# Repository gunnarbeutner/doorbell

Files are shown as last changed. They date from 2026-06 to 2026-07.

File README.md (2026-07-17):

# Doorbell controller (STR WF26-compatible)

A drop-in smart replacement for a **WF26 handset** on an **STR Elektronik TV20/S**
apartment-intercom bus, built on an ESP32-S3 running ESPHome. To the building it looks like the
handset it replaces; to Home Assistant it looks like a doorbell, an intercom and a door opener.

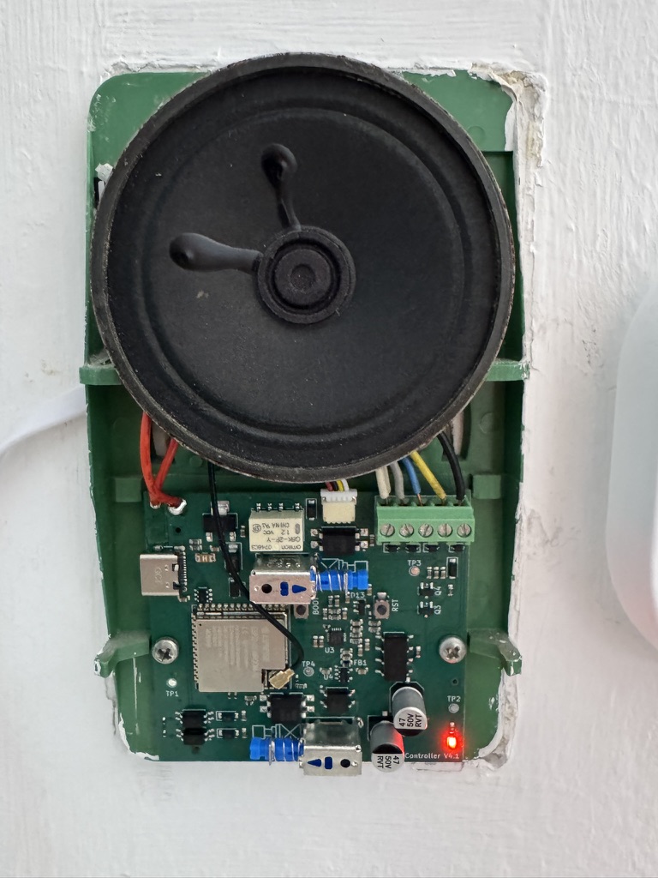
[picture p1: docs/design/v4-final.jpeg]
The doorbell controller installed in the wall


## What it does

- **Ring detection** — the front-door bell (Türruf) and the floor button (Etagenruf) are separate
  HA binary sensors and events: phone notifications, presence-aware automations, "someone rang
  while you were out" history.
- **Gong suppression** — a solid-state switch in the chime path mutes the mechanical gong under
  firmware policy (occupancy, quiet hours, do-not-disturb) without touching ring detection, the
  latch/session, codec audio or the door opener. The current interim policy holds that switch open
  for all of suppression mode so a later neighbour gong on shared line 2 cannot reach LS1; this also
  disables physical LS1 listen/talk until the PTT-capable V4.2 hardware and firmware policy are
  fabricated and validated. The switch is normally-closed: if the smart layer dies, the doorbell
  returns to the stock passive path.
- **Door opener from HA** — with the safety in hardware, not firmware: the door relay pair
  replicates the WF26's break-before-make sequence with an RC delay, and an independent hardware
  watchdog releases the door bridge after ~6.7 s no matter what the firmware does. A crashed ESP
  or a runaway automation cannot hold the door open.
- **Two-way audio** — an ES8311 codec taps the bus speech pair through a protected divider (RX)
  and drives the talk line through the same 2.2 kΩ handshake the central expects from a real
  handset (TX). Push-to-talk from HA; wired for HA's Assist voice pipeline.
- **Fully passive fallback** — the original WF26 relay/switch/speaker core is carried on the
  board, hardwired. Gong, listen, talk and door-open all work with the electronics unpowered;
  the smart layer only ever adds, never gates.
- **Local everything** — ESPHome native HA API, OTA updates, on-device web UI. No cloud.

## How the TV20/S bus works

Five wires run from the central to each flat:

| Line | Role |
|---|---|
| 1 | Common — the reference for everything below |
| 2 | Standing **+12 V supply**, current-limited (~90 Ω source), always on |
| 3 | Speech — talk audio toward the door station |
| 4 | **Türruf** — front-door ring |
| 5 | **Etagenruf** — floor-button ring |

A **ring** is the central putting ~12 V on a ring line for about a second; the gong is literally
the handset's speaker driven from that pulse through a capacitor (the floor line rings the
speaker directly). The line-4 pulse also pulls in a relay inside the handset, which **seals
itself in from line 2** and holds line 4 high — that standing level *is* the "call in progress"
state, and the supply rail sags visibly under its load. **Talk** is a 2.2 kΩ bridge from the
speech line to the supply: the central detects exactly that resistance as "off-hook" and routes
audio, which simply rides on top of the DC. The **door opener** is a plain line 2↔3 contact
closure, sequenced break-before-make so the latch drops first. The central ends every session by
sinking line 2 low after a timeout, which drops all latches. A stock handset contains no
electronics at all — a relay, capacitors, switches and a speaker.

The board senses the ring lines with optocouplers, switches its functions with PhotoMOS relays
in the same places the WF26's mechanical switches sat, and leaves the bus model untouched — the
central cannot tell the difference. The full reverse-engineering lives in `DESIGN.md`, the WF26
handset schematic in `wf26/`, and real-bus scope captures in `captures/` — all usable on their
own if you have this intercom family and only want ring detection or muting.

## Beyond the assembled board

The JLCPCB-assembled PCB needs four things it doesn't ship with:

- **Antenna** — the ESP32-S3-WROOM-**1U** has no PCB antenna; any 2.4 GHz u.FL/IPEX antenna
  works (a flex-PCB patch routes nicely out of the enclosure).
- **Speaker/mic transducer (LS1)** — a 16 Ω transducer soldered to the LS1 wire pads. It is the
  gong, the passive listen earpiece and the passive talk mic in one; deliberately not
  board-assembled.
- **JST SH-4 male pigtail for J1** (the deployed power/service inlet) — a pre-crimped SH-4 lead is strongly
  recommended; hand-crimping 1 mm SH contacts is misery.
- **USB power/service lead** — a four-signal USB-A male screw-terminal breakout wired to the J1
  pigtail. Keep D+/D− short and twisted, and verify every conductor before first power-up:
  `docs/design/usb-jst-j1-wiring.svg`.

**Status:** the V4.1 board (JLCPCB-fabbed and -assembled) is bench-verified and deployed —
installed in the wall in place of the WF26, running `firmware/doorbell.yaml`. The smart layer
is powered by a USB wall-wart through its J3 connector; the TV20/S bus powers only the passive
handset core, so the electronics draw nothing from the shared intercom supply. The installed V4.1
USB-C connector mechanically prevents the housing's Talk actuator from fully engaging SW4; the
current V4.2 candidate removes that connector and adds a dry GPIO47 physical-Talk input plus a
mechanical K1 inhibit on SW4's spare pole. Those changed circuits are not field-proven and must pass
the full actuator/cable fit and first-board electrical/timing gates.

## Repository layout

The **KiCad files** (`kicad/doorbell.kicad_sch` / `.kicad_pcb`) are the authoritative source for
the board — edited directly in KiCad. `./build.sh` verifies them and exports the
fab outputs; it does not author or regenerate the board.

| Path | What |
|---|---|
| `REQUIREMENTS.md` | *What* the board must do — functional + safety requirements (start here for intent). |
| `DESIGN.md` | *How* it's built — architecture, GPIO map, relays/SSRs, audio path, bus model. |
| `VERIFICATION.md` | Design-verification gates plus the bench bring-up / commissioning record. |
| `ORDERING.md` | JLCPCB ordering notes (Standard PCBA workflow + the review gates). |
| `kicad/` | Authoritative KiCad project (`doorbell.kicad_sch` / `.kicad_pcb`). See `kicad/README.md`. |
| `tools/` | Build/inspection Python scripts (placement check, routing verify, STEP/BOM/CPL export). |
| `firmware/` | ESPHome configs — `doorbell.yaml` (deployed), `doorbell-bench.yaml` (bench twin: debug SSR switches, audio loopback instrumentation, no HA events), `doorbell-tonegen.yaml` (spare board as bench tone source / HA media player). |
| `sim/` | Node circuit simulator + PCB viewer used to sanity-check the design (`cd sim`; `npm test`). |
| `wf26/` | Reverse-engineered WF26 handset (`wf26.kicad_sch`). |
| `captures/` | Bench scope captures of the real TV20/S (ring, door-open, timeout) + web viewer. |
| `docs/` | Datasheets and reference docs (`datasheets/`, `design/`, `ordering/`) — incl. the wall wire-up map (`design/wall-wiring-v4.svg`) and the J1 power/service-cable pinout (`design/usb-jst-j1-wiring.svg`). |
| `fab/` | Generated fab outputs (Gerbers, drill, BOM, CPL, STEP) — produced by `./build.sh`. |
| `orders/` | Shipped fabrication order archives. |

## Build

```bash
./build.sh             # verify (ERC/DRC/placement/routing/simulation) + export fab outputs
./build.sh verify      # run the same checks without updating generated artifacts
```

See `kicad/README.md` for the build pipeline details.

## Firmware

```bash
cd firmware
esphome run doorbell.yaml    # needs firmware/secrets.yaml (see below)
```

Secrets (WiFi credentials, API encryption key, OTA password) live in `firmware/secrets.yaml`,
which is gitignored — create it with `wifi_ssid`, `wifi_password`, `api_encryption_key` and
`ota_password` before building. Run `esphome clean` after switching configs or renaming a device
— a stale build directory fails the build in confusing ways.

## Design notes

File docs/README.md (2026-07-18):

# Datasheets & reference docs

Local copies of the primary sources behind the design, so the references don't rot. The
**authoritative part list is the schematic** (`kicad/doorbell.kicad_sch`, hidden `LCSC`/`MPN`
fields) exported to `fab/doorbell-bom-jlcpcb.csv` — this folder is not a BOM, just the
backing documents. For *how* to use them to check the board, see `../VERIFICATION.md`.

## Layout

- **`datasheets/`** — component datasheets for the parts on the board.
- **`design/`** — intercom/handset reference docs, ESP32 design guides, the Fritzing source.
- **`ordering/`** — JLCPCB capability PDFs and the prefab verification report.
- **`verification/`** — revision-specific bench/field evidence and review dispositions. These are
  historical records; the revision-neutral pre-fab procedure remains `../VERIFICATION.md`.

## Intercom & handset (in `design/`)

| File | What |
|---|---|
| `STR_TV20S_Schaltplan_Fehlersuchhilfe.pdf` | STR TV20/S service plan — Verdrahtungsplan + Fehlersuchhilfe. The authority for the bus (terminal 4 = Türruf ≈ 12 VDC, ÖT bridges 2 & 3, ET interrupts line 5). |
| `HJR4102.PDF` | HJR-4102 — the WF26's own latch relay (the part the on-board G6K replica reproduces). |
| `KlingelV4.fzz` | Fritzing source for the V3 perfboard build / early V4 reference. |

## Current-design part datasheets (in `datasheets/`)

For the parts on the board: the **ESP32-S3-WROOM-1U-N16R8** module (`esp32-s3-wroom-1_wroom-1u_datasheet_en.pdf`,
pad map + strapping), **ES8311** codec (`ES8311_datasheet.pdf` + `ES8311.user.Guide.pdf`),
**SGM2212** LDO (`sgm2212_datasheet.pdf`), **TPD2S017** USB ESD (`tpd2s017_datasheet.pdf`),
**Omron G6K** relay (`g6k_datasheet.pdf`), **SUPSiC GAQY412E/EH** PhotoMOS
(`GAQY412E_EH_datasheet.pdf`), the **SPPJ322300** door switch (`SPPJ322300_datasheet.pdf`), the
**AO3400A** door/watchdog FETs (`ao3400a_datasheet.pdf`), and the **LMBR01S30ST5G** codec-clamp and
AVDD reverse-blocking Schottky (`lmbr01s30st5g_datasheet.pdf`). The exact polarised crossover
capacitor is Panasonic **EEEFK1H220P** (`eeefk1h220p_datasheet.pdf`), and K5's exact flyback/clamp is
R+O / Zhuhai Hongjiacheng **1N4004W** (`1n4004w_datasheet.pdf`).

Local sheets also cover the **SS14**, **SMF5.0A**, **1N4148W**, **SM04B-SRSS-TB JST-SH** connector,
and **GAQW212GS/GAQY212GS** SSRs. Not every commodity resistor or MLCC sheet is archived; use the
exact schematic BOM/LCSC entry rather than inferring an ordered part from this directory.

`usb4105_datasheet.pdf` is retained only as historical backing for the V4.1 J1 USB-C receptacle; it
does not describe a current V4.2 part and is not a BOM source.

## Fab capability (in `ordering/`)

`PCB Manufacturing & Assembly Capabilities - JLCPCB.pdf` and `… - JLCPCB - PCBA.pdf` — JLCPCB's
published PCB/PCBA capability limits (clearances, assembly rules), the basis for the DRU and the
ordering notes in `../ORDERING.md`.

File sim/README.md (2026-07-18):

# sim — schematic-driven circuit simulator

A transient circuit simulator with a browser PCB view. It **imports** `kicad/doorbell.kicad_sch`
and **simulates each component by a type-based model**. Nothing is baked: the netlist is read from
the KiCad files on demand.

## Use

```sh
cd sim
npm run dev      # incrementally builds host firmware, then serves http://localhost:8080
npm test         # all required circuit + firmware/HEAD tests
npm run test:circuit  # circuit-only tests against the live schematic
npm run test:firmware # deterministic ESPHome-host + live-HEAD circuit co-simulation
npm run test:firmware:scenarios # fastest rerun after config/build; scenarios only
npm run check:tv20s-calibration # verify evidence hashes and captured DC envelopes
npm run test:monte-carlo -- 1592639710 250  # optional seeded watchdog sensitivity diagnostic
```

`npm run dev` must finish the incremental `doorbell-host.yaml` build before the server listens. It
re-imports automatically when a `.kicad_sch` / `.kicad_pcb` changes — just reload. Importing needs
`kicad-cli` on `PATH` (KiCad's CLI; used for net connectivity).

There is deliberately no firmware/no-firmware mode. A `doorbell` browser session always gets its own
server worker, host firmware process, virtual clock, preferences directory and live HEAD circuit.
Both `doorbell` and `wf26` default to a synthetic, capture-calibrated TV20/S terminal model; select
`manual circuit lab` when arbitrary sources and components are needed. The `wf26` board remains a
passive reference-handset circuit with no MCU in either environment. Closing an idle browser session
releases its worker and firmware process; abandoned sessions expire server-side.

The page is a 3-column PCB view: `[controls + layer toggles + time cursor] | [selected copper layers,
stacked] | [scopes]`. In the default TV20/S environment, use the own-ring, neighbour-ring, floor-call,
neighbour-door and timeout controls. The model owns P1–P5 and composes the selected endpoint with a
second live-imported WF26 endpoint for the neighbour. In the manual lab, add **Sources** (drive any net with
DC/sine/square/step/pulse — each has an on/off toggle, off = the net floats, and an editable Thevenin
source impedance). Both environments use pause, 1×, 10×, maximum-speed or the 1 ms single-step. Ideal
sources on the same net conflict, and a source attached to a firmware-owned U1/U3 output must have
non-zero impedance. **Hover**
a trace → its net's voltage; **click** a trace → a scope on the right; the time-cursor slider scrubs the
instant shown on the board and the scope cursors. Colour is by voltage (fixed 0–Vmax scale) or by net.
Inner planes (In1/In2) show vias/pads only — zone fills aren't extracted yet.

## Layout

- `src/import.js` — KiCad → netlist object (node; shells out to `kicad-cli`, parses the `.kicad_sch` /
  `.kicad_pcb`, including MPN/LCSC/datasheet fields). Replaces the old `build.py`.
- `src/engine.js` — the simulation core (MNA transient solver); shared by session workers and tests.
- `src/corners.js` — fitted-part limits, explicit engineering assumptions and named deterministic corners.
- `src/ui.js` + `index.html` — remote browser front-end; renders server samples and submits controls but
  never creates an electrical stepper or manually programs U1/U3.
- `src/session-worker.js` — isolated per-browser circuit owner, virtual-time pacer, safety monitor and
  host-process lifecycle manager. Doorbell sessions reuse the deterministic firmware-test runner;
  WF26 sessions run the same TV20/S terminal environment around their passive circuit, or the manual
  lab when selected.
- `src/tv20s/` — captured-evidence manifest, terminal-equivalent calibration and the synthetic
  TV20/S state machine. Unsupported compositions throw with the missing evidence they require.
- `server.js` — HTTP/SSE session API, live KiCad import and static dev server (`npm run dev`).
- `test/` — integration tests + model-coverage and deterministic-corner gates (`npm run test:circuit`).
- `firmware-test/` — sequential host-firmware/circuit scenarios (`npm run test:firmware`).
- `diagnostics/` — optional seeded sensitivity tools; these supplement rather than replace the
  deterministic safety gates.

## How components are modeled (by type)

Each device type is a **class in `src/components/`** (one file each: `Resistor`, `Diode`, `Mosfet`,
`Optocoupler`, `Transformer`, `Relay`, `Switch`, `SolderBridge`, `EsdArray`, `Ldo`, … + `Connector`/
`TestPoint` ports and an `Unmodeled` fallback). A class exposes:

- `static compatible(symbol)` — does this class model the part? It inspects the symbol's `lib_id`
  (library category / part name) and pin functions — **not** the reference designator. So a part is
  modeled by what it *is*, even if its refdes breaks convention (e.g. `D5`, an ESD array, is matched by
  `EsdArray`, not `Diode`).
- `elements(ctx)` — the simulation elements it contributes (with its own parameters: a diode's Is/n by
  family, a 2N7002's vth/Rds, a relay's coil R + pull-in, the transformer's L/k/Rdc, …).

The registry (`src/components/index.js`) tries the classes most-specific-first and instantiates the first
match (or `Unmodeled` → shown red). The importer no longer classifies anything; it just emits raw
components (ref, lib, value, footprint, pins, pinfn and exact-part metadata).

**Nominal device parameters are per-part** — derived from each component's part type/value:
diode Vf class by family (silicon `1N4148` ≈ 0.65 V, Schottky `SS14` ≈ 0.3–0.4 V, visible LED ≈ 1.9 V,
TVS by type: unidirectional forward-only, bidirectional anti-series with a standoff `vbr`, open across the
bus range); MOSFET `vth`/`Rds(on)` by part (`2N7002`); optocoupler LED + guaranteed CTR
(`TLP293` GB rank);
transformer winding `L`/`k`/`Rdc` by part (`SM-LP-5001`: Rdc 115 Ω); relay coil resistance, pull-in,
operate/release time and contact resistance from the fitted part.

Qualification tests may pass strict per-reference overrides to `buildElements(..., { params })`.
Every override must match a live schematic reference and a parameter that its model consumes; unknown
or misspelled values fail instead of silently running nominal. The returned element list records the
resolved nominal/override pairs in `resolvedParams` for auditability.

- **Auto-modeled from value + refdes:** R, C (including tolerance/effective-value overrides and optional
  capacitor leakage; polarized caps, `Device:C_Polarized` etc., are flagged in the
  status bar if they're ever reverse-biased — pin 1 = +), L, diode (KiCad `Device:D`: pin 1 = cathode, pin 2 = anode),
  speaker (→ R), fitted 0466 fuse (→ 75 mΩ + 0.0423 A²s melting model whose blown state remains
  latched across seeded scenario changes), **optocoupler** (standard 4-pin: LED diode 1→2 + CTR/dark-current source
  4→3 with a saturation clamp), **MOSFET/transistor** (gate-controlled switch, using the symbol's
  `G/D/S` pin functions), **regulator/LDO** (an IC with `VIN/VOUT/GND` pin functions → regulated
  output, floored at 0; target voltage parsed from the output net name, e.g. `+3V3` → 3.3 V; draws its
  output current back out of the input pin so the input rail loads down rather than supplying free power,
  and operates as a one-quadrant source only while VIN has dropout headroom — it neither back-drives a
  dead input nor sinks an externally overdriven output; pull the supply and the board de-energizes
  instead of running forever off a charged cap), **transformer** (two coupled inductors + series winding Rdc),
  **ESD/TVS protection array** (e.g. `TPD2S017`: each channel passes IN↔OUT, with steering diodes that
  clamp the line to VCC/GND and a ~6 V VCC↔GND rail clamp — so a realistic surge through a source
  impedance clamps to ≈ VCC + Vf; an ideal 0 Ω source can't be clamped, as in reality).
- **Relays & switches** — pin-outs are **hard-coded per part type** (keyed on the symbol `lib_id`):
  Omron `G6K-2F` relay → coil 1/8, contacts COM3/NC2/NO4 + COM6/NC7/NO5; `SPPJ322300` DPDT switch →
  COM2/NC3/NO1 + COM5/NC6/NO4; tactile button → SPST 1–2; **solder bridges** (`SolderJumper`) → SPST,
  closed by default. **Relays are coil-driven** (energized when |V_coil| ≥ ~75 % of the rated coil
  voltage, with datasheet operate/release delay — drive the coil/gate to trigger; read-only state badge).
  **PhotoMOS outputs likewise use operate/recovery current and voltage hysteresis plus switching delay.**
  **Switches & solder bridges** toggle
  manually. No configuration UI.
- **ICs (ESP32, codec) — supply current (+ codec VMID):** generic digital I/O (I2S, USB and internal
  behavior) is **not** modeled, so they still render **red**; but their power draw
  *is* — each is an equivalent resistive load (`Ic`) from its supply pin to GND at a representative active
  current (ESP32 ~100 mA, ES8311 ~10 mA), which pulls through the LDO → +5V → Schottky → VBUS. The one
  analog exception: the ES8311's **VMID reference** (≈ AVDD/2) is modeled, because the mic front-end's
  divider/bias depends on it. In a doorbell session the host firmware exclusively supplies U1's four
  modeled output drivers and U3's bounded representative codec output; there are no manual IC controls.
- **Floating vs 0 V:** nets with no DC-conductive path to ground or a source are flagged **floating**
  (dashed grey on the board, "(floating)" in the tooltip) — distinct from a real 0 V net.

## Engine

Modified Nodal Analysis, Backward-Euler transient, Newton iteration (SPICE-style relative+absolute
convergence with damping for the per-part diode/opto models, all in `src/engine.js` (no DOM, importable
by the tests). A nonlinear solve that exhausts its iteration limit throws with the time, worst node and
voltage delta; it is never silently accepted. `src/import.js` produces the netlist; `src/ui.js` is the
browser front-end.

## Qualification corners

`src/corners.js` separates guaranteed fitted-part limits from named engineering bounds. Permanent tests
cover the watchdog fast/nominal/slow envelope, break-before-make timing, PhotoMOS drive and switching
delay, K5/K6 interlock and GPIO pin faults, powered boot/brownout fallback, dynamic fuse isolation,
bounded bus faults, LDO passivity, optocoupler CTR/dark current, the supply monitor, RX/TX voice-band
gain, captured-waveform replay, the welded-K1 door discriminator, timestep refinement and convergence
failure. The compact replay fixtures under `test-support/fixtures/` record the exact source capture and time
window from which they were decimated. The timing-MLCC 0.65–1.10 effective-capacitance scale
and the K6 temperature guard are explicitly labelled engineering assumptions because the vendors expose
typical curves rather than guaranteed production extrema.

`npm run test:monte-carlo -- <seed> <samples>` explores uniformly sampled interior watchdog values and
prints its seed plus fastest/slowest samples. It must stay inside the deterministic extremes, but it is a
diagnostic only: reproducible named extremes, not random coverage, are the release gate.

## Scope / limits

Validates **design intent and the explicitly modeled fitted-part envelope** — loading/impedance, RC time
constants, sense thresholds and switch topology. The TV20/S environment additionally reproduces the
captured idle/session/timeout terminal bias, own and one-neighbour ring/gong, floor call, direct door
bridge and recovery. A direct door bridge during the local endpoint's own gong composes those same
calibrated terminal equivalents, allowing the production auto-open timing to run without a special
DUT assumption. The documented 2.2 kΩ Talk handshake is supported as a terminal state, but the
TV20/S audio gain and remote acoustic path are not synthesized. It deliberately rejects other
intermediate P2–P3 impedances, multiple neighbours, overlapping bell types, door actions during a
neighbour/foreign gong and central-unit/opener-terminal faults; those need new evidence, not guessed
behavior. During stock WF26
Talk, `R1_BRIDGE` is connected to P3 on the low side of R1, so the terminal-equivalent model puts it
near 1 V while P4 retains the approximately 9.4 V session bias. This is not the main board's
`TALK_BRIDGE`: K1 holds that node directly at P2, with `TX_OUT`/P3 on the low side of R28. It still
does not predict semiconductor analog behavior
with SPICE precision, derive unguaranteed temperature/DC-bias distributions, model EMI, contact bounce,
PCB parasitics or fabrication variation. Seeded sampling cannot turn an engineering bound into a vendor
guarantee; first-board measurements remain required where `VERIFICATION.md` says so.

## Firmware/HEAD co-simulation

`./build.sh firmware-test` is the narrow firmware gate. It resolves the production and bench YAML,
incrementally builds `firmware/doorbell-host.yaml`, then starts a fresh host process, Unix socket and
preferences directory for every scenario. Production remains the installed V4.1 adapter; the host
adapter enables the expected HEAD/V4.2 K5-confirmed P4 isolation, physical-Talk hand-off and serialized
door-command/re-arm policy. Its candidate manual-conversation policy keeps K3 passive for up to 30 s
after physical-Talk release while K5 remains confirmed; K5 loss, smart TX or a door request ends that
window sooner. These behaviors are gating host scenarios without claiming that the changed functions
have passed fabricated-board tests.

The live KiCad import and passive powered-state operating point are cached only within one Node test process;
every scenario still gets a fresh firmware process, socket, preferences directory and independent copy
of the settled electrical state. The runner solves the DC target directly (capacitors open, inductors at
DC, discrete devices iterated to a stable topology), follows topology and waveform transients at
fine/medium/coarse steps, and jumps an interval only when live storage and discrete state agree with that
operating point within the solver tolerances. Numerical step horizons select resolution; they do not
declare a static circuit settled. The deliberately bounded representative codec waveform remains a
separate policy-test abstraction; after its documented exercise window, the remaining media duration
advances as policy-only time. Long greetings and timeout tests therefore retain virtual-time coverage
without repeatedly solving an unchanged nonlinear circuit.

`npm run test:firmware` remains the self-contained direct gate: it resolves production/bench and
incrementally builds the host target. After those inputs are already known-good, use
`npm run test:firmware:scenarios` for the shortest edit/rerun loop; `./build.sh firmware-test` performs
the validation/build itself and then uses that scenarios-only command, avoiding duplicate work.

The host binary replaces the stock host wall-clock and wake HAL with a 64-bit simulator-controlled
clock. `millis()` intentionally exposes its low 32 bits. Firmware and circuit exchange protocol-v1
newline messages over the per-test socket: firmware sends `HELLO`, ordered `WRITE`, `MEDIA`, `EMIT`
and `ADVANCE`; the runner replies with `AT` containing virtual time, raw input mask, ADC millivolts,
stop reason and queued commands. A version/mapping error, nonlinear-solver failure or stable voltage
in the ESP32 indeterminate region fails the scenario. Short analog transitions retain the previous
Schmitt state for at most 20 ms; remaining in the undefined band after that fails with net and voltage.

The runner imports `kicad/doorbell.kicad_sch` at runtime and checks U1 plus P1–P5 during handshake.
P2/P4/P5 DC, tone, pulse and captured-waveform sources use the measured nominal 90 Ω source
impedance. It carries capacitor, relay, SSR,
fuse and regulator state across adaptive timestep rebuilds, uses fine steps around topology/input
edges, and retries a hard source/clamp transition on a bounded smaller-timestep ladder before reporting
strict nonlinear non-convergence. A non-interactive host exit can remove U1 program drivers to model
reset/power loss. The fake media player derives duration
from each embedded WAV's actual metadata and drives U3 with a bounded representative tone while it is
active. Failures print a compact ordered timeline; detailed exploratory traces are not committed.

This fixture validates the electrical contract at the connector and firmware-observable HEAD nets. Its
TV20/S terminal model is tied to the named capture files and their recorded channel confidence; it is
not a model of unobserved central-unit internals, a substitute for the remaining real-bus checks, or
validation of a fabricated V4.2 board.

### Interactive virtual time

The interactive UI uses the same protocol and HEAD fixture. The server is the sole authority for
circuit state and ordered firmware writes. At 1×/10× it advances a wall-time-derived virtual horizon;
`max` advances bounded chunks as quickly as the solver and host scheduler permit. Pause leaves the
host blocked in `ADVANCE`, and `+1 ms` advances exactly one virtual millisecond. Firmware commands,
TV20/S stimuli and circuit/source edits made while paused are queued at the frozen boundary; repeated
lab-circuit edits collapse to the final configuration and are applied only by `+1 ms` or resume. Until
then the complete published snapshot—including voltages, storage state, environment state and floating
classification—remains unchanged. Full reset starts a clean circuit, host and preferences set.
**Freeze firmware** stops host execution while retaining the last U1/U3 GPIO and peripheral drive,
modeling a wedged MCU. The physical circuit continues in virtual time: in particular, a frozen-high
`DOOR_DRV` remains high while the independent Q3/RC watchdog releases K2. Reboot resets the program
outputs and starts a new host process at the same circuit time without resetting capacitor, relay, SSR
or fuse state.

Every source, extra element and switch edit is validated in the worker and rebuilt at its permitted
virtual-time boundary while carrying physical state. HTTP action completion acknowledges worker
completion, so pause/configure ordering does not depend on wall-clock timing. Samples, current injections,
safety events, firmware entities, media ownership and the ordered write timeline stream back over SSE.
The UI keeps a bounded display window; detailed deterministic assertions remain the job of
`npm run test:firmware`.

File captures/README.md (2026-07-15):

# captures — Rigol DHO804 capture tooling

Pull waveforms off the bench scope (`osci.beutner.name`) over WiFi and save them — one
**CSV (full true voltages) + WAV (extracted audio) per channel** — so the 3-Klang-Gong
on the bus (and anything else) can be analyzed and listened to.

Built on **[pydho800](https://github.com/MasterJubei/pydho800)** / `pylabdevs`, which talks
to the scope over its raw SCPI socket (:5555) and frames reads/writes reliably. (An earlier
hand-rolled SCPI version hit persistent socket desync and config writes that wouldn't land
on this unit; pydho800 fixed both, so the custom layer was dropped.)

## Analysis UI

For an interactive alternative to the static `preview.png` overviews — play the audio, zoom into events,
read true voltages, measure with cursors, and view the gong spectrum/spectrogram — run the web
viewer in [`viewer/`](viewer/) (`cd viewer && npm start` → http://localhost:8137). It decompresses
the `.csv.zst` on the fly and has no dependencies. See [`viewer/README.md`](viewer/README.md).

## Setup

For the exact bench wiring, trigger, MAIN/non-ROLL, pre-trigger timing and recovery procedure used for
welcome-audio onset captures, see [`DHO804-SETUP.md`](DHO804-SETUP.md).

```sh
cd captures
python3 -m venv .venv
.venv/bin/pip install -r requirements.txt
```

## Use

```sh
# grab whatever is currently in the scope's memory (STOP + read):
.venv/bin/python capture.py --now --channels 1,2,3 --out grab

# set a ~60 s window, run, and record a session on the P2 line:
.venv/bin/python capture.py --record 60 --channels 2 --mem M_1M --out session

# all three bus lines in parallel, 10x probes (the default):
.venv/bin/python capture.py --now --channels 1,2,3 --out bus

# the displayed time window at full sample density (STOPs, reads memory, trims to the screen):
.venv/bin/python capture.py --screen --channels 1,2,3 --out screen
```

Each run writes `runs/<out>/ch<n>.{csv,wav}` per channel, plus one overview image `runs/<out>/preview.png`
(**DC baseline + AC component per channel**, shared time axis — use `--no-plot` to skip) and a
`runs/<out>/meta.json` sidecar (capture timestamp + acquisition params), and prints sample count, rate, Vpp,
and the dominant chime tones. Channels are read from a single acquisition, so they're **time-aligned**.

> **Filenames carry no timestamp** — pick a unique, descriptive `--out` per capture (e.g.
> `our-ring-door-open`, `door-open-standalone`). The capture date lives in `meta.json`
> (`captured_at`, ISO 8601), which the viewer reads for its date label and sort; it survives a clone,
> unlike the file mtime.

> **Storage:** raw `.csv` dumps are large (a 180 s, 25 kSa/s capture is ~135 MB/channel, over
> GitHub's 100 MB limit), so the repo tracks the **zstd-compressed `*.csv.zst`** (`zstd --ultra -22`,
> ~4–6× smaller) rather than the raw `.csv`. Compress before committing (`cd runs/<name> && zstd --ultra -22 *.csv`)
> and read back with `zstd -dc file.csv.zst` (or `zstdcat`). The `.wav`, `preview.png`, `meta.json`, and
> per-session `notes.md` are committed uncompressed.

## Modes & options

- **`--now`** — `:STOP` then read the current deep memory.
- **`--record N`** — set a window of ~N seconds (`--divs` is the scope's horizontal
  division count, default 10; the actual window is reported), `:RUN`, wait, `:STOP`, read.
- **`--screen`** — the **displayed time window at full sample density**. `:STOP`, read the deep
  memory (RAW), then trim to the on-screen span — the span is found from a NORMAL-mode read
  (`points × xinc`), so it self-adapts to the current timebase with no hardcoded division count.
  However many samples fall in that window (a few hundred at a fast timebase, millions at a slow
  one). **Requires `:STOP`** — per-sample data only exists in frozen memory. Give exactly one of
  `--now` / `--record` / `--screen`.
- **`--channels 1,2,3`** — 1-based; read in parallel.
- **`--probe 10`** — probe attenuation ratio set on each channel (default 10x).
- **`--mem AUTO|M_1K..M_50M`** — memory depth (default AUTO).
- **Audio extraction:** `--skip-silence`/`--no-skip-silence`, `--min-vpp`,
  `--silence-threshold`, `--hp-ms`, `--pad-ms`, `--min-active-ms`
  (DC-removal high-pass → peak-normalized WAV; idle channels skipped).

## How the audio extraction works

- **DC removal** — a moving-average high-pass strips the line's DC pedestal.
- **WAV = full record by default** — every sample is written (DC-removed, peak-normalized), so
  the timeline is intact. Pass **`--skip-silence`** to instead gate the WAV down to the active
  stretches (AC clearing both a fraction of the peak and the noise floor, ≥ `--min-active-ms`,
  padded by `--pad-ms`).
- **Tone ID** — dominant frequencies from the clean interior of the loudest burst, 80 Hz–5 kHz.
  This always runs on the gated burst (for analysis) regardless of what the WAV contains.

The CSV is always the full, ungated true-voltage record.

## Notes

- Waveform reads come back as **ASCII** (pydho800's format), which is reliable but bulky —
  a multi-megapoint deep read is tens of MB and slow over WiFi. For audio, a modest memory
  depth (`--mem M_1M`) over the window is plenty; keep channel count to what you need.
- The old software-trigger **watch** loop was dropped with the hand-rolled SCPI layer. It can
  be re-added on pydho800 (poll `get_channel_measurement`, then STOP/read) if you want
  continuous event logging again.

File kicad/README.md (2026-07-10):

# Doorbell controller — KiCad project

## Build pipeline (verify + fab; the KiCad files are authoritative)

`doorbell.kicad_sch` / `doorbell.kicad_pcb` are the authoritative source — edit them in
KiCad. `build.sh` never authors copper; it runs the checks KiCad's own DRC/ERC can't
express and exports the fab outputs:

```
./build.sh              # verify + all order-ready exports (full release)
./build.sh verify       # ERC + placement + PCB/DRC + simulation; no exports
./build.sh schematic    # schematic ERC + PDF export
./build.sh pcb          # placement + planes/thieving/connectivity + DRC
./build.sh simulation   # circuit-simulator tests
./build.sh fabrication  # Gerbers + drill + position + BOM -> fab/
./build.sh step         # populated STEP model
./build.sh board-step   # bare-board STEP model
```

| Script | Interpreter | Role |
|---|---|---|
| `tools/check_pcb.py` | KiCad bundled python (pcbnew) | verify placement (edge flush/overhang, parts inside outline) |
| `tools/route.py` | KiCad bundled python (pcbnew) | refill zones + verify connectivity + copper-thieving sliver limit |
| `tools/jlcpcb_cpl.py` | KiCad bundled python (pcbnew) | JLCPCB CPL (pad-centroid positions) |
| `tools/jlcpcb_files.py` | `.venv/bin/python` (kiutils) | JLCPCB BOM (from the schematic) |

`tools/doorbell_design.py` holds the placement constants `check_pcb.py` verifies — connector edge
fit/overhang and the mounting-hole MLCC keep-out; the KiCad files are authoritative for the rest.
The board is hand-routed **in KiCad**;
`route.py` fails the build on any unrouted connection or any copper-thieving float island
over the sliver limit (≥ 2 mm² or ≥ 10 mm) — fix those in KiCad, never with a tool.

> 4-layer, ~64 × 59 mm; `tools/check_pcb.py` gates placement (the edge connectors J1/J2/J3 and U1
> sit flush on their board edges).

## Where the rest lives (deliberately not duplicated here)

This README is only the build/verify/fab process. Everything else stays in its authoritative
source so it can't drift out of sync — so there is **no part list, net list, or pin table here**:

- **Parts / values / footprints / LCSC numbers** — in the schematic (hidden `LCSC`/`MPN`/`Footprint`
  fields); exported to `fab/doorbell-bom-jlcpcb.csv` by `build.sh fabrication`.
- **Net connectivity and pin assignments** — `doorbell.kicad_sch` (open it, or
  `kicad-cli sch export netlist`).
- **Architecture, pin map, relays/SSRs, audio path, power, isolation, layout** — `../DESIGN.md`;
  the requirements it satisfies — `../REQUIREMENTS.md`; ordering — `../ORDERING.md`.

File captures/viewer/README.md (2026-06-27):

# captures viewer — interactive scope-recording analysis UI

A local web app for the `captures/runs/` recordings: play the audio, zoom into events, read true
voltages, measure with cursors, and see the gong tones — a live alternative to the static
`preview.png` overviews.

## Run

```sh
cd captures/viewer
npm start            # or: npm run dev   → http://localhost:8137
```

No dependencies — `npm install` is a no-op. It uses only Node built-ins (`http`, `zlib`'s
**native zstd**) plus a vanilla-JS canvas frontend. Needs Node ≥ 23 (for `node:zlib` zstd; tested
on v26). Override the port with `PORT=…`, or the data dir with `CAPTURES_DIR=…` (defaults to `../`).

## What it does

- **Recording dropdown** — every recording in `captures/runs/` (one subdir per recording, newest first).
- **Stacked channels** sharing one time axis, auto-scaled per channel. Bus-pin labels
  (P4/P2/P3, plus P5 on the 4-channel recordings; editable — double-click a channel chip;
  persisted per recording in `localStorage`). The viewer adapts to however many channels a
  recording has.
- **Zoom / pan** — drag a region to zoom, wheel to zoom about the pointer, shift-wheel or
  alt-drag to pan, double-click / `0` to fit. The server ships a **min/max envelope** (so
  transients aren't aliased away) and switches to **raw samples** once you're zoomed in past
  ~1 sample/pixel.
- **Audio** — Web Audio playback of a channel's WAV with a playhead synced to the time axis.
  Play all (`space`), from cursor A (`c`), or just the visible window (`w`); pick the listen
  channel with `1`–`4` (CH number). (The WAV is DC-removed, peak-normalized AC, so it's audible.)
- **Event timeline** — a strip under the channels, with a clickable side-panel list (click any
  event to zoom to it; toggle the strip with `e`). Two modes:
  - **High-level** (default) — the reconstructed intercom protocol: *our ring* vs a *neighbour's*,
    the *3-Klang gong* with its descending tones, the *apartment ring (Etagenruf)* — a floor-call
    tone on P5 (only on the 4-channel recordings) — the *session* (seal-in → held span → release,
    classified as **door-open** vs **no-answer/timeout**), *door-open* (ÖT during a call · during a
    neighbour's call · standalone), the *P2-recovery* ramp, and *talk/listen* speech activity. Built
    by combining the primitives with the bus pin roles (P4 = our Türruf, P2 = shared listen + latch
    supply, P3 = talk + door-bridge, P5 = Etagenruf). The Etagenruf couples through the handset's C1
    onto P4, so detecting it from P5 also stops that coupling reading as a phantom neighbour ring.
  - **Raw** — the underlying primitives: every DC-level **edge** and AC **tone burst** per channel.
- **Cursors** — click = A, shift-click = B; readout shows Δt, 1/Δt (Hz), and per-channel ΔV.
- **Spectrum** — line **FFT** (`f`) or **spectrogram** (`s`) of the listen channel's AC over the
  active region (cursors A–B, else the visible window). The 3-Klang gong reads ~1010/3032 Hz.
- **AC/DC** toggle (`d`), the recording's `notes.md` note (rendered), and the legacy `preview.png` for
  reference.

## How it works

`server.js` routes a small API; `src-server/` does the work:

- `recordings.js` — scan/group files. `csvstore.js` — decode `.csv.zst` (native zstd) and parse
  to a `Float32Array` of true voltages + `{t0, dt}` (uniform time axis → time is implicit).
- `cache.js` — in-memory LRU (256 MB, `OSCI_CACHE_MB`) plus an on-disk binary cache
  (`.cache/*.f32`, gitignored, keyed on source mtime) so the multi-second first parse of a
  multi-million-row recording is paid **once**.
- `decimate.js` / `binio.js` — `GET /api/samples` returns min/max-envelope (or raw) blocks as a
  compact binary body + an `X-Osci-Meta` header. `wav.js` — range-served WAV for seeking.
- `events.js` / `highlevel.js` — `GET /api/events` returns both layers: **primitives** (level
  **edges** = steps in a coarse per-block DC track; tone **bursts** = a *relative* rise of the AC
  envelope above each line's own baseline, so a permanently-noisy high-Z line like P3 isn't mistaken
  for a tone) and **high-level** semantic events (`highlevel.js`), which combine those with the bus
  pin roles into ring/session/door/speech events. `fft.js` does per-burst gong tone-ID.

Frontend modules under `public/js/` (`scope`, `interactions`, `audio`, `fft`, `spectrogram`,
`notes`, …) are plain ESM; the renderer is a custom canvas.

`npm test` runs `node --test` (decimation bucket math, binary framing, CSV parse).

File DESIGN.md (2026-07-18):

# Doorbell controller — design reference

**What the board must do is in [`REQUIREMENTS.md`](REQUIREMENTS.md); this doc is *how* it does it.**
When the design changes in a way that affects behaviour, update REQUIREMENTS.md too.

**V4 source of truth: the KiCad files** (`kicad/doorbell.kicad_sch` / `kicad/doorbell.kicad_pcb`),
edited directly in KiCad. `./build.sh` verifies them — the checks KiCad's own DRC/ERC
can't express (connectivity + the copper-thieving sliver limit in `route.py`, placement in
`check_pcb.py`) — and exports the fab outputs; it does not generate the board.
`tools/doorbell_design.py` holds the placement constants `check_pcb.py` verifies (connector edge
fit, mounting-hole MLCC keep-out); the KiCad files are authoritative for everything else.
Firmware: `firmware/doorbell.yaml`. LCSC part numbers live in the schematic symbols as hidden
`LCSC`/`Description`/`MPN`/`Datasheet` fields (the JLCPCB library symbols carry most; the rest are
set by hand) and `tools/jlcpcb_files.py` reads them from the schematic for the BOM.
Ordering: `ORDERING.md`. Reverse-engineered handset: `wf26/wf26.kicad_sch`.
Intercom system reference: `docs/design/STR_TV20S_Schaltplan_Fehlersuchhilfe.pdf`;
central-unit photo: `docs/design/tv20s-board.jpg`.

V3 — the retired perfboard predecessor, superseded in the wall by V4 — is documented in its
own section below (source: `docs/design/KlingelV4.fzz` Fritzing schematic).

---

## System context

This is an interface board between an **STR TV20/S intercom system** and Home Assistant
(via ESPHome on an ESP32). The TV20/S is a 5-wire intercom bus powered by an NTR201
transformer (230 V → 12 VAC). This board is the electronics of the apartment handset: it combines
the passive WF26 circuit with the smart interface, so normal handset operation survives without power.

```
[NTR201 transformer]──12VAC──[TV20/S central unit]──5-wire bus──[this endpoint + other handsets]
                                      │
                                      └──8-12VAC, 1A max──[Türöffner / door opener]
```

The board taps the 5-wire bus (P1–P5) to:
1. **Sense** when bells are rung (lines 4 and 5 carry ~12 VDC bell signals)
2. **Trigger the door opener** by simulating the ÖT button press (bridge P2↔P3)
3. **Suppress the front-door (Türruf) chime** by opening the gong's coupling cap C1 (line 4 → speaker)
   — *without* breaking line 4 or the session, and *without* touching the apartment-door (Etagenruf)
   gong, which stays audible in every state
4. **Half-duplex audio**: an ES8311 codec taps the bus **speech pair** — RX a differential sense of
   line 2 (P2↔P1), TX driving line 3 (P3) through a DC-block + 2.2 kΩ gated by K1, with the talk
   handshake sourced from P2 through the restored V4.1 R28 path. V4.2 prevents own-ring bleed by
   isolating raw P4 from the internal K5 latch node after the relay has pulled in. No isolation
   transformer; **P1 is bonded to board GND**.

The board never touches the 8–12 VAC door-opener current — switched entirely inside the TV20/S. The
bus carries only low-voltage signalling (≤12 VDC, mA-level): the three ESP-driven switches (talk,
door, chime-mute) are **PhotoMOS SSRs**; the one electromechanical part is the **passive WF26 latch
relay**, which the bus drives itself (so it works with the board dead).

---

## WF26 connector

J2 is one 5-way, 3.5 mm-pitch screw terminal, pins 1–5 = P1–P5. A screw clamp reliably accepts the
handset's fine stranded cable and preserves the original terminal order. J2.4 is raw **P4**. K6,
a normally-closed PhotoMOS, connects it to the internal **K5_LATCH** node used by the latch coil,
seal-in contact and manual-Talk resistor. Chime suppression still opens only the raw-P4 gong-capacitor
path. The exact orderable connector is maintained in the schematic and `ORDERING.md`.

### Pin functions (confirmed from TV20/S Verdrahtungsplan)

| Line | TV20/S role | Role in our circuit |
|---|---|---|
| **P1** (= board GND) | Common reference (all bell/speech ref to line 1) | Bonded to board GND; opto LED returns (each via 5.1 kΩ to P1); the codec RX/TX reference |
| **P2** | Listen leg; ÖT pair with line 3 | **K2** door bridge (to P3); **RX tap** (P2 → C16 → codec ADC); SW3; the **P2 supply** that seals the WF26 latch in; the 200 kΩ TX precharge path (`P2 → JP3 → R38 → R39 → TALK_BRIDGE`). **Idles at +12 V vs P1** — a continuous standing bus rail (`captures/runs/`: 12.06–12.11 V at rest), sagging to ~9.4 V under the seal-in load during a session and momentarily to ~2.6 V at session-end before snapping back |
| **P3** | Talk leg; ÖT pair with line 2 | **K2** door bridge (from P2); **TX inject** (`OUTP → R26 → C14 → TALK_BRIDGE → R28 → TX_OUT → K1-ch2 → P3`); WF26 talk/door switches |
| **P4** | Türruf — ~12 VDC front-door gong + tone | **OC1** sense; **K3** chime-mute (P4↔C1); **K6** normally-closed bridge to `K5_LATCH` |
| **P5** | Etagenruf — apartment/floor call (tone) | **OC2** sense; **LS1** speaker (P5↔GND); C19 (the gong cap, P4↔P5) |

**Door opener (K2, SSR).** Energising K2 bridges **P2↔P3 directly** (a dead short, no series R) →
the TV20/S reads the ÖT and fires the opener. **Chime suppress (K3, NC SSR).** K3 sits in the gong's
**audio path** — between line 4 and the coupling cap C1 (K3: P4↔CHIME_POS, then C1: CHIME_POS↔P5). At
rest (de-energised) it is closed, so the Türruf gong reaches the speaker and OC1 senses line 4;
energised it opens, muting the gong **without touching line 4, the latch, or the Etagenruf** (which
reaches LS1 directly on line 5, bypassing C1).

**Door-open mirrors S1 — break-before-make in hardware (DOOR-4 / MODE-3 / BUS-2 c).** A door-open must end the
session exactly as the handset button does: drop the K5 latch. The handset's **S1 is a DPDT
*transfer*** — it lifts P2 off K1_COM (breaking the seal-in) just *before* it bridges P2↔P3, so the
latch drops as the opener fires and the live Türruf on line 4 never reaches line 3. K2 alone (a plain
P2↔P3 short) can't do that — it would leave the latch sealed and bridge `P4 → K5 → P2 → K2 → P3`,
injecting the ring (12 V DC + gong AC) onto the talk line. **Bus-confirmed both ways:** a *handset*
door-open ends the call within ~1.5 s (`captures/runs/neighbour-ring-door-open`), whereas a bare P2↔P3 relay
short (the V3 controller, API-triggered during a live session) leaves the latch **sealed for ~51 s**
(`captures/runs/door-open-call-held`) — exactly the "K2-alone leaves it sealed" case this transfer exists to avoid.
So the board reproduces S1's transfer with
two extra parts, both on the **DOOR_DRV** gate:

- **K4** (normally-closed PhotoMOS) sits **in series in the seal-in** (`SW3.6 → K4 → K5.3`, in the
  `P2 → K1_COM` path). Energised it **opens** → the seal-in breaks → K5 drops. At rest it's closed,
  so the passive/unpowered latch is untouched (MODE-1 / SAFE-4).
- **The break leads the make.** K4's LED is driven straight off DOOR_DRV (opens immediately), while K2's
  LED returns to ground through **Q3**, a logic-level N-FET whose gate (DELAY_GATE) ramps on
  **R17 (100 kΩ) · C18 (1 µF) ≈ 38 ms** — so K2 closes after K4. The fitted-part deterministic
  corner gate includes resistor tolerance, the effective-capacitance bound, AO3400A threshold/leakage,
  GPIO drive and the opposing PhotoMOS switching-time limits; it requires ≥12 ms break lead and a
  K2 make by 75 ms (current extremes are ~13.1 ms lead and ~70.7 ms latest make), well past the ~6 ms
  latch drop. The V4.1 emulated-bus bench test measured
  approximately **33–34 ms** from P4 falling (K5 released) to P3 rising (K2 made), with no premature
  P3 pulse; see the [scope capture](docs/scope/door-break-before-make.png). One gate (DOOR_DRV),
  hardware-timed break-before-make; the firmware just pulses the door line.

With the seal-in broken before P2↔P3 closes, the held Türruf is never bridged onto line 3. The
firmware's 1.75 s **minimum ring-to-open deadline remains intentional** regardless of greeting
selection: it gives the visitor time to reach the door before the latch releases, while a greeting
that runs longer completes before the opener. It is separate from V4.1's 1.45 s ring-to-audio
`welcome_not_before_ms` guard, which covers the measured door-station startup suppression and keeps
V4.1's unfiltered TX handshake away from the initial gong. The audio guard can be retired only after
K6 isolation is validated on fabricated V4.2 hardware. Boot/idle: DOOR_DRV low ⇒
Q3 off (K2 open) and K4 LED off (K4
closed) ⇒ fail-safe (SAFE-6).

**Door-open watchdog (DOOR-5).** Q4, R25, C20 and D11 form a hardware one-shot that releases K2 even
if firmware leaves DOOR_DRV asserted. Its deliberately loose RC/FET threshold range starts after the
normal 1.75 s pulse and bounds a stuck command to seconds rather than indefinitely. The deterministic
qualification window is 2.0–35 s; the fitted-part model currently resolves ~2.47 s fast, ~10.1 s
nominal and ~32.4 s slow. The extremes include 1% R25, a 0.65–1.10 effective C20 scale, the complete
AO3400A Vgs(th) and gate-leakage limits, and the SGM2212/GPIO drive model. The capacitance scale is a
conservative engineering bound because the exact Samsung X5R part's public DC-bias/temperature curves
are typical, not a production minimum. D11 quickly
re-arms it when the command drops. K4 may remain open during such a fault, which only keeps the
session latch released. Simulation covers the timing envelope, and the deployed V4.1 board released
the opener after roughly 6–7 s when deliberately held on. After a 250 ms DOOR_DRV-low interval, a
retrigger reproduced the normal break-before-make sequence and held P3 at 12 V for approximately
5.7–5.8 s before the watchdog released it; see the
[scope capture](docs/scope/door-watchdog-rearm-250ms.png). This proves functional re-arm of the
external door path. A 500 ms repeat produced the same approximately 5.8 s interval, validating the
required future firmware minimum with margin. The current production output button does not yet
enforce that off-time; the coordinator work is tracked in `TODO.md`.

> **Line 4 carries the Türruf** on raw PCB net **P4**. Normally-closed K6 passes it to **K5_LATCH**,
> the internal junction of R29, the K5 coil and its NO contact. The ring's **DC energises the
> coil** (coil = P1↔K5_LATCH — a ~1 s TV20/S pulse, then sealed in from P2), and its **AC
> tone reaches the speaker via C1** (P4↔P5 → LS1 = the gong). **Talk** is a 2.2 kΩ bridge of **line
> 4↔line 3** (S2 + R29); **listen** routes line 2 → K5 → K5_LATCH → K6 → P4 → C1 → speaker. **Chime suppression
> opens C1** (K3, NC, in the P4↔C1 path) so the Türruf tone never reaches the speaker — line 4, the
> latch and the Etagenruf are untouched. Once K5 is confirmed, firmware may open K6 during smart TX
> to keep the raw gong off the latched P2 handshake. There is no local tone generator; the chime *is*
> the audio on line 4. See "WF26 internal circuit" below.

### Wire colour map (existing flat Ethernet cable, confirmed)

| Colour | J2 pin |
|---|---|
| Orange | P1 — J2.1 |
| Green | P2 — J2.2 |
| Blue/white stripe | P3 — J2.3 |
| Blue | P4 (line 4, Türruf) — J2.4 |
| Black | P5 — J2.5 |

> All five WF26 bus wires land directly on the one 5-way **J2** (P1–P5 = pins 1–5), with **no jumper**,
> since line 4 is a single net now (chime-suppress no longer breaks it; see "WF26 connector").

---

## TV20/S reference facts (confirmed from the STR PDF)

From `docs/design/STR_TV20S_Schaltplan_Fehlersuchhilfe.pdf` (*Verdrahtungsplan* + *Fehlersuchhilfe*):

- **Power:** NTR201 transformer, 230 V~ → **12 VAC**; feeds the TV20/S control unit.
- **Door opener:** the TV20/S switches a separate 8–12 VAC supply on terminals 8/9. This board only
  requests an open through the low-current bus and never carries opener current.
- **Bell signals:** Türruf (house door) ≈ **12 VDC nominal across terminals 4 & 1** (measured
  ~10 V at the bus); Etagenruf (floor call) measured across **5 & 1**. Line **1 is the common**
  reference. The TV20/S pulses P4 long enough to pull in the handset relay; the handset then seals it
  from the standing P2 supply, keeping P4 high for the session. A genuine door press breaks that
  seal-in before bridging P2↔P3. The inactivity timeout instead pulses P2 low. Both paths drop P4,
  so OC1 provides an edge-to-edge session signal.
- **Tones:** Türruf = **3-Klang-Gong** (3-chime) — the gong is an **AC tone superimposed on the
  line-4 DC pedestal at the *start*** of the window; once the chime finishes, line 4 holds
  **steady DC** for the remainder. The measured three-strike tone lasts about 3.9 s; detailed
  spectral evidence lives under `captures/runs/our-ring-no-door/`. Etagenruf is continuous.
- **Bus is a shared party line; line 4 is per-apartment.** Line 4 (Türruf) is **address-selective**
  — it only goes hot for *this* apartment's own door button; another apartment's ring leaves our
  line 4 cold, so **OC1 (on line 4) senses only our own ring**. Line 2, by contrast, is **shared
  across apartments**, so a line-2 audio tap can hear other apartments' active calls.
- **ÖT door-opener trigger (authoritative):** the troubleshooting test says
  *"Zum Test, Klemmen 2 u. 3 brücken"* — **bridge terminals 2 & 3** → opener voltage
  appears at 8/9. This is exactly what relay **K2** does (COM=P2, NO→P3, a direct short).
- **ET versus ÖT:** ÖT directly bridges P2↔P3. The external floor-call button gates P5 for that
  apartment; it is not part of the handset internals.
- **Speech:** only enabled *after* a bell; ~25 s talk window, auto-off after ~60 s. The bus
  speech pair is **lines 2/3** (STR Fehlersuchhilfe: *Sprechverkehr* on 1/2/3, door side 6/7) —
  up-audio on line 3 (S2's 2.2 kΩ talk bridge), down-audio on line 2 (via the relay). At the
  WF26 the transducer couples to line 4 via **C1 (P5↔P4)**. The door-opener also momentarily
  shorts **2↔3**, so that pair is shared between speech and the ÖT trigger — **not** opener-only.

### Known shared-party-line limitations (accepted for V4.2)

V4.2 deliberately retains the field-proven P2-derived 2.2 kΩ talk handshake. Deriving a filtered,
DC-only pedestal would be electrically cleaner, but it would change the bus interface, TX injection
point and transition behaviour together; that is too much unqualified change for this revision.
Consequently:

- **K6 isolates only this endpoint's raw P4.** It prevents the local P4 gong from reaching
  `K5_LATCH`, but it cannot remove audio already present on shared P2. With K1 active, the path
  `P2 → K1-ch1 → TALK_BRIDGE → R28 → K1-ch2 → P3` also forwards a neighbour's gong or
  other P2 audio. A ring-start delay can avoid a known local interval; it cannot prevent a neighbour
  from becoming active during TX.
- **There is no bus-owner or neighbour-busy indication.** `K5_SENSE_N` confirms only this board's
  relay, OC1 observes only this apartment's private P4, and the codec RX tap is AC-coupled. Firmware
  therefore cannot distinguish a quiet neighbour session from an otherwise-idle shared bus, and it
  cannot monitor RX while the half-duplex codec is transmitting.
- **Concurrent sessions collide rather than arbitrate.** Another active handset can hear shared-bus
  audio, smart TX may be audible there, two transmitters can mask one another, and any handset's
  P2↔P3 door bridge interrupts the common speech pair. The codec RX tap likewise hears neighbour
  gongs and speech whenever capture is enabled. Firmware may limit when it records or transmits, but
  that is a privacy policy rather than electrical isolation.
- **Concurrent latch loads reduce P2 voltage.** One measured stock neighbour session moves P2 from
  about 12.05 V to 9.44 V. Additional simultaneous relay loads can reduce it further; V4.2 has no
  load negotiation. K5 pull-in occurs from private P4, but its hold margin and the TV20/S response
  under combined loads remain commissioning checks.
- **Simultaneous bell types are not independently reportable by the binary taps.** A real Etagenruf
  remains structurally audible, but OC2 also responds to loud shared transducer audio and is masked
  during a Türruf or PTT. A genuine floor call in that interval can therefore be absent from HA even
  though the physical gong is heard.

These limitations do not change the replacement-only rule: the board remains one handset endpoint,
not a second WF26 connected in parallel.

## WF26 internal circuit (reverse-engineered)

The WF26/G has no active electronics: one 16 Ω speaker/microphone, a latch relay, a 22 µF coupling
capacitor, a 2.2 kΩ talk resistor and two DPDT switches. Its authoritative connectivity is in
`wf26/wf26.kicad_sch`, with a neutral readout in `wf26/wf26-schematic.md`.

**The numbering is canonical: Pₙ = bus line n** (J1 pin n → Pₙ), confirmed by measurement — the
door-opener bridges **P2↔P3** (= the ÖT pair, lines 2/3) and the speaker sits across **P1↔P5**
(common + Etagenruf), leaving **P4 = line 4 (Türruf)**.

Topology: LS1 across **P1↔P5**; C1 across **P5↔P4** (**+ toward P4**, the Türruf +12 V DC side);
the relay coil across **P1↔P4**; R1 from **P4** to R1_BRIDGE (the talk-switch common).

Key facts:

- **Door release = direct P2↔P3 (no resistor).** S1 (Türöffner) *pressed* shorts **P2↔P3**
  directly — the ÖT bridge, exactly the TV20/S test *"Klemmen 2 u. 3 brücken."* *Released*, S1
  parks P2 on K1_COM. **R1 (2.2 kΩ) is *not* in the door path** — it lives on the talk switch.
- **Talk = P4↔P3 through R1 (2.2 kΩ).** S2 (Sprechen) *pressed* ties R1_BRIDGE↔P3, putting R1
  across **P4↔P3**; *released* it parks on the unused NC (open). The talk handshake the TV20/S
  sees is a **2.2 kΩ bridge of line 4 to line 3**.
- **Why the talk bridge is resistive, not a short.** During a held session K5 ties **P2↔P4**
  (the listen path), so the talk bridge **P4↔P3** is electrically **P2↔P3** — the *door-opener*
  pattern. The 2.2 kΩ keeps it below the opener's fire threshold (a dead short fires; 2.2 kΩ does
  not), so talking can't pop the door; it also limits the load on the line-4 session hold.
- **The relay coil is across P1↔P4 = common ↔ Türruf, so the house ring energises it directly.**
  The TV20/S **pulses line 4 high for ~1 s** — ~12 V/320 Ω ≈ 37 mA through the coil to common — and
  pulls K5 in. After that the TV20/S lets go of line 4; **P2 seals the latch in** (`S1 NC →
  K1_COM → the closed NO contact → line 4 → coil`), so the **handset holds line 4 hot from the P2
  supply** for the session — the TV20/S is not driving line 4. **Dropping line 4 does *not* release it** — P2
  holds it; the session ends via **P2**: at a door-open S1's **break-before-make** transfer opens
  P2↔K1_COM ~6 ms *before* bridging P2↔P3, dropping the coil (line 4 falls, P2 *rises* as it unloads —
  **bench-confirmed, `our-ring-after-neighbour`**); or the ~60 s inactivity timeout ends it by a brief **P2-low pulse** (**bench-confirmed,
  `our-ring-no-door`**): the TV20/S sinks P2 — **held ~2.8 V for ~18 ms *after* line 4 has separated and
  fallen to 0**, so it's P2 *driven* low (line 4 merely follows) — dropping the K5 coil. P3 stays cold
  (no door-open). Which line is pulled is immaterial to the board: OC1 sees line 4 fall either way.
- **Single transducer:** LS1 (16 Ω) is the **only** transducer (no separate mic), across
  **P1↔P5**, reused as speaker and mic for tone output and both speech directions. Everything
  the handset reproduces or picks up is at P1/P5 (its single transducer).
- **C1 (P5↔P4) is the audio crossover.** It couples the speaker-hot node (P5) to the Türruf
  line (P4) — passing audio (AC), blocking DC — the single component straddling the transducer
  and the signalling side. **Polarity: + toward P4 (the +12 V Türruf side), − toward P5 —
  bench-confirmed on the genuine WF26** (its + lead traces to line 4). All three agree: the
  genuine unit, the wf26 reverse-engineered schematic (C1.1+ → P4), and the V4 board (C19/1+ →
  P4 via K3) — only an early +→P5 hand-assumption was wrong.

**Audio path — fully derivable now:**

- **Etagenruf (apartment call):** a tone on **line 5 → straight across LS1** (P5 hot, P1 common).
  Loud, unshaped — no cap, no relay. (Line 5 reaches the bus only through the external ET button.)
- **Türruf gong (house call):** the ring on line 4 splits — **DC → coil → common** (pulls K1 in);
  **AC tone → C1 → P5 → LS1** (you hear the gong). **C1 blocks the DC off the speaker, so the
  holding current returns through the *coil*, not the voice coil → no cone offset.** Pulling P4
  kills both (observed). The gong is not made in the handset (no ICs) — the TV20/S sends it as
  AC on line 4.
- **Talk (up-audio):** LS1 as mic → **P5 → C1 → P4 → R1 → P3** (line 3) out to the door station.
- **Listen (down-audio):** during a session (relay in), **S1 released** ties **line 2 (P2) →
  K1_COM → NO → P4 → C1 → P5 → LS1**. Down-speech arrives on **line 2**, routed by the
  door-release switch + the energised relay onto the same C1→speaker path.

> Takeaway: nothing in the WF26 is "smart." The house ring's own DC works the relay; C1 is the
> single audio crossover; the two switches are a **direct 2↔3 door bridge (S1)** and a
> **2.2 kΩ 4↔3 talk bridge (S2)**. No firmware handshake exists.

**Session hold:** after the TV20/S's ~1 s Türruf pulse, the energised relay connects P2 through S1
and its NO contact back onto P4. Thus P2—not a continuing central-unit line-4 drive—holds the coil
and line 4 high for the session. OC1 consequently tracks the latch edge-to-edge. Door-open breaks
that seal-in; the inactivity timeout ends it with the measured P2-low pulse.

**Interfacing takeaways (audio tap / virtual PTT):**
- Record/monitor: a high-Z tap on **P1/P5** (the transducer) captures gong, Etagenruf and both
  speech directions regardless of bus line — *but* it rides the relay/C1 path, so it dies when the
  gong is suppressed (C1 opened). The board instead taps the **speech pair** (RX P1↔P2, TX
  P1↔P3), which is independent of line 4 / suppress — see "Audio path."
- To mimic the stock S2 during a held session, bridge **line 4 ↔ line 3 through ~2.2 kΩ**; the
  energised latch already makes the internal latch node follow P2. The smart K1 path sources its
  restored 2.2 kΩ R28 handshake directly from **P2**, allowing controlled TX independently of session state. Virtual
  door-open remains a direct **line 2 ↔ line 3** short paired with a seal-in break (mimic S1).
- Injecting TX audio on P1/P5 makes LS1 replay it (quiet at mic level); lift one LS1 lead to
  silence it (1-wire board mod).

---

## V3 — the retired predecessor (perfboard)

V3 was an ESP32 DevKit and relay module on hand-wired perfboard; its source is
`docs/design/KlingelV4.fzz`. It was retired because the inter-board jumper connections worked loose
and because its shared optocoupler limiter allowed an active channel to reverse-stress the idle
Etagenruf optocoupler. V4 retains the proven basic sensing and switching behavior but integrates it
on one PCB and gives each optocoupler its own limiter and anti-parallel clamp. V3 pin assignments and
parts are historical and are not design inputs for V4.

---

## V4 — integrated single board

**Design philosophy: carry the proven V3 sense path over; modernise the rest.** The bell-sense
front-end is reproduced — per-opto LED limiters (a shared limiter would let a ringing channel
reverse-bias the idle opto's LED past its 6 V VR), anti-parallel reverse-clamp diodes on each opto
(polarity hardwired anode-to-bus-line) — as is the direct ÖT bridge (K2, P2↔P3). The three ESP-driven
actuators are now **PhotoMOS SSRs** (K1 talk gate, K2 door, K3 chime-mute), the audio path is
**transformer-less** (codec on the speech pair, P1↔GND bonded), and a passive **WF26 core** preserves
the complete handset function when unpowered. Line 4 carries the Türruf as a ~12 V DC level with the 3-Klang
tone riding on it: the opto (on P4↔P1, **ahead of C1**) sees the DC-dominated level — so it is debounced
in firmware (`delayed_on`/`delayed_off`), not rectified — while C1 (K3-gated) blocks that DC and passes
only the AC tone on to LS1. Same line, two views: DC at the opto, audio at the speaker.

### Decisions

- **Single integrated PCB:** no inter-board jumpers; full SMT/THT assembly is handled by JLCPCB.
- **ESP32-S3 with PSRAM and external antenna:** enough memory and I/O for ESPHome audio, native USB
  flashing/logging, and flexible pin placement. Wi-Fi is the only network interface.
- **PhotoMOS switching:** talk and door contacts default open; chime-mute and seal-in-break contacts
  default closed. This preserves passive handset behavior with the smart layer unpowered.
- **Dry physical-Talk sense plus a hard K1 inhibit:** one SW4 pole remains the passive 2.2 kΩ Talk
  contact; the other reports the switch independently of the bus and opens K1's LED return while
  the physical contact is engaged. Firmware can therefore distinguish manual Talk without relying
  on P4/K5, while the switch itself prevents a sustained smart-plus-manual handshake.
- **Transformer-less, half-duplex audio:** the codec taps lines 2/3 and shares P1 with logic ground.
  This deliberately trades galvanic isolation for a compact, direct audio path.
- **One protected 5 V/USB inlet:** the JST-SH service connector carries VBUS and native USB data;
  D4 blocks reverse input and back-feed before the fuse and regulators.
- **Four layers:** provide continuous reference planes and practical routing density around the
  ESP32, codec and mixed bus/logic interfaces.
- Exact device variants, footprints and supplier identifiers belong to the schematic and
  `ORDERING.md`; the sections below retain only values that affect behavior.

### ESP32-S3 GPIO map

The authoritative pin assignment lives in `firmware/doorbell.yaml` and the schematic
(`kicad/doorbell.kicad_sch`, U1); it is not duplicated here. **Placement rationale:** U1 sits so the
native-USB pins (IO19/IO20) reach J1 through the D5 ESD clamp, and the ES8311 I²C/I²S
bus is assigned **ascending by module pad** (SDA, SCL, MCLK, BCLK, DIN on GPIO38–42, then WS, DOUT on
GPIO2/GPIO1) so it fans out toward U3 in U3's pin order with no crossings. The S3's GPIO matrix makes
this purely a placement choice: any function routes to any pad.

**Boot-state rationale (the part that isn't just a pin list):**
- **SSR gates idle off through boot (SAFE-6).** The three DRV pins are plain GPIO that power up as
  floating inputs; the 10 k pull-downs keep the SSR LEDs dark until firmware drives them. DOOR_DRV
  sits on a pin with no boot-time drive, so the opener can't pulse on reset.
- **Strapping pins parked safe:** the S3 straps on IO0/IO3/IO45/IO46. **IO0** is the boot strap, held
  high by R11 (10 k to +3V3) for normal SPI-flash boot, with SW1 pulling it to GND for download mode.
  IO3, IO45 and IO46 remain unconnected at their module defaults; the WROOM sets its own internal-flash
  voltage. The active-low status LED instead uses unrestricted **IO7** (U1 pad 7):
  `+3V3 → R15 → D6 → IO7`, with R27 (1 kΩ) pulling IO7 to GND for a defined boot indication.
  Firmware drives IO7 high when healthy and lets ESPHome blink it on Wi-Fi/API errors. The I²C/I²S
  bus deliberately lands SCL/MCLK/BCLK/DIN on IO39–42 = the MTCK/MTDO/MTDI/MTMS JTAG group — none of
  those are S3 strapping pins, so it only forgoes pin-JTAG (debug runs over USB-Serial-JTAG) with no
  boot-time effect. EN has the 10 k (R10) + 1 µF (C5) RC + SW2 (Espressif EN-RC spec).
- **Supply diagnostic on ADC1:** unrestricted IO5/ADC1_CH4 monitors the post-fuse +5 V rail through
  the R40/R41 divider. ADC1 avoids the Wi-Fi contention associated with ADC2, and IO5 is not a
  strapping pin, so the monitor has no reset-state effect.
- **Physical Talk sense on IO47:** U1 pad 24 is an unrestricted input on the specified
  **ESP32-S3-WROOM-1U-N16R8**. R42 pulls `PTT_SENSE_N` to +3V3 at boot/release and R43 limits fault
  current if firmware accidentally configures the pad as an output. IO47 is neither a strapping pin
  nor one of IO35–37 consumed by this module's octal PSRAM. This 3.3 V connection is variant-specific:
  ESP32-S3R16V-based WROOM variants run IO47/IO48 at 1.8 V and are not drop-in substitutions for U1.
- **No USB-UART bridge:** flashing + logs run over the native USB-Serial-JTAG (IO19/IO20 → D5 → J1).
### Bell / session sense front-end

Two identical channels (OC1 = house bell on P4↔P1, OC2 = apartment bell on P5↔P1):

```
bus line (active, +) ──► opto LED anode ── LED ── cathode ──┬── R_lim (5.1k) ── P1 (common)
                          ▲ 1N4148W clamp, ANTI-parallel ───┘
opto collector ──► GPIO + 12 kΩ to +3V3     opto emitter ──► GND  (per channel, direct)
```

- **Fixed polarity (no switch):** the bus is taken to drive active lines **positive** w.r.t.
  common, so each LED is hardwired **anode → bus line** (P4 for OC1, P5 for OC2),
  **cathode → R_lim → P1** — it conducts on the active (positive) half. **Bring-up check (per
  channel):** ring the real bell and confirm detection, or look for the ~10.7 V drop across R_lim
  (≈2 mA) when active. If a channel never detects (near-0 V across R_lim, ~0.7 V across the LED),
  that line's polarity is the other way — swap the LED's two bus connections. The wrong guess is a
  silent non-detect, not damage: the clamp (D8/D9) holds the reverse-biased LED to ~0.7 V.
- **Reverse clamps (D8–D9, 1N4148W):** anti-parallel across each opto LED — clamp anode on
  the LED-cathode net, clamp cathode on the LED-anode net — so the clamp conducts only on
  the reverse half-wave and limits the LED's reverse voltage to ~0.7 V (< its 6 V VR).
  **Lib convention: 1N4148W pin 1 = cathode, pin 2 = anode** (CDFER JLCPCB lib, same as the
  K5 coil flyback D1 and Schottky D4 — pin 1 toward +5V there).
  **Both D8 and D9 are kept** — line 4 is *not* pure DC: the Türruf gong's 3-Klang tone (and the
  session-end snap-back) swings P4 to **~−8.5 V** in the measured envelope, reverse-biasing the OC1 LED;
  line 5's Etagenruf reverse-biases the OC2 LED to ~−5 V. The deployed V3 board's Etagenruf opto **died
  of reverse stress** (shared-limiter cross-channel reverse-bias; see "V3"), so this LED avalanches low
  and reverse-bias is its fatal mode — each clamp is cheap insurance against its line's negative swing.
- **Per-opto limiters (R_lim1–2, 5.1 kΩ):** one per channel; a shared limiter lets a ringing
  channel lift the common node and reverse-bias the idle LED — **field-confirmed: this killed V3's
  Etagenruf opto** (see "V3"). With per-opto limiters each idle cathode sits at ~0 V, so there is no
  shared node to lift. Each opto emitter returns **directly to GND** (per channel): the emitter
  current is only µA, so no series resistor is needed, and a per-channel return leaves no shared
  emitter node to couple one channel into another.
- Bell present → LED conducts → phototransistor pulls the GPIO low → ESPHome
  `inverted: true` ⇒ "on". GPIO LOW level ≈ 0.12–0.27 V.
- **Low-current sense margin:** OC1/OC2 are Toshiba **TLP293 GB-rank** parts, guaranteed to at least
  100% CTR at IF=0.5 mA and 30% saturated CTR at IF=1 mA, VCE=0.4 V (25 °C). The captured 5.1 kΩ
  LED-current envelope is approximately 1.1–2.8 mA. With the fitted 12 kΩ ±1% collector pull-up,
  the ESP32's worst VDD/VIL corner needs approximately 0.23 mA. The 0.30 mA guarantee therefore has
  enough margin for a 10% cold engineering derating to 0.27 mA over the expected 0–50 °C enclosure
  range. For idle HIGH, applying the more severe 85 °C maximum dark current of 50 µA to the 12 kΩ
  maximum leaves approximately 2.39 V at minimum VDD, above the 2.25 V VIH limit. These temperature
  bounds are engineering calculations, not production CTR guarantees: Toshiba specifies minimum CTR
  at 25 °C and presents the temperature curves as typical. First-board endpoint characterization
  remains required.
- **Cross-talk masking** (`firmware/doorbell.yaml`, lambda filters ahead of the debounce):
  **OC1 is not masked**; it senses the DC-dominated line-4 session level and must remain able to
  report a genuine ring during PTT.
  - **Apartment Doorbell (OC2)** taps the speaker pair, so it pulses on *any* loud
    speaker audio — Etagenruf tone, Türruf gong and session speech alike. It is forced
    off while House Doorbell / PTT are active; what remains is a genuine floor
    call.
  - All masked interferers are AC, so the raw input keeps toggling and the masks
    re-evaluate continuously while active. The masks must never gate a *steady-DC*
    signal that outlives the mask window — the lambda only re-runs on raw-input edges.
- **OC2 tone detection** (`firmware/doorbell.yaml`): the opto conducts only on positive
  half-cycles above the LED threshold, so OC2's raw input toggles at audio rate
  (~1 ms low / ~1.4 ms high) and a plain `delayed_on` would never latch. The filter
  chain stretches the conduction pulses into a level first (`delayed_off: 50ms`), then
  requires it to persist (`delayed_on: 150ms` — also outlasts House Doorbell's 50 ms
  latch so a gong starting together with a house ring cannot beat the mask), then holds
  the result (`delayed_off: 2s`). OC1 senses a **DC-dominated** level (line 4's Türruf is a
  ~12 V bias with the chime tone riding on it), so a plain `delayed_on`-first filter latches
  where it never would on chatter — OC1 keeps the plain `delayed_on: 50ms` debounce, which
  doubles as AC-interference reject (no audio-rate pulsing can hold it low for 50 ms). The chime *tone* is still on line 4 — it
  reaches LS1 via C1, which strips the DC the opto rides on — so OC1's `delayed_off: 2s` also
  bridges the gaps between the three Klang so one ring = one event.

### Switches (K1/K2/K3/K4/K6 PhotoMOS; SW4 physical-Talk interlock)

```
K1 (talk+TX gate, dual NO): ch1 P2↔TALK_BRIDGE (precharged by JP3+R38+R39 = 200 kΩ), ch2 TX_OUT↔P3
K2 (door opener, NO): P2 ↔ P3 — energise to bridge the ÖT pair
K3 (chime mute, NC): P4 ↔ CHIME_POS — energise to open and mute
K4 (seal-in break, NC): SW3.6 ↔ K5.3 — energise to drop the latch
K6 (P4 isolator, NC): P4 ↔ K5_LATCH — opens only when P4_ISO and K5 auxiliary NO are both active
K1 LED return: both cathodes → K1_LED_RET → SW4.3 (NC1) → SW4.2 (COM1) → GND while Talk is released
Other LED drive: MUTE_DRV → R6; DOOR_DRV → R5→K2 LED (via Q3 delay) + R21→K4 LED (each Rn = 220 Ω)
```

- **PhotoMOS, bidirectional.** K2/K3/K4 are single-pole; K1 contains two independent NO contacts.
  K1/K2 are **1-Form-A (NO)** = open at idle; K3/K4 are **1-Form-B (NC)** = closed at idle. Off-state
  default is fail-safe: K1/K2 open ⇒ no talk/door at boot (the passive core's S2/S1 cover those
  unpowered); K3 closed ⇒ the gong rings at boot/unpowered (GONG-3/SAFE-6).
- **K1 — talk handshake + TX gate (BUS-1).** Ch1 sources P2 onto `TALK_BRIDGE`; R28 provides the
  field-proven 2.2 kΩ handshake to `TX_OUT`; ch2 gates `TX_OUT` onto P3. Codec TX joins
  `TALK_BRIDGE` through R26/C14. Factory-bridged JP3 and R38+R39 (100 kΩ + 100 kΩ) span ch1 so
  C14's bus side follows the standing P2 bias before K1 closes; the closed contact bypasses that
  high-value path during TX. K1 ch2 still leaves line 3 structurally high-impedance at idle. JP3 is
  cuttable only for diagnostic A/B testing and is normally restored bridged.
- **SW4 — passive Talk, dry sense and K1 hardware inhibit (FW-4/BUS-2).** The two poles deliberately
  have different jobs, and every involved net is named in the schematic:
  - **Passive pole, pins 4/5/6:** pin 5 (`TALK_SW`, COM) is fed from `K5_LATCH` through R29 = 2.2 kΩ;
    pressing the momentary switch connects it to pin 4 (NO, P3). Pin 6 (NC) is intentionally not
    connected. This is the stock manual Talk path and remains functional with logic power absent.
  - **Dry logic pole, pins 1/2/3:** pin 2 (COM) is GND. Released, 2↔3 (NC) grounds `K1_LED_RET`, so
    firmware may energise both K1 channels. Pressed, 2↔1 (NO) grounds `PTT_SW_N` through the switch,
    pulling GPIO47/`PTT_SENSE_N` active-low through R43 = 1 kΩ; opening 2↔3 simultaneously removes
    both K1 LED cathode returns. Thus even a stuck-high `PTT_DRV` cannot sustain K1 while manual Talk
    is held, and no bus-potential contact reaches the GPIO pole.

  R42 = 10 kΩ holds the input at about 3.3 V released; pressed, R42/R43 form a divider at about
  0.30 V and draw about 0.30 mA, comfortably above the SPPJ322300's 50 µA at 3 V minimum load. R43
  also limits a mistaken GPIO-high-against-pressed-switch condition to about 3.3 mA. The K1 return
  carries roughly 16–18 mA total, below the switch's 0.2 A rating and above its minimum load; its
  specified contact resistance is negligible beside each 220 Ω LED resistor.

  The switch is specified **non-shorting within each pole**, but the datasheet does not bound the
  relative transition timing of the two poles. The first fabricated V4.2 board must therefore be
  scoped to prove K1 has opened before the passive 2.2 kΩ path makes on press, and firmware must keep
  K1 commanded off until a debounced release. The schematic/simulator proves steady states, not this
  mechanical cross-pole timing. The hardware interlock stops K1 only: it does not force normally
  closed K3 or K6 back to their passive states while their LEDs are energised. Firmware must stop
  playback, clear `P4_ISO` and release K3 on physical Talk before passive audio is expected. A stalled
  powered MCU can delay or defeat that restoration; this is accepted because the mechanical K1
  exclusion remains safe and removing logic power restores the complete passive path.
- **Why TX drives line 3, not line 4.** A WF26 hangs **C1 (22 µF) + the 16 Ω speaker across line 4**
  = a ~20–30 Ω near-short to common across the voice band; injecting there would dump the drive into
  it. Line 3 is light (the TV20/S amp input ∥ the handshake leg's 2.2 kΩ), so the codec drives
  **line 3**, and K1's ch1 supplies the DC handshake from P2.
- **K2 — door opener.** Energise to bridge **P2↔P3** directly (dead short) — the ÖT the TV20/S reads
  as "open". Paired with **K4 + the Q3 delay lead** to mirror S1's break-before-make — see "Door-open
  mirrors S1".
- **K3 — chime mute.** In the gong's audio path (`P4 ↔ CHIME_POS ↔ C1 ↔ P5 → LS1`). NC ⇒ de-energised
  = closed = gong rings (and OC1, on line 4, still senses — K3 doesn't touch line 4); energise = open
  = gong muted, with **line 4, the latch and the Etagenruf all untouched** (Etagenruf reaches LS1
  directly on line 5, bypassing C1 — structurally non-suppressible, GONG-4). K3 also lies in the
  passive speech crossover: while it is open, LS1 cannot receive P2 speech through the sealed K5 or
  send microphone audio through R29/SW4. The codec speech-pair tap, ring/session sensing, latch, door
  actuator and Etagenruf remain available.

  **Interim V4.1 firmware policy:** while HA-connected chime suppression is requested (and Force
  Chime is off), firmware now holds K3 open continuously instead of reclosing it 4.2 s after the
  initial gong. The former reclose restored passive speech but also let a later neighbour's gong on
  shared P2 travel through our sealed K5 into LS1; field history showed exactly that composition.
  Suppression mode is therefore deliberately automation-only for now: smart codec TX/RX and
  greet/open continue, but physical LS1 listen/talk do not. This adds no practical Talk loss on the
  installed V4.1 because its USB-C connector already obstructs SW4 before full engagement. API loss,
  power loss or Force Chime still returns the normally-closed K3 to the stock passive path. The
  current V4.2 candidate now includes the dry SW4/PTT sense and K1 inhibit above; implementing its
  firmware input and restoring deliberate manual-conversation behavior remain gated on first-board
  electrical and mechanical validation in `TODO.md`.

  The desktop-only `firmware/doorbell-host.yaml` enables the expected V4.2 hand-off policy for
  deterministic tests: physical Talk cancels smart media/K1, clears K6 and restores K3; K5-confirmed
  smart TX isolates raw P4; every simulated door request is serialized through the pulse/re-arm
  coordinator; and passive listening remains owned for at most 30 s after physical-Talk release while
  K5 stays confirmed. K5 loss, smart TX or a door request ends that window sooner. This candidate rule
  does not enable those paths in installed V4.1 production firmware or satisfy the fabricated-board
  gate.

  The interactive simulator uses that same host target and deterministic circuit runner as its only
  doorbell execution path. Each browser session owns an isolated server worker, host process, Unix
  socket and preferences directory; the browser only submits circuit/policy controls and renders SSE
  samples. ESPHome sleep requests pace a server-controlled virtual horizon (pause, 1×, 10×, maximum or
  1 ms step), so U1/U3 writes remain ordered with circuit transitions. **Freeze firmware** stops host
  execution but retains the last U1/U3 drive state, modeling a wedged MCU; the circuit keeps evolving,
  so the independent door watchdog can clear K2 despite a frozen-high `DOOR_DRV`. Reboot resets program
  outputs while preserving physical reactive/relay/SSR/fuse state, and full reset starts over. The
  separately selectable WF26 reference remains passive and has no
  firmware process. Both endpoints default to a synthetic TV20/S terminal environment calibrated to
  the repository captures. It composes a second live WF26 topology for the supported one-neighbour case
  and derives ring, floor-call, door, session and timeout behavior from virtual time. The TV20/S core
  drives and observes only P1–P5; it does not inspect DUT relay, switch, SSR or firmware state. The
  manual circuit lab remains selectable for arbitrary sources. The field-proven 2.2 kΩ Talk handshake
  is classified from the terminal impedance and exposed as a supported state; the unmeasured TV20/S
  audio gain is not synthesized. The stock WF26's `R1_BRIDGE` is the P3/low side of R1 when S2 is
  pressed and therefore falls near 1 V in the terminal-equivalent model; the main board's differently
  placed `TALK_BRIDGE` stays on the P2/high side of R28 near the session bias. Other intermediate opener impedances, multiple neighbours and
  overlapping events fail explicitly instead of being invented; `sim/src/tv20s/` records the supported
  envelope and evidence hashes.

  **R36 (100 kΩ) + JP1
  (factory-bridged)** bleed `CHIME_POS` to GND while K3 is open, discharging C19's 22 µF
  coupling capacitance (τ≈2.2 s). It is a passive robustness measure: on the V4.1 bench board,
  `CHIME_POS` held about 10 V for tens of seconds, yet an immediate K3 reclose neither latched K5 nor
  asserted even unfiltered OC1. A subsequent ten-cycle sweep with reclose waits from 0 to 5 s showed
  a brief P4 discharge pulse on every cycle and zero K5 re-latches. The always-connected K5 coil
  (P4→P1) loads the transient before its contacts move. Therefore firmware need not impose a 5τ/12 s
  reclose delay, and an immediate fail-safe reclose on reset/brownout is acceptable. Cutting board
  USB power with the charge trapped produced the expected brief P4 pulse and no seal-in; see the
  [scope capture](docs/scope/k3-usb-power-loss.png). JP1 exists only for diagnostic A/B isolation;
  production/default is bridged. Repeat this acceptance capture on the first fabricated board because
  its crossover capacitor and clamp differ from the bench hardware. The simulator models K5's voltage-dependent pickup force: 9.6 V
  is a static must-operate limit, not a full-strength 3 ms command.
- **K4 — seal-in break (DOOR-4).** NC SSR in series in the `P2 → K1_COM` seal-in (`SW3.6 ↔
  K5.3`). De-energised = closed (seal-in intact, the passive latch works unpowered); energised
  (off DOOR_DRV, immediate) = open = K5 drops. With K2's make delayed ~38 ms (Q3 · R17·C18) the
  break leads the make — S1's transfer reproduced in hardware. See "Door-open mirrors S1".
- **K6 — P4 isolator.** NC at rest and unpowered, so raw P4 reaches `K5_LATCH` and the passive handset
  behaves normally. K5's auxiliary NO contact is the K6 LED return, so a stuck-high `P4_ISO` alone
  cannot open K6 until K5 has physically pulled in, and K5 release immediately removes LED current.
  The physical LED/contact node is `K6_RET`: R35 = 10 kΩ biases it from +3V3 and preserves the
  auxiliary-contact wetting current. GPIO4/`K5_SENSE_N` reaches `K6_RET` only through R44 = 100 kΩ.
  A GPIO hard-low therefore forms a weak R35/R44 divider rather than an alternate K6 return. At the
  maximum-rail, opposing-1%-tolerance pin-fault corner it leaves about 0.305 V across the LED (the
  divider carries ~30 µA; modeled LED current is negligible), below the qualification limits of
  0.4 V / 0.08 mA. Those limits retain 20% engineering headroom below K6's 25 °C guaranteed
  0.5 V / 0.1 mA recovery values because its temperature curve is typical-only. A hard-high GPIO
  while K5 is closed is limited to ~34 µA. GPIO4 must remain input-only with both internal pulls
  disabled in normal firmware. Structural, driven-pin, resistor, LDO, ESP leakage/threshold,
  K5 timing/contact and K6 switching/recovery corners are permanent simulator regressions. JP2 is an
  open recovery jumper directly across K6's output.
- K2/K3 remain independent; K1's GPIO drive is independent but its LED return is mechanically gated
  by SW4. **K4 is ganged with K2 on DOOR_DRV** — the break-before-make door pair. Firmware holds
  **K3 de-energised whenever a ring should be heard**. V4.1 field operation
  proves that the TV20/S forwards codec audio on line 3 after a 2.2 kΩ handshake. V4.2 retains that
  topology; first-board validation now concentrates on K5-confirmed K6 isolation and SW4's new dry
  sense/interlock timing.

### SSR LED drive (per channel)

```
PTT_DRV ── R4/R24 (220Ω each) ── K1 LEDs ── K1_LED_RET ── SW4 NC ── GND
other DRV ── 220Ω ── SSR LED ── GND or its documented hardware-gated return
each DRV ── 10kΩ ── GND   (pull-down: SSR off while the GPIO floats at boot)
```
The 220 Ω resistors give each SSR LED adequate operate current even at the GPIO's guaranteed-low
output-high voltage. IO9 and IO10 each drive two LEDs, so firmware must retain the ESP32-S3's normal
drive strength. V4.1 field operation proves the same direct-drive topology with higher 300 Ω LED
resistors; V4.2's 220 Ω values increase PhotoMOS operate-current margin, so no buffer stage is needed.
SW4's NC contact is in series only with K1's common LED return; K5's auxiliary contact similarly
gates K6 directly on `K6_RET`, with GPIO4 isolated by R44. The 10 kΩ drive pull-downs hold every
smart actuator inactive while GPIOs float at boot:
talk and door remain open, while the normally-closed chime, seal-in and P4 paths remain intact.
PhotoMOS contacts need no flyback; D1 exists only for the passive electromechanical latch.

### Power tree

```
J1 VBUS ──[D4 SS14]── VBUS_PROTECTED ── F1 1A fast fuse ── +5V ─┬─ main 3.3V LDO ── +3V3 ── digital loads
                                                                  └─ low-noise 3.3V LDO ── D18 ── codec AVDD
+5V ── R40 100k ── VBUS_F_ADC ──┬─ R41 10k ── GND
                                 ├─ C25 100nF ── GND
                                 └─ IO5 / ADC1_CH4
J1 D± ── D5 ── IO19/IO20 (native USB)         +3V3: 10µF + 10µF + 100nF; AVDD_PRE: 10µF out (C24)
D4 blocks a reversed J1 supply and prevents VBUS_PROTECTED from feeding back out through the service connector
USB D± ESD: TPD2S017 flow-through clamp (D5), VCC biased from +5V (post-fuse); +5V TVS: SMF5.0A (D10)
VBUS fuse: F1 (0466001.NRHF, 1A fast) ahead of all downstream protection — a clamping D10 blows it, isolating J1 (fail-safe)
```
R40/R41 scale the rail by 11:1, so the ADC sees about 0.41–0.45 V across the normal +5 V range and
about 0.84 V at D10's 9.2 V maximum clamp voltage. Their Thevenin resistance is about 9.1 kΩ; with
C25 that gives a ~0.91 ms input time constant and a local charge reservoir for the ADC. Firmware
multiplies the reading by 11 and exposes it as a diagnostic. It can reveal a sagging live supply,
but a blown fuse or complete J1 power loss also powers down the ESP32, so it cannot report that outage.

> No bulk electrolytic: the local LDO actively regulates the ~350 mA WiFi-TX burst
> (modeled droop ≈ 90 mV across 20 µF of ceramic on +3V3), so a bulk cap buys nothing.
> VBUS cable sag is a dropout-headroom question covered by the selected low-dropout regulator.

### Bus ↔ logic coupling (SAFE-3 deviation)

There is **no galvanic barrier** between the bus and the logic: **P1 is bonded to board GND**. The
transformer-less audio needs a low-Z return to drive line 3 relative to P1, and the bench measured P1
~0.5 V from apartment earth, so the bond is benign here — but it means **SAFE-3 isolation is *not
met*** (a deliberate, measurement-justified SHOULD deviation). The sense optos still give an
LED→phototransistor barrier on the *detection* path and the SSRs an LED→MOSFET barrier on the
*actuator* path, but the **codec RX/TX taps and the P1↔GND bond couple the bus straight to logic
ground**. Fault containment (SAFE-7) therefore rests on **per-tap protection** (series R + clamp +
DC-block caps) and the board being **sacrificial** behind **F1**, which fuses it off the USB supply
before a fault can back-feed. (Voltages are low — 12 V bus — so this is fault-energy containment and
hum/ground-loops, not shock.)

**Supply-earthing assumption.** The "P1 ≈ earth, so the bond is benign" justification holds only while
nothing *else* ties board GND to earth — it assumes the 5 V feed is a galvanically-isolated,
**floating-output Class II (2-prong) USB supply**, as a normal wall-wart is. The board adds no
isolation of its own, so an **earthed** source (a 3-prong PD brick, or a laptop's earthed PSU while
flashing) pulls bus common (P1) off its natural float to mains earth and closes a ground loop.
**Deploy on a Class II adapter.** The loop is low-energy at 12 V (sub-mA-class, set by the
bus-common-to-earth impedance) and contained the usual way — but note **F1 sits in VBUS, not GND**, so
an attached host shares the *unfused* common; prefer a battery-powered flashing host (see "Build /
test notes").

### BOM

Part values/footprints/LCSC numbers are maintained **directly in the authoritative KiCad files**
(`kicad/doorbell.kicad_sch` / `.kicad_pcb` — the generator scripts are gone). `./build.sh`
**exports** the order files from them (`fab/doorbell-bom-jlcpcb.csv` + `doorbell-cpl.csv`). See
`ORDERING.md` for the stock/eligibility checks at order time.

> J1 is SMT and J2 is through-hole; both are **assembled by JLCPCB**, not hand-soldered.

### PCB — layout constraints & rationale

Physical layout — traces, vias, copper zones, component positions, the 4-layer stack — lives in the
authoritative `kicad/doorbell.kicad_pcb`; this section keeps only the decisions and rules behind it.
The board is **4-layer**, **64.2 × 59.2 mm**, all parts on the top side, and **100 % hand-routed in
KiCad**; `./build.sh` verifies the inner copper-fill planes and fails if any net is unrouted.

- **Why 4-layer.** Continuous ground/reference planes control the native-USB pair and mixed-signal
  return paths, while the extra routing layer provides practical density around the ESP32, codec
  and mixed bus/logic interfaces. J1's JST-SH D+/D− pair remains over a continuous reference.
- **Bus↔logic coupling is a layout constraint** (see "Bus↔logic coupling"): there is no galvanic
  barrier — **P1 is bonded to board GND** — but keep bus-side nets to their own copper, crossing to
  logic only at the optos, the SSRs, and the deliberate codec/P1 taps, to contain fault energy and hum.
- **No vias in exposed pads** (solder-wicking avoidance): U1's and U3's EPADs carry no vias; they
  bond to the planes through adjacent copper. General V4 rule: vias must not overlap SMD pads.
- **Fine-pitch clearance.** The ES8311's 0.40 mm pitch won't take the default net-class clearance, so
  routing clearance is set globally to JLCPCB's published 0.127 mm capability (hole-to-copper 0.2 mm),
  pinned in `kicad/doorbell.kicad_dru`. Trade-off: the board routes at the fab limit, not with margin.
- **Bus-width policy.** Nets at WF26-bus potential (P1–P5, K5_LATCH, TALK_BRIDGE, TX_OUT, CHIME_POS) and +5V are routed
  wider than signal nets — the bus carries the Türruf and the door currents, +5V feeds the LDO and the
  ESP32's WiFi-TX peak (via +3V3). KiCad's DRC does not enforce this; it's a routing rule.
- **Pin assignment exploits the S3 GPIO matrix** (any function routes to any pad) so U1's and U3's escape fans
  route without crossings — see the GPIO map.
- **Copper thieving:** both outer layers carry fill zones; the build refills and checks them. An
  oversized floating island fails the check only if a GND stitching via actually fits inside it (via
  pad + float clearance on each side); it's then grounded with a hand-placed via in KiCad (vias are
  never auto-generated). Pockets too narrow for a via are unavoidable slivers and are accepted.
### Build / test notes

- **Antenna:** U1 (WROOM-1U) has a **u.FL connector** for an external antenna — route the lead out of
  the housing; there is no PCB-antenna keepout to honour (unlike the old WROOM-1).
- **Programming/bring-up:** flash + view logs over native USB-Serial-JTAG; BOOT + EN buttons are
  fitted for recovery. **J1 (JST-SH)** is the single deployed power inlet and native-USB service
  port; its cable pinout is `docs/design/usb-jst-j1-wiring.svg`. **Field re-flash (OTA failed):**
  move the service lead's USB-A end from the wall supply to a laptop. The smart layer reboots, but
  the doorbell keeps working throughout — the
  passive WF26 core is bus-powered, not USB-powered (MODE-1) — so only HA/notifications drop for the
  minute it takes. **Flash with the laptop on battery** so the host doesn't earth board GND
  (= P1 = bus common); see "Bus↔logic coupling".
- **Bench validation against the real TV20/S** (door pulse, chime suppress, session sense,
  PTT) before it goes in the wall. Wall wire-up map + line-identification signatures:
  `docs/design/wall-wiring-v4.svg`. Probe via the commissioning test points (TP1 = GND
  scope anchor, TP2 = +3V3, TP3–TP8 = watchdog gate + codec taps — net per test point in
  the schematic), J2's screws, and component pads. The board has
  **H1/H2 mounting holes** (NPTH 3.2 mm) on the enclosure bosses.
- **3D fit models:** `./build.sh step` exports the assembled STEP model; `./build.sh board-step`
  exports a printable bare board. SW3/SW4 carry `STEP_Exclude`, so fit-test exports omit their bodies
  and enlarge only their drills on a temporary copy; the committed PCB and fab outputs are unchanged.
  The implementation lives in `tools/step_*.py` and is intentionally not part of the circuit design.

---

## Audio path (half-duplex; restored V4.1 TX + V4.2 P4 isolation)

**The bus is half-duplex by design.** Speech is on the **1/2/3 group** (the STR *Sprechverkehr*):
**listen on line 2, talk on line 3, ref line 1 (common)**. The board taps that pair with an **ES8311
codec, transformer-less** — P1 is bonded to board GND, so the codec senses/drives line 2/3 relative to
that shared common (the SAFE-3 trade; see "Bus↔logic coupling"):

- **RX (listen):** a **differential sense of line 2** — `P2 → C16 → R30 → MIC1P`, `P1/GND → C17 → R31
  → MIC1N`, each codec pin biased to VMID through a 3.3 kΩ shunt (see RX front-end below). AC-coupled
  and high-Z (no DC bus load, BUS-1); the differential tap rejects hum and the ~0.5 V common-mode, and
  the series-R/VMID divider keeps the loud line-2 gong inside the codec's input range.
- **TX (talk):** dual K1 restores the field-proven V4.1 topology: ch1 connects the always-on P2 supply
  to `TALK_BRIDGE`; R28 (2.2 kΩ) connects `TALK_BRIDGE` to `TX_OUT`; ch2 gates `TX_OUT` onto P3.
  Codec audio joins at `TALK_BRIDGE` through `OUTP → R26 (2.2 kΩ) → C14 (DC-block)`. With K1 open,
  the factory-bridged `P2 → JP3 → R38 (100 kΩ) → R39 (100 kΩ) → TALK_BRIDGE` path precharges C14's
  bus side while K1 ch2 keeps P3 high-impedance. During a confirmed ring session, K6 can disconnect
  raw P4 from `K5_LATCH`, preventing the own-ring gong from reaching the P2-sourced handshake without
  shunting codec audio.

Tapping 1/2/3 (not the WF26 *speaker* pair P1/P5) keeps the smart audio **independent of line 4 / K3 /
the gong-suppress**, so it works with the gong muted.

Consequences:
- **No acoustic echo cancellation.** Both directions are never streamed at once, so AEC is moot —
  full-duplex is physically impossible on this bus regardless of MCU, and the half-duplex path the
  bus supports is within the S3's reach (I²S codec + ESPHome half-duplex).
- **Sequencing, not mixing:** assert direction → settle → stream → release → stream the other
  (walkie-talkie cadence).

**"Can we send?" — session sense.** V4.2 adds `K5_SENSE_N`. K5's auxiliary NO contact pulls the
physical `K6_RET` node low; GPIO4 observes that active-low state only through R44 = 100 kΩ, while
R35 = 10 kΩ biases `K6_RET` high when K5 is released. Firmware must configure GPIO4 as input-only with
both internal pulls disabled. This lets firmware distinguish raw P4 activity from a relay that has
actually pulled in and sealed without letting the sense pin bypass K6's physical interlock. OC1
remains on raw P4 for ring detection and diagnostics. K3 control remains independent: it may mute
the local gong while K6 controls only the raw-P4-to-latch connection. Audio direction is selected by
K1:

| Session (`K5_SENSE_N`) | K1 | State |
|---|---|---|
| inactive | – | no session — neither RX nor TX |
| active | open | listen → **capture (RX)** |
| active | closed | talk → **send (TX)** — line 3 asserted via the K1 handshake |

⇒ On validated V4.2 hardware, "is our handset session established?" = **K5 confirmed**; K1 then
selects TX. This does **not** mean the shared party line is idle or belongs exclusively to this
endpoint. Production firmware remains on the V4.1-compatible OC1 + 1.45 s ring-to-audio guard, plus
a separate 1.75 s minimum ring-to-open deadline, until the first fabricated V4.2 board passes passive
bring-up and K6 validation.

**Codec + front-end (committed to the netlist; analog values bench-gated for final trim):**

- **U3 is a mono ES8311 codec**, matching the bus's half-duplex audio. Its pinout and address
  configuration are authoritative in the schematic and datasheet.
- **TX front-end:** `P2 → K1-ch1 → TALK_BRIDGE → R28 (2.2 kΩ) → TX_OUT → K1-ch2 → P3` is
  the DC talk handshake. The codec leg joins `TALK_BRIDGE` through `OUTP → R26 (2.2 kΩ) → C14
  (1 µF DC-block)`. The DAC drives **single-ended** off OUTP; OUTN is parked through its own
  `R16 (2.2 kΩ) → C15 → GND` termination (OUTN sees no bus path, so it needs no clamp).
  Factory-bridged **JP3 + R38 + R39** place 200 kΩ from P2 to `TALK_BRIDGE` while K1-ch1 is open.
  This gives C14's bus side the same DC bias that the closed contact will impose, rather than letting
  K1 make into a charged coupling network. The nominal charging time constant is
  `(200 kΩ + R26) × 1 µF ≈ 202 ms`; after any P2 or codec-bias step, the existing 1.45 s
  ring-to-audio guard is more than seven time constants. C14 blocks steady DC, while at voice
  frequencies the added branch is about 202 kΩ into the DAC; in parallel with the existing
  25.3 kΩ RX tap it makes the total smart-layer P2 load about 22.5 kΩ. When K1 closes, ch1 bypasses
  the two resistors, so neither the 2.2 kΩ handshake nor TX gain changes. JP3 is a diagnostic escape
  hatch, not a normal assembly option.
  R26 limits current from bus steps coupled back through C14; D13 clamps positive excursions into
  AVDD and D16 clamps negative excursions into GND. Codec output is far above
  the passive handset microphone level, so firmware turns it down rather than adding a buffer. The
  R28 remains exactly 2.2 kΩ, safely distinct from the door short. K6 isolates the gong source rather
  than placing a voice-band shunt on this codec/handshake node.
- **RX front-end:** a balanced attenuating tap fed **differentially** to the ADC —
  `P2 → C16 (1 µF) → R30 (22 kΩ) → MIC1P` and `GND → C17 (1 µF) → R31 (22 kΩ) → MIC1N`, with
  **R33 / R32 (3.3 kΩ)** shunting MIC1P / MIC1N to **VMID**. Each leg is a 22 k/3.3 k divider (≈ −18 dB):
  it drops the bench-measured ±8.8 V line-2 Türruf gong to ~1.1 V — inside the ES8311 mic abs-max
  (AVDD + 0.3 ≈ 3.6 V), so the input ESD clamps never conduct on a ring — while the 22 kΩ also
  current-limits any clamp conduction and is the BUS-1 high-Z line-2 load. D14 clamps positive MIC1P
  excursions into AVDD and D17 clamps negative excursions into GND, keeping that current out of the
  codec's internal ESD structure. The 3.3 kΩ shunts bias both inputs to VMID and C12 keeps VMID
  quiet. The measured gong envelope bounds the input range; remaining work is PGA calibration.
- **Clamp rail + supplies:** all five protection diodes use LMBR01S30ST5G (30 V; maximum 0.30 V at
  10 mA at 25 °C). The exact C383224 X3-DFN0603 footprint and 3D model are project-local; its
  external pin-1 silk dot remains readable while the microscopic package outline stays on F.Fab.
  U4 generates `AVDD_PRE`; D18 then feeds AVDD while blocking reverse current toward
  the unpowered regulator. R37 (220 Ω) gives AVDD a defined discharge and injection-current sink.
  The D18 drop still leaves the codec comfortably above its 1.7 V minimum operating voltage at the
  combined codec/bleeder load. Under the simulated sustained ±17 V C14-short fault, R26 plus the
  clamps keep OUTP within the moving AVDD/GND window, AVDD below codec turn-on, and +5 V/+3V3 off.
  For the 0–50 °C enclosure range, the 0.30 V maximum remains a 25 °C guarantee rather than a cold
  specification. The cold-VF margin is accepted as an engineering judgment: even the conservative
  17 V/R bounds are only 7.8 mA through R26 and 0.8 mA through R30, with those resistors limiting any
  current shared with the codec's internal clamps.
  PVDD and DVDD remain on the normal +3V3 plane so their switching currents do not contaminate AVDD.
- **EP grounding (no vias):** the QFN-20 centre EP carries no thermal vias — paste over open vias
  wicks solder away, and the codec dissipates milliwatts. EP (and pin 10/AGND, tied to it) bonds to
  GND through adjacent copper.

**Why P4 is isolated (the own-P4 part of BUS-2 a).** During a session K5 seals `K5_LATCH` from P2. If raw P4 remains
connected, its gong rides onto the P2-sourced talk handshake and can be forwarded to the door. Once
K5's auxiliary contact proves pull-in, K6 opens raw P4↔`K5_LATCH`; K5 continues to hold from P2 while
the local gong remains on the raw side with OC1 and K3. K6 does not filter shared P2, so neighbour
audio can still follow the K1 path described under "Known shared-party-line limitations." The K5
contact is the direct hardware interlock; R44 keeps GPIO4 from becoming an alternate LED return, and
K6 is normally closed so reset or power loss restores the passive topology. V4.1 firmware still
delays ring-triggered greeting audio with `welcome_not_before_ms`; retire only the own-P4 workaround
after fabricated V4.2 validation.

**Final bench calibration:**
- **RX trim + TX level.** The MIC1P/N attenuating divider and VMID bias are committed (R30/R31 22 kΩ
  series, R32/R33 3.3 kΩ to VMID, C12 = 10 µF); trim the 22 k/3.3 k against the measured ADC full-scale.
  Set the codec digital volume to the handset's mic-through-2.2 kΩ level, don't overdrive the TV20/S amp
  (AUDIO-6).

**Committed SAFE-7 bus protection:** per-line **bidirectional TVS** (each P-line→P1, at the connector). The
front-end already tolerates the measured working envelope (`captures/runs/`: **≈ −11 V to +17 V**; SSRs at
60 V Voff, optos current-limited + reverse-clamped, codec taps AC-coupled ≥ 50 V), so the TVS is
**fault-only** (H24VND3BA): **24 V standoff** — above the +16–17 V ring/door switching transients, so it
stays idle in normal use — clamping over-envelope surge/ESD/miswire to ~50 V, under the 60 V SSRs.
DC-block caps are rated ≥50 V. J2 uses the verified P1–P5 wire order; arbitrary wire ordering is not
permitted because the WF26 audio crossover is polarized.

**Remaining bench checks:**

- **Hum** with the P1↔GND bond once RX is live.
- **⚠ V4.2 K6 isolation.** On the first fabricated board, confirm that a ring pulls K5 in before
  K6 opens, the P2 seal-in holds with raw P4 disconnected, own-ring energy disappears from P3 during
  TX, K5 release immediately restores K6, and JP2 restores the original topology when bridged.

---

## On-board passive WF26 core (the unpowered fallback)

The board is one complete WF26-compatible handset endpoint. Its **hardwired passive WF26 core** and
the smart layer share the same bus connection; connecting a second WF26 in parallel is unsupported.
The smart circuitry (ESP32, codec, sense optos, K1/K2/K3) is strictly additive to the passive core.

**Fail-safe principle.** With **no board power** the board must behave like a plain WF26. So the
passive core (transducer, C1, the Türruf-driven latch relay, R1, the talk/door switches) is a
**self-contained circuit needing no board power**, and the smart layer defaults to
inactive/transparent when unpowered (SSRs off, optos passive, codec quiet).
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

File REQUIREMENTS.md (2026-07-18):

# Doorbell controller — Requirements

What the board must do. This is the *what*; **DESIGN.md** is the *how* (architecture, pin map,
relays, audio path) and is authoritative for the circuit. Keep the two in sync: a requirement
change here should be reflected in DESIGN.md, and vice-versa.

Requirement levels follow RFC 2119: **MUST** = mandatory, **SHOULD** = strong default (deviation
needs a reason), **MAY** = optional.

## Context & terminology

The board is a smart interface to a **TCS TV20/S** apartment-intercom bus (5-wire, NTR201
230 V→12 VAC). It replaces or augments a **WF26** apartment handset. The smart layer is an ESP32
(ESPHome). See DESIGN.md "System context" for the full picture.
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

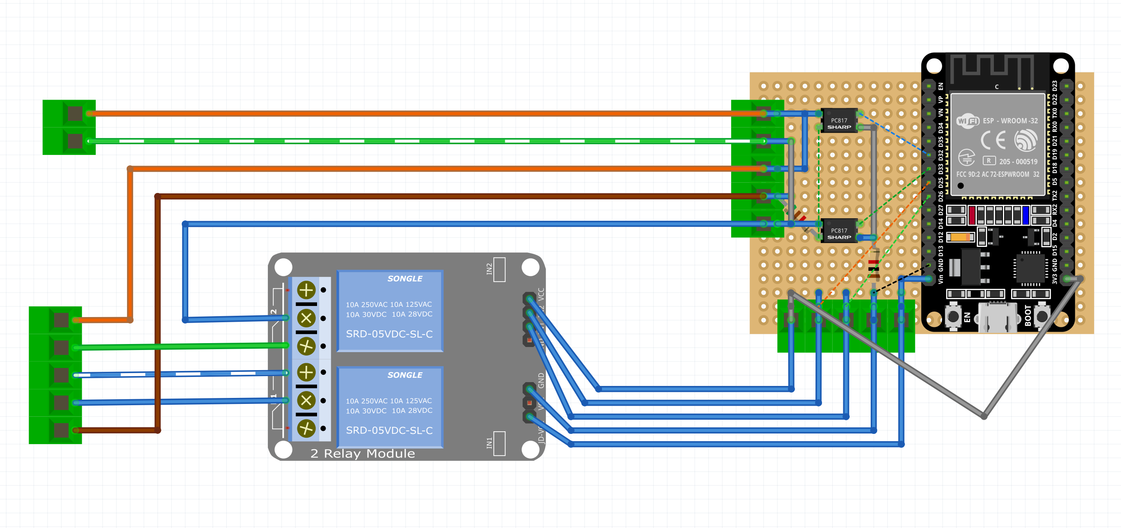
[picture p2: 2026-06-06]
docs/design/v3-fritzing-breadboard.png

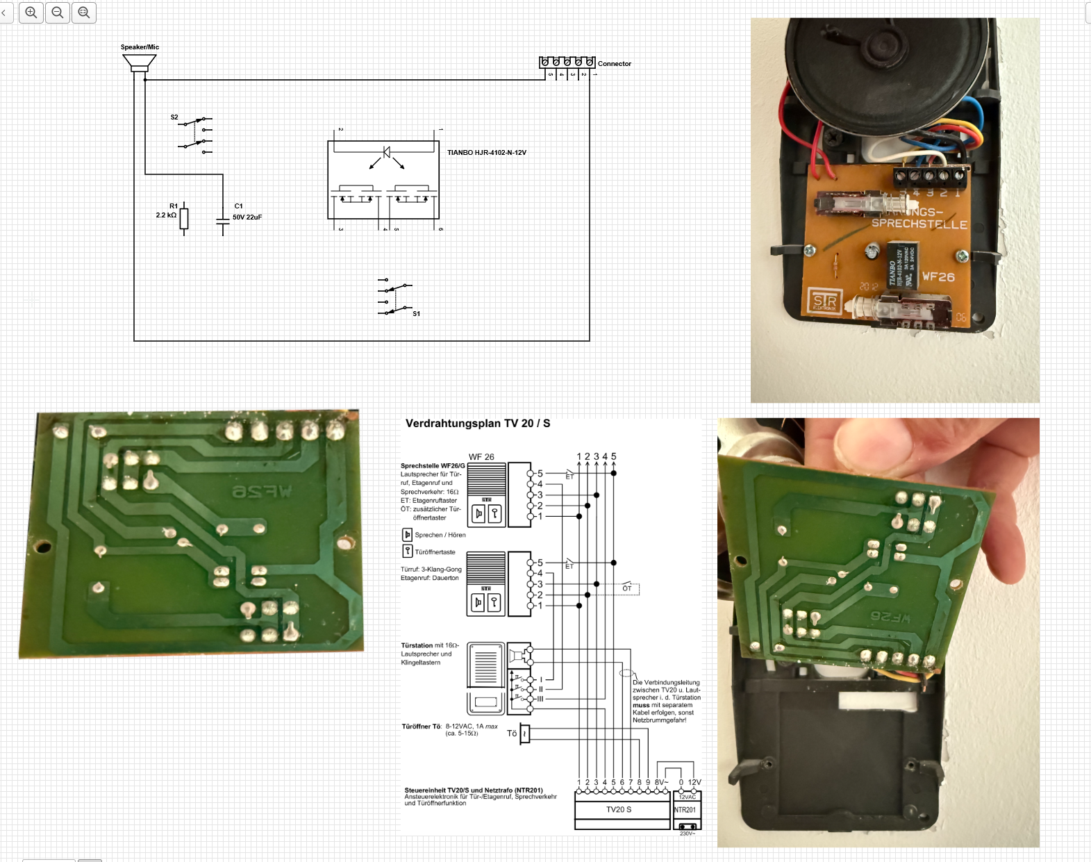
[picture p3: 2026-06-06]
docs/design/intercom-teardown-collage.png

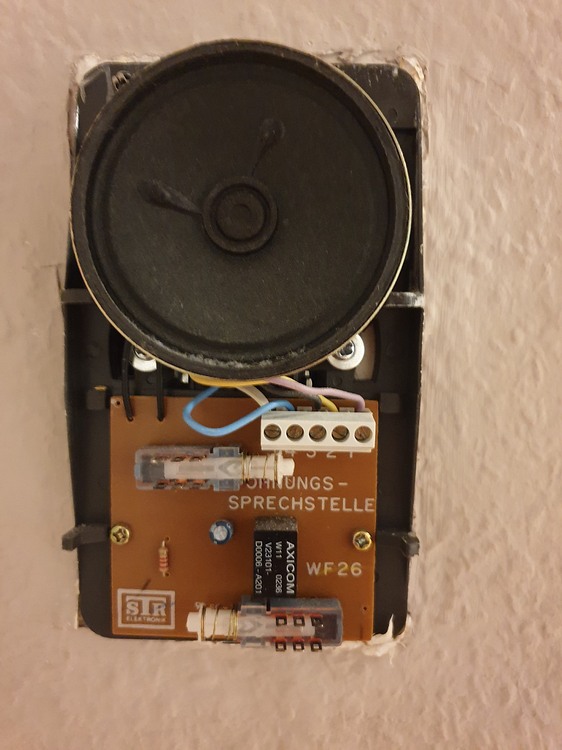
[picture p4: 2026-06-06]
docs/design/str-wf26-intercom-teardown.jpeg

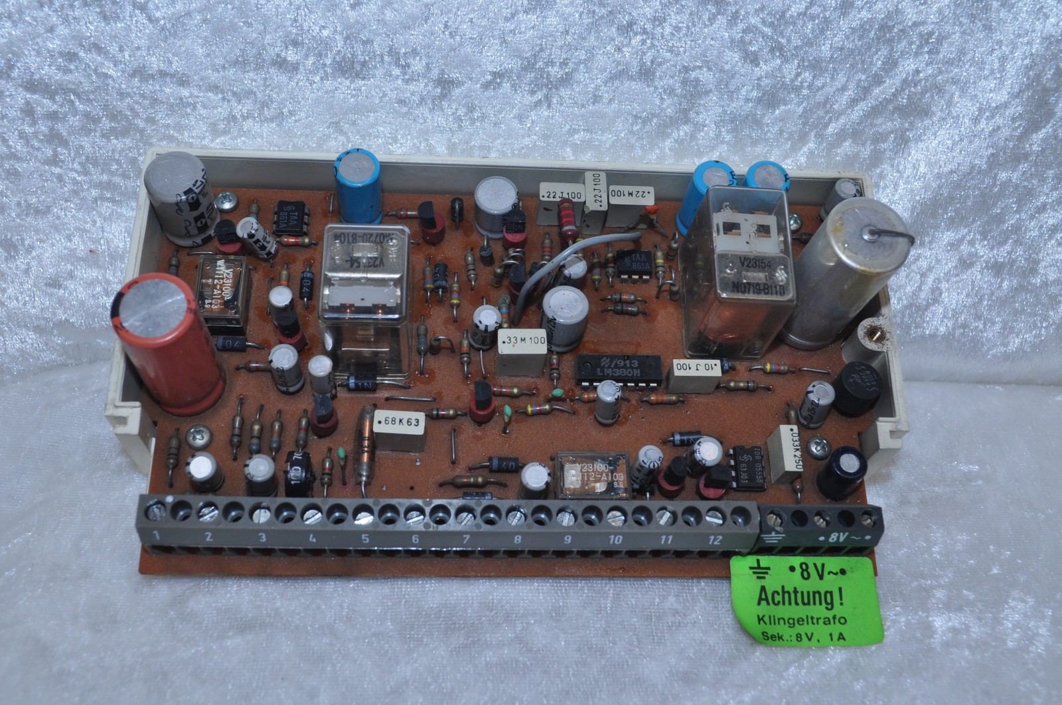
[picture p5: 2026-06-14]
docs/design/tv20s-board.jpg

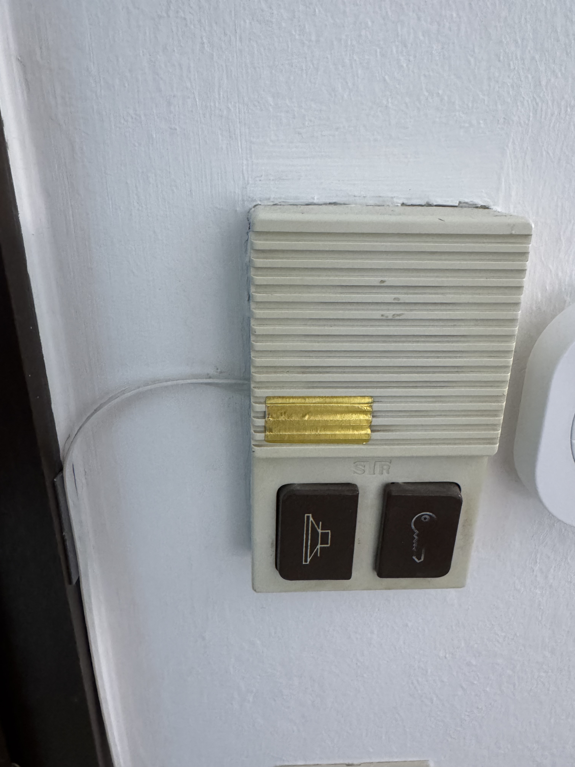
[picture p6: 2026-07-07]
docs/design/wf26-v3.jpeg

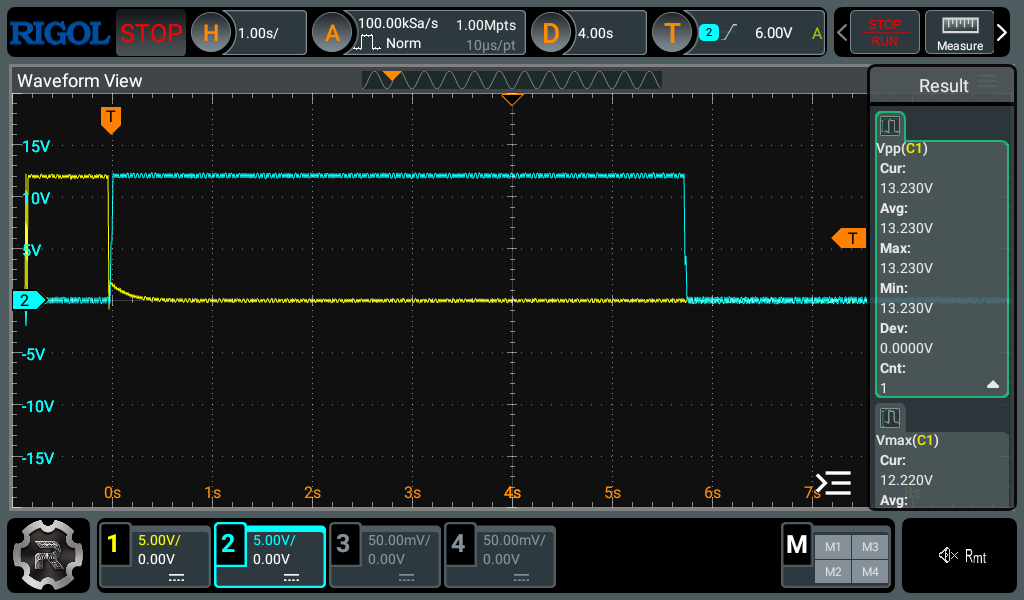
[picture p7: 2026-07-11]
docs/scope/door-watchdog-rearm-250ms.png

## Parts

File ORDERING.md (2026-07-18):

# Ordering the doorbell controller from JLCPCB

Goal: get **one assembled board** via JLCPCB **Standard PCBA** (the current BOM is not eligible
for Economic). The board is ~64 × 59 mm, **4-layer**, all parts on the **top side**; J2 (5-way
screw terminal) is through-hole and assembled by JLCPCB. J1 is the SMT JST-SH power/USB service
connector. The board is under JLCPCB's assembly minimum, so order it as **"Panel by JLCPCB"**
(edge rails added by them); confirm the panel/rails/depanel clear J2 (see the gates below). U1 is an
**ESP32-S3-WROOM-1U-N16R8** —
a **u.FL external antenna** module, so there is no PCB-antenna edge keepout to protect (route the
antenna lead out of the enclosure instead).

> Run `./build.sh` first to verify the design and re-export the fab files in `fab/` — the committed
> gerbers/BOM/CPL are build outputs and may lag the schematic.

## Mechanical fit gate (V4.1 seating passed, Talk actuation failed; current V4.2 still open)

**MECH-1 seating passed on V4.1, but MECH-1a did not:** the assembled PCB fits the original WF26
enclosure, seats on the bosses, clears the closed lid, and aligns the speaker and wire entry. The
door control works, but the housing's Talk actuator hits the fitted USB-C connector before SW4 fully
engages. The current V4.2 candidate removes that connector. The earlier printed fit does not qualify
HEAD: repeat MECH-1/MECH-1a on a current export before ordering, using the actual J1 mating plug and
cable.

Repeat this gate before ordering only if a revision changes the board outline, mounting pattern,
switch/speaker/connector placement, or maximum component height. `./build.sh` (or
`./build.sh step`) exports `fab/doorbell.step`; print it and check it against the original enclosure:

- **Board fits the housing (MECH-1).** Outline clears the housing walls/posts; the mounting holes
  (H1–H2) line up with the enclosure's bosses; nothing tall (U1, the latch relay K5, the
  electrolytics, the screw terminal) fouls a rib or the lid.
- **Connector access.** Fully seat the actual JST-SH mating plug and intended cable in J1 with the
  lid closed. Check cable exit, bend radius and strain as well as direct connector clearance; then
  confirm the Talk actuator still travels fully. J2's wire mouths must remain reachable to land the
  five bus wires once installed.
- **Switches fit + actuate (MECH-1a) — the point of the test.** The STEP model **deliberately omits
  SW3/SW4** (the `STEP_Exclude` field; see `tools/step_exclude.py`) — the door-release and talk
  front-panel buttons (`SPPJ322300`) — so you fit-test the printed board against the **real**
  switches and the housing's button apertures. Confirm each plunger tip lands under its aperture and
  that pressing the housing button fully actuates the switch (this is also what makes the manual
  buttons work unpowered, MODE-1a). SW1/SW2 are just the BOOT/EN commissioning tactiles — not
  enclosure-critical.

If anything fouls or misaligns, fix it in the PCB and re-print before committing the order. The
print is also a free sanity check on the 3D-model alignment (parts should sit min-z = 0 on the
board face).

## Files to upload

| Step | File |
|---|---|
| Gerbers | `fab/doorbell-jlcpcb.zip` (incl. the IPC-356 netlist for the E-test) |
| BOM | `fab/doorbell-bom-jlcpcb.csv` |
| Placement (CPL) | `fab/doorbell-cpl.csv` |

## The selections

- **PCB Type:** `Single PCB` (different designs in panel = 1)
- **Layers:** 4 (should auto-detect from the gerbers)
- **PCB Qty:** `5` — the minimum; you'll get 5 boards, assemble fewer
- ☑ **Confirm Production file** — JLCPCB prepares the manufacturing file (incl. the rails they
  add for assembly) and emails it for your approval. **Confirm within 48 h** or it auto-proceeds.
- **PCB Assembly:** ON
  - **Assembly side:** Top only (the board has no bottom-side parts)
  - **PCBA Type:** **Standard** — the current BOM is not Economic-eligible. Standard carries a
    per-side setup fee; the specialised parts (RF module, codec, LDO, PhotoMOS SSRs, latch relay,
    JST-SH service connector and bus terminal) may add per-type loading fees.
  - **Stock check:** confirm LCSC stock on the less-common Extended lines (the RF module, codec,
    LDO, SSRs, latch relay, JST-SH connector, screw terminal and door switches) against the current
    `fab/doorbell-bom-jlcpcb.csv` and the live JLCPCB import/quote. Do not carry a previous quote's
    stock or Basic/Extended classification forward.
  - **Through-hole parts:** J2 is assembled by JLCPCB; confirm THT
    assembly is included when JLCPCB reviews/quotes the order.
  - **Assembly Qty:** `2` — assemble one + a spare. The setup/part fees are already paid, so
    the second board is nearly free and cheap insurance against a dud.
- ☑ **Confirm Parts Placement** — JLCPCB checks rotation/polarity against their library and
  emails a placement preview. **Confirm within 72 h.**
- ☑ **Depanel boards & edge rail before delivery** — you get the individual boards freed from
  the frame (required anyway: the screw terminal must be clear of the rails).

## ⚠️ The two review gates — don't rubber-stamp these

### 1. Production file (48 h window)

The ~64 × 59 mm board is under the Standard-assembly minimum, so JLCPCB panels it with edge
rails ("Panel by JLCPCB"). When the production file arrives, check before approving that no rail,
break-tab or mousebite lands at **J2**; its wire mouths must stay clear.

Confirm the default solder-jumper state survived the production-file conversion: **JP1 and JP3 are
bridged in copper; JP2 is open**. They are PCB features excluded from the BOM/CPL, so the assembler
will not populate or correct them. JP3 enables the 200 kΩ TX precharge path and is cut only for a
diagnostic A/B test.

A tab/cut at J2 → **reject and comment**, and JLCPCB re-prepares it. Small mousebite nubs
elsewhere on the edges are fine as long as they're clear of parts. (No PCB-antenna edge to worry
about — the u.FL module's antenna is external.)

### 2. Parts placement (72 h window)

JLCPCB "corrects" to their library's orientation — usually right, occasionally wrong if their
pin-1 convention differs. Eyeball pin 1 / band direction on the polarity-sensitive parts against
the schematic, **worst-consequence first**. Identify the refdes from the BOM; the classes to
scrutinise:

| Class | Why it matters | If wrong |
|---|---|---|
| **Opto reverse-clamps D8/D9** (1N4148W anti-parallel across OC1/OC2 LEDs) | band/cathode must point to each opto LED's anode / bus-line net | **both bell-sense channels dead** — a silent failure until bench test; **scrutinise hardest** |
| **MCU** (ESP32-S3-WROOM-1U-N16R8) | pin 1 / rotation | dead board |
| **LDOs U2/U4** (SGM2212-3.3 and LP5907MFX-3.3, SOT-23-5) | pin 1 / rotation; do not treat the two pinouts as interchangeable | no 3V3/AVDD, or damage |
| **Codec** (ES8311, QFN-20, 0.4 mm pitch) | pin-1 dot | codec dead / damage |
| **USB ESD** (TPD2S017) | pin-1 — channels are in series with D± | USB dead / wrong clamp |
| **VBUS Schottky / TVS** (SS14 series, SMF5.0A clamp) | band direction | blocks VBUS, or shorts/leaves it unclamped |
| **PhotoMOS SSRs K1/K2/K3/K4/K6** | K1 GAQW212GS and K2 GAQY212GS are NO; K3/K4/K6 GAQY412EH are **NC**; confirm pin 1 and part value at every ref | a swapped NO/NC breaks the gong, door or P4-isolation fail-safe |
| **Physical Talk switch SW4 + R42/R43** | confirm the SPPJ322300 orientation/pin numbers: released 2↔3 grounds `K1_LED_RET`; pressed 2↔1 grounds `PTT_SW_N`, while 5↔4 makes the passive P3 Talk path. R42 is 10 kΩ and R43 is 1 kΩ | reversed switch action can disable K1 at rest, lose passive Talk, or invert/defeat physical-PTT sensing |
| **Latch relay K5 + flyback D1** | K5 is G6K-2F-Y DC12; confirm pin 1 and both pole mappings. D1 is 1N4004W with A4 top code; its cathode band faces `K5_LATCH` | no seal-in/sense, a defeated K6 interlock, or wrong flyback |
| **K6 return sense R35/R44** | R35 is 10 kΩ from +3V3 to `K6_RET`; R44 is 100 kΩ (existing BOM part C25803) from `K6_RET` to GPIO4/`K5_SENSE_N`. Confirm neither resistor lands on the wrong side of R44 | a GPIO fault can bypass K5's physical K6 interlock, or session sense can float/invert |
| **Door FETs Q3/Q4** | each is an AO3400A SOT-23 (1=G, 2=S, 3=D); reconcile rotation separately | door break-before-make or watchdog dead |
| **Codec clamps D13/D14/D16/D17 and AVDD block D18** | tiny X3-DFN LMBR01S30ST5G; pin 1 is cathode — match each pin-1 mark to its schematic net | codec over/under-rail protection or AVDD feed defeated |
| **Crossover C19** | EEEFK1H220P is polarised: pin 1 (+) faces `CHIME_POS`/P4 and the negative stripe faces P5 | passive gong/listen path degraded or capacitor overstressed |
| **Service connector J1** | SM04B-SRSS-TB pin order and side-entry orientation; compare the placement preview with the real mating-plug approach | reversed power/USB wiring or an inaccessible connector |
| **Power LED** | anode/cathode | just won't light (harmless) |

## Cost expectations

The PCB itself is the *small* line. On Standard PCBA the setup, loading/feeder fees for Extended
parts, assembly, stencil and parts dominate. Treat the live import/quote as authoritative for prices
and classifications; they change independently of the source tree. You only pay assembly on the
1–2 boards you choose to populate.

## Why this route (one-liner)

Standard PCBA assembles the whole board — SMT and the THT connectors — with JLCPCB handling fab
and the edge-rail panel of the small board. Watch the J1 and J2 edges at the Confirm gates, and
triple-check the opto-clamp polarity at the placement gate.

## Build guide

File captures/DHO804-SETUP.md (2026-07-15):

# DHO804 setup for bench welcome-audio captures

This is the repeatable setup for capturing a complete embedded welcome file, including its onset, on
the Rigol DHO804 at `osci.beutner.name`. Do not rely on the scope's retained state: a flat battery or
power cycle can reset acquisition, trigger, coupling, probe and scaling settings independently.

The settings below are for the current bench connection: **CH1 on P3, physical probe at 1×, bus not
connected**. If the intercom bus is connected, first apply the isolation and grounding rules in
`VERIFICATION.md`; do not copy this bench grounding arrangement onto a live bus.

## Known-good full-file setup

Use these settings for the 6.123 s Windows welcome file:

| Setting | Value | Reason |
| --- | --- | --- |
| Channel | CH1 enabled, 1× probe, AC coupling | Matches the physical P3 probe and removes the DC pedestal |
| Vertical | 200 mV/div, 0 V offset | Shows the roughly 1.75 Vpp playback without clipping |
| Timebase mode | `MAIN` | A triggered acquisition does not work in ROLL mode |
| Horizontal | 1 s/div, +4 s offset | Produces a 10 s record from −1 s to +9 s around the trigger |
| Memory | 1 Mpts | Gives 100 kSa/s over 10 s, ample for audio and transient inspection |
| Trigger | Edge, CH1, rising, 200 mV | Audio triggers even when there is no separate switching impulse |
| Sweep/run | NORMAL, SINGLE | Captures once and leaves the result frozen |

The order matters after a reset. Stop the scope, select MAIN, temporarily select automatic memory,
set the timebase, then select 1 Mpts. A fixed deep-memory setting can otherwise constrain or reject a
slow timebase change.

```text
:STOP
:TIM:MODE MAIN
:ACQ:MDEP AUTO
:TIM:SCAL 1
:TIM:OFFS 4
:ACQ:MDEP 1M
:CHAN1:DISP ON
:CHAN1:PROB 1
:CHAN1:COUP AC
:CHAN1:SCAL 0.2
:CHAN1:OFFS 0
:TRIG:MODE EDGE
:TRIG:EDGE:SOUR CHAN1
:TRIG:EDGE:SLOP POS
:TRIG:EDGE:LEV 0.2
:TRIG:SWE NORM
:SING
```

## Arm before starting playback

After `:SING`, poll `:TRIG:STAT?` until it returns **`WAIT`** before pressing the ESPHome playback
button. This takes roughly 1.5 s with the settings above. The 10 s record has 1 s of pre-trigger memory,
and the DHO804 must fill it before it can preserve the onset. Starting after only 0.5 s produced a
valid-looking trace whose left edge was already mid-file.

If the status remains `RUN`, do not start playback: either the pre-trigger buffer is not ready yet or
the memory/timebase changes did not land in the required order. A correctly armed NORMAL single
acquisition returns `WAIT`; after the trigger and record complete it returns `STOP`.

Avoid putting an LLM/tool round trip between arming and playback. Configure the scope, wait for `WAIT`
and POST the select/button endpoints in one local command or script:

```text
POST http://192.168.3.78/select/Next-ring%20greeting/set?option=Windows
POST http://192.168.3.78/button/Play%20Welcome%20Sound/press
```

Wait at least 9 s after the button press. The single acquisition should then be stopped already; send
`:STOP` once more before reading memory, and leave it stopped so the complete waveform remains on the
scope display. A status query with a short socket timeout can time out while the scope finalizes 1 Mpt
of deep memory. Reconnect and use `capture.py`, whose STOP wait allows up to two minutes.

## Read the frozen waveform

Use `capture.py --screen`, not `--record`: `--record` deliberately uses AUTO/free-run acquisition and
is not an onset-trigger workflow. `--screen` reads the frozen deep memory and trims it to exactly what
the display shows.

```sh
cd captures
.venv/bin/python capture.py --screen --channels 1 --probe 1 --out welcome-windows
```

For temporary analysis without adding a run under the repository, an absolute output path works:

```sh
.venv/bin/python capture.py --screen --channels 1 --probe 1 \
  --out /tmp/welcome-windows --no-plot
```

## Failure signatures

- **Display says `Waveform View(ROLL)`**: trigger acquisition is not configured. Stop, set MAIN, and
  reapply NORMAL + SINGLE.
- **Trace begins with substantial audio at the left edge**: playback began before pre-trigger memory
  was ready. Re-arm and require `WAIT` before the button press.
- **Only idle is captured**: playback was triggered after the acquisition window. Keep arm, wait and
  HTTP button press in one local operation.
- **Amplitude is off by exactly 10×**: the scope's probe ratio does not match the physical 1× switch.
- **RAW read fails or returns incomplete memory**: explicitly stop the scope and wait for `STOP` before
  running `capture.py`.
- **Settings appear not to land after a battery reset**: reapply the entire sequence in the order
  above; do not patch individual remembered settings.

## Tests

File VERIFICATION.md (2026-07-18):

# Verification — how to check the board before fab

This is the **procedure** for verifying a board before fabrication, not the log of any one run. The
`kicad/doorbell.kicad_sch` / `.kicad_pcb` are authoritative; everything here is a way to
confirm them — the automated gates, an independent schematic review, the bench tests against the
real TV20/S — before committing money to a fab order. Re-run it whenever the schematic or PCB
changes materially.

The aim is to catch the three failure classes that survive ERC/DRC and only show up as a dead or
mis-behaving board: **polarity**, **pin-mapping**, and **pin-usability** (a strapping/input-only
pin used in a way that breaks boot or can't drive its net).

---

## 1. Automated gates

Run `./build.sh verify` and require it green before anything else — it runs the checks KiCad's
own ERC/DRC can't express and exports the fab outputs from the authoritative files:

- **ERC** — 0 errors. Expect only benign warnings (pin-type "unspecified vs passive/power" on the
  screw terminal / buttons / LDO; the informational `GND`/`P1` same-net note from the deliberate
  P1↔GND bond; cosmetic `lib_symbol_mismatch` if a placed SSR symbol drifted from the cached lib —
  re-sync the symbol and re-run so the schematic pin numbering provably equals the footprint).
- **DRC + schematic parity** — 0/0. The gate uses `--exit-code-violations` so any unexcluded
  violation fails the build, and `--schematic-parity` so a PCB that has drifted from the schematic
  also fails. Clearances are pinned to JLCPCB capability in `kicad/doorbell.kicad_dru`.
- **`check_pcb.py`** — placement PASS (edge connectors J1/J2 and U1 flush on their board edges;
  parts inside the outline).
- **`route.py`** — 0 unrouted nets; no over-limit copper-thieving float island wide enough to take a
  GND stitching via (too-narrow slivers are accepted).
- **Firmware** — `./build.sh firmware-test` resolves production and bench, builds the deterministic
  host target and executes the shared policy against the live HEAD/V4.2 schematic. It needs a
  `secrets.yaml` with `wifi_ssid`/`wifi_password` alongside the production files. Production must
  retain its installed V4.1 pin/audio profile; host-only GPIO4/GPIO47/GPIO48 behavior is not evidence
  that fabricated V4.2 hardware has passed commissioning.

Green gates verify the files without rewriting generated artifacts. The `fab/` outputs may lag the
schematic — **run `./build.sh` before ordering** to repeat verification and export a matched release
set so the Gerbers, BOM, CPL, PDF and STEP agree.

### 1.1 Deterministic firmware fixture

Use `cd sim && npm test` for every circuit and firmware test, `npm run test:circuit` for circuit-only
iteration, or `./build.sh firmware-test` / `npm run test:firmware` for the firmware gate. Once config
and host compilation are already green, `npm run test:firmware:scenarios` skips only those duplicate
setup checks. Each scenario has an isolated process, preferences directory and
Unix socket. The virtual clock can start immediately before 32-bit rollover and advances only when
the schematic runner returns a firmware deadline, external stimulus or GPIO threshold transition;
wall-clock slowdown must not change the event trace.

The lab fixture drives the connector through the measured nominal 90 Ω source impedance and validates
U1/P1–P5 mapping from the live schematic rather than a generated netlist. The same fixture also has a
capture-calibrated TV20/S environment used by circuit regressions: it composes either the HEAD or the
reference WF26 endpoint with the live neighbour topology and reproduces only the explicitly supported
terminal behavior recorded in its evidence manifest. The environment observes P1–P5 only, never DUT
implementation state. Its bounded codec stimulus and connector/environment sources verify the board/firmware
contract, including K5-gated K6, physical-Talk ownership, the 30 s candidate passive-listen window and
door pulse/re-arm serialization—not unobserved TV20/S internals. Treat all results as HEAD/V4.2 candidate
evidence only and still perform §5.5/§6 on fabricated hardware.

### 1.2 Interactive firmware/circuit smoke check

Run `cd sim && npm run dev`; the server must incrementally compile the host target before printing its
URL. Open the default `doorbell` board and confirm the firmware state becomes connected in the TV20/S
environment. There is no local-firmware bypass: firmware policy controls U1/U3 for every doorbell
session. Pause, queue an own or neighbour ring, and confirm no voltage, relay or environment state
changes; single-step 1 ms and confirm the event begins at that virtual-time boundary. Resume at 1× and
select 10×/max; virtual time must remain stopped while paused and advance monotonically at each
selection. Exercise a harmless HA-connected toggle and greeting selection, then confirm the ordered
command/entity/write entries appear in the firmware timeline.

Exercise own ring, one-neighbour ring, floor call, door and timeout separately. Press stock WF26 Talk
and confirm the documented 2.2 kΩ bridge enters the `talk` phase without firing the opener; audio gain
remains outside the synthetic model. On WF26, confirm P4 retains the session bias while
`R1_BRIDGE`/P3 falls near 1 V; on the main board, confirm `TALK_BRIDGE` instead remains at the P2-side
session bias while `TX_OUT`/P3 is low. These are opposite sides of the respective 2.2 kΩ resistor, not
equivalent internal net names. An unsupported overlap or other intermediate P2–P3 impedance must
stop with a missing-evidence error. Select the manual lab and confirm P2 defaults to a
90 Ω source while VBUS is ideal. An attempted ideal source on a firmware-owned output must fail clearly.
Freeze the firmware during an asserted output and confirm execution stops without changing the output
or the physical relay/capacitor/fuse/environment state at the paused boundary. With `DOOR_DRV` frozen
high, resume and confirm the independent watchdog releases K2 while the GPIO remains high. Reboot and
confirm outputs reset and a new host reconnects at the preserved virtual time. Full reset must instead
return circuit, firmware preferences and timelines to power-up state.
Selecting `wf26` creates the passive reference-handset endpoint in the same TV20/S environment and
hides firmware controls. Repeat the paused-ring boundary check and confirm its own `WF26_K1` latches;
the manual lab remains selectable for arbitrary passive-circuit sources.

This smoke check is an operator/UI check, not an additional qualification claim. It uses the same HEAD
fixture and bounded codec stimulus as §1.1; the synthetic environment claims only its capture-backed
terminal behaviors and does not validate fabricated V4.2 hardware.

## 2. Independent schematic review (do it blind)

The strongest check is to reconstruct the board's intent from primary sources **without** reading
DESIGN.md/REQUIREMENTS.md — so the review can't just echo the design's own assumptions. Work only
from:

- the netlist exported from the schematic (`kicad-cli sch export netlist`),
- the manufacturer datasheets (see §7),
- the reverse-engineered handset (`wf26/wf26.kicad_sch` + `wf26/wf26-schematic.md`),
- the STR TV20/S service plan (`docs/design/STR_TV20S_Schaltplan_Fehlersuchhilfe.pdf`).

Derive what each net *should* be, then compare to the schematic. Reconcile any disagreement with
DESIGN.md only **after** forming the independent view. Every active and polarity-sensitive part
gets checked against its datasheet for polarity, pin-mapping and pin-usability.

## 3. What to check, by subsystem

For each item, confirm against the datasheet and the netlist — don't restate values from the
schematic, read them from it.

**Switches / SSRs / latch relay**
- Each PhotoMOS SSR is the intended **form**: the talk/door gates idle **open** (1-Form-A, NO),
  the chime-mute and seal-in-break idle **closed** (1-Form-B, NC). Idle states must be fail-safe
  (no talk/door at boot; gong rings at boot; latch stays sealed) — see SAFE-6 / GONG-3 / DOOR-4.
- SSR LED drive: series R sets I_F into the part's datasheet window; gate pull-downs hold every
  SSR off while the GPIO floats at boot.
- Trace SW4 by physical pad number and switch state. Released, dry pole COM1 pin 2 must connect NC1
  pin 3 (`K1_LED_RET`) to GND; pressed, it must instead connect NO1 pin 1 (`PTT_SW_N`) to GND.
  The independent passive pole must connect COM2 pin 5 (`TALK_SW`) to NO2 pin 4 (P3) only while
  pressed; NC2 pin 6 is intentionally unconnected. Confirm R29 feeds `TALK_SW` from `K5_LATCH`,
  while R42 pulls `PTT_SENSE_N` to +3V3 and R43 alone joins it to `PTT_SW_N`. No bus net may reach
  the dry pole or GPIO47.
- Check SW4 loading against its own datasheet: the R42/R43 pressed current must exceed the switch's
  minimum resistive load, the combined K1 LED return must stay below its maximum, and the sense LOW
  must meet IO47 V_IL. Treat “non-shorting” as a within-pole guarantee only; it does not prove the
  relative timing of the two poles.
- The on-board latch relay (K5) replicates the handset's seal-in: coil across **P1↔K5_LATCH**, with
  normally-closed K6 passing raw P4 at rest; the primary NO contact seals `K5_LATCH` from P2. Confirm
  the auxiliary NO contact directly grounds `K6_RET` and gates K6's LED return, R35 = 10 kΩ pulls up
  that physical node, and R44 = 100 kΩ is the only connection from it to GPIO4/`K5_SENSE_N`. Check
  the worst-case R35/R44 divider against K6's recovery limits and GPIO4's V_IH/V_IL/leakage limits;
  no GPIO4 state may open K6 before K5 physically pulls in. Cross-check `sim/src/corners.js` and its
  permanent qualification test: it applies the maximum/minimum +3V3 values, opposing 1% resistor
  tolerances, ±50 nA GPIO leakage, GPIO thresholds and a 20% guard below K6's 25 °C recovery limits.
  Confirm contact mapping and flyback-diode orientation.
- Confirm the door pair reproduces S1's **break-before-make**: the NC seal-in-break opens before
  the door bridge closes (RC-delayed), and the max-on-time one-shot releases the bridge in bounded
  time (DOOR-4 / DOOR-5). Cross-check the timing in `sim/test`.

**Diodes / polarity** — confirm every diode against the **library pin-1 convention** (1N4148W
pin 1 = cathode in the CDFER JLCPCB lib) and its role: opto reverse-clamps anti-parallel across
their LEDs, the latch-coil flyback reverse-biased in normal operation, the VBUS series Schottky
passing VBUS, the VBUS TVS reverse-biased below its stand-off.

**USB service inlet + ESD** — J1 pin order is VBUS/D−/D+/GND; D4 points from raw VBUS into
VBUS_PROTECTED and blocks reverse input/back-feed. The ESD clamp is **flow-through** (connector on
the _In side, ESP on _Out) with VCC biased from fused +5V;
**no D+/D− swap** anywhere connector→clamp→GPIO; the fuse sits **upstream** of the TVS and LDO so a
clamp event blows the fuse (fail-safe).

**Power** — LDO pinout correct; input (VBUS − Schottky) leaves dropout headroom for the WiFi-TX
peak; C_in/C_out within the LDO's stable range.

**MCU** — check **every module pad against the datasheet pinout and the GPIO map in DESIGN.md**
(power/USB/I²S/I²C/SSR-drive/sense). Strapping pins must sit at valid levels at reset; no
input-only or flash-tied pin may be misused. Native USB D±/Serial-JTAG is the flash+log path.
Confirm IO5 is ADC1_CH4 and not a strapping pin. Trace the post-fuse monitor as
`+5V → R40 100 kΩ → VBUS_F_ADC → R41 10 kΩ → GND`, with C25 (100 nF) from the ADC node to GND;
the 11:1 ratio must keep the ADC node below 0.84 V even at D10's 9.2 V maximum clamp voltage.
Confirm U1 pad 24 is IO47 and available on the exact N16R8 module: it is not a strap, is not one of
IO35–37 occupied by octal PSRAM, and operates at 3.3 V on this variant. Do not carry that conclusion
to an ESP32-S3R16V-based module, whose IO47/IO48 domain is 1.8 V.

**Codec + audio coupling** — all pins + EP map to the datasheet; I²S direction correct (ASDOUT→ESP
DIN, DSDIN←ESP DOUT); CE strap sets the I²C address; the tap is **transformer-less** and
AC-coupled. Trace TX explicitly: `OUTP → R26 (2.2 kΩ) → C14 → TALK_BRIDGE → R28 (2.2 kΩ) →
TX_OUT → K1-ch2 → P3`; K1-ch1 applies the P2 handshake to `TALK_BRIDGE`. Confirm factory-bridged
JP3 and R38+R39 (100 kΩ each) form a 200 kΩ P2-to-`TALK_BRIDGE` precharge across K1-ch1, with a
nominal `(200 kΩ + R26) × C14 ≈ 202 ms` time constant. RX is a differential sense of line 2.
K1-ch2 must keep line 3 high-Z at idle despite the always-present precharge path.

Check the external codec clamps by pin number, not only by symbol appearance: D13/D14 pin 1
(cathode) → AVDD and pin 2 (anode) → OUTP/MIC1P; D16/D17 pin 1 → OUTP/MIC1P and pin 2 → GND.
D18 pin 2 (anode) faces U4 `AVDD_PRE`, pin 1 (cathode) faces AVDD, and R37 is 220 Ω AVDD→GND.
Confirm the exact diode sheet covers reverse voltage and the actual injection current; distinguish
its guaranteed 25 °C VF limit from any 0–50 °C estimate. Simulate both polarities of the full bus
envelope with the board unpowered, including sustained C14-short, and require AVDD to remain below
codec turn-on without raising +5 V or +3V3.

**Bell sense** — opto LEDs hardwired **anode → bus line, cathode → R_lim → P1**; anti-parallel
clamps limit reverse LED voltage; collectors held high by external pull-ups (firmware `mode:
input`). Confirm both active-low and idle-high margins across the expected line voltage, pull-up
tolerance and optocoupler CTR/dark-current spread. Record the assumed enclosure temperature range
and distinguish guaranteed datasheet limits from engineering estimates based on typical curves.

**Passive WF26 core** — the `WF26_*` parts reproduce the handset's door-release / talk / gong /
seal-in topology, so the board behaves like a plain WF26 unpowered (the SSRs/codec/optos are
additive on top). Confirm K6 is normally closed without board power, JP2 is open by default and
SW4's pins 4/5 still make the R29 passive Talk path without any logic supply; then compare the
underlying handset behaviour against `wf26/wf26.kicad_sch`.

## 4. Cross-checks against external references

- **Netlist vs the handset** — extract `wf26/wf26.kicad_sch` with `kicad-cli` and confirm the bus
  pin map, the door/talk split (door = direct P2↔P3 short; talk = 2.2 kΩ P4↔P3), the K5 coil across
  P1↔P4, and that the chime-mute sits in the C1 audio path (P4↔C1), not in line 4.
- **Intercom logic vs the TV20/S plan** — Türruf ≈ 12 VDC across terminals 4 & 1; ÖT bridges
  terminals 2 & 3; Etagenruf series-interrupts line 5; door ring = 3-chime gong, floor call =
  continuous tone. The session is held from P2 and ends via a P2 transition (door-open transfer or
  the ~60 s timeout) — cross-check against the `captures/runs/` bench captures.
- **Datasheet pinouts** — for any part whose pinout is image-only or sourced by proxy, confirm against the actual
  manufacturer datasheet before fab; an emitter/collector or pin-1 swap is a silent dead-channel.

## 5. Decision-worthy classes of finding to watch for

These are the kinds of issue this review exists to surface — judgement calls, not pass/fail:

- **Isolation deviation.** P1 is hard-bonded to board GND (no galvanic barrier) — a deliberate,
  measurement-justified SAFE-3 deviation. Confirm the TV20/S common is safe to bond to USB/PC
  ground and that no bus conductor floats at a mains-referenced potential; containment then rests
  on per-tap protection + the sacrificial F1 fuse (SAFE-7).
- **Electrolytic polarity vs the handset readout.** Establish the genuine handset's gong-capacitor
  polarity with a meter and confirm that the schematic, footprint and assembly orientation match it.
- **Pinouts confirmed by proxy** (see §4) — flag any part not yet checked against its own sheet.
- **Single-ended TX off OUTP.** The codec's differential negative half is AC-terminated, not
  driven — functionally fine, but the lever if the line-3 drive level proves marginal.

## 5.5 Bench bring-up with an emulated bus (before the real TV20/S)

Settle the board's own behaviour on the bench with a **current-limited PSU standing in for the
bus** before risking the real intercom. The TV20/S is, electrically, a current-limited standing
**+12 V rail on P2** (source impedance ~90 Ω — it sags 12 → 9.4 V under the ~29 mA seal-in load) plus
**~1 s +12 V pulses on P4/P5** for rings. A bench PSU at 12 V through a **~100 Ω series R into P2**
with a **low current limit** emulates both and adds a fault backstop the real bus doesn't. Everything
except the central's *active responses* (opener firing, gong tone, TX-out forwarding, timeout sink —
those are §6) can be exercised this way.

**Rig:** floating PSU (2-ch ideal, or 1-ch + a momentary button for the ring tap), a ~100 Ω resistor
on the P2 feed, an isolated/battery 2-ch scope, a DMM, and the board's own J1 5 V feed (via a current
meter if available). Flash `firmware/doorbell-bench.yaml` for these stages — the production
config minus the HA events (a bench ring would fire the real automations) plus direct debug
controls for K3, the door drive and K6 isolation, plus a diagnostic K5-contact input. **Ground
discipline:** P1 is hard-bonded to board GND *and* USB GND, so
`PSU− = P1 = USB-GND = scope-ground` is **one node** — float the PSU, isolate the scope, grounds on
P1 only; never tether a mains-earthed PC scope and PC-USB at once (the §6 isolation rule).

**Stage 0 — power-off continuity (DMM).** P1↔GND ≈ 0 Ω (the deliberate bond); no short P2/P3/P4/P5 to
each other or P1 (**P4↔P1 reads the K5 coil**, not a fault); USB VBUS↔GND not a dead short; F1
continuous; raw P4↔`K5_LATCH` continuous through K6; JP2 open; JP3 factory-bridged and, after
capacitors settle, P2↔`TALK_BRIDGE` ≈ 200 kΩ through R38+R39; `VBUS_F_ADC`↔GND ≈ 10 kΩ through
R41; TP1–TP8 present; C19 "+" toward P4. With SW4 released, verify pins 2↔3 are closed and pins
5↔4 are open; pressed, verify 2↔1 and 5↔4 close while 2↔3 opens. Confirm SW4 pin 6 is unconnected,
the dry pole has no continuity to P2/P3/P4/P5, and the passive R29 Talk path does not require local
power.

**Stage 1 — local power only, no bus.** J1 VBUS at 5 V → the 5 V rail **≈ +4.5–5 V at D4's cathode**
(after the SS14 drop — there is no 5 V test point), `VBUS_F_ADC ≈ +5V / 11` (about 0.41–0.45 V),
and the firmware's **Post-Fuse 5 V Supply** reading agrees with a DMM on +5V within ADC/resistor
tolerance. A complete supply or fuse loss cannot be reported because it also powers down the ESP32.
**TP2 ≈ +3.30 V**, quiescent current sane, board boots/joins WiFi/logs clean. **SAFE-6:** idle, then
  toggle each SSR from HA and confirm the contact flips at the pads — K1/K2 (NO) **open**, K3/K4 (NC)
  **closed** — validating each SSR + driver + GPIO map with no bus voltage present. Leave
  `Debug P4 Isolation` off; confirm GPIO48/`P4_ISO` is low and K6 remains closed. Do not exercise
  K6 until the passive K5 checks in 2a have passed. Measure GPIO47/`PTT_SENSE_N` at about +3.3 V
  released and about 0.30 V pressed. While commanding K1 on, press SW4 and verify both K1 contacts
  open even though `PTT_DRV` remains asserted; release returns control to the drive. Record the 5 V,
  +3V3, codec VMID, PTT-sense and idle-output voltages in the run-specific evidence log.

**Stage 2 — emulated bus** (`PSU+ → 100 Ω → P2`, `PSU− → P1`, 12 V, limit ~120 mA):
- **2a passive seal-in, board UNPOWERED (MODE-1/SAFE-4):** tap 12 V onto P4 ~1 s → K5 pulls in;
  release → confirm it **seals in** (`K5_LATCH` and raw P4 hold just under P2 through closed K6);
  pull P2 to 0 → K5 drops.
  Measure pull-in, sealed current/voltage and drop-out voltage; compare all three against the relay
  datasheet and the real-bus operating range.
- **2b ring sense, powered:** 12 V on P4 → "House Doorbell" asserts (clears on removal); 12 V on P5 →
  Etagenruf/OC2 asserts; non-detect ⇒ swap that LED's two bus connections (silent, not damage).
  Verify collector LOW/HIGH against the MCU's V_IL/V_IH limits, including long tone gaps and composed
  input states.
  **Cross-stress:** drive P4 high, confirm the idle OC2 cathode stays clamped near 0 (per-opto
  limiter + D9 fix).
- **2c door open (DOOR-4/5):** seal in, fire a door-open, 2-ch scope the seal-in node vs the P2↔P3
  bridge — measure K4 break before K2 make and compare with the current ~38 ms nominal delay
  (latch drops, P4 falls, live P4 never reaches P3);
  hold the command asserted and measure that the watchdog releases K2 after the minimum normal
  firmware pulse but before the specified maximum fault-on time.
- **2d K5-confirmed P4 isolation:** keep JP2 open and power the bench firmware. Before K5 pull-in,
  confirm `K6_RET` and GPIO4/`K5_SENSE_N` are HIGH and `Debug K5 Sense` is clear. Turn on `Debug P4
  Isolation` and verify GPIO48/`P4_ISO` goes high but the hardware interlock keeps K6 closed; turn
  the request off. Ring K5 in, confirm `K6_RET` and `K5_SENSE_N` go LOW and `Debug K5 Sense` asserts
  after its 5 ms debounce. Turn on `Debug P4 Isolation`, verify K6 opens,
  remove the raw-P4 drive and confirm K5 remains sealed from P2 while raw P4 is disconnected from
  `K5_LATCH`. Drop P2 and confirm K5 releases, the diagnostic clears and K6 immediately restores
  continuity even while the request remains high; then turn the request off. Finally bridge JP2
  temporarily and confirm it restores permanent P4↔`K5_LATCH` continuity.
- **2e chime-mute (GONG-1/4):** inject an AC tone on P4 → present at the speaker (P5↔P1) with K3
  closed, gone when mute asserts, P4/latch/sense untouched; a tone on P5 reaches the speaker
  regardless of mute.
- **2f physical Talk transition (FW-4/BUS-2):** seal in K5, assert smart K1, then scope repeated
  physical SW4 press/release cycles at the K1 handshake/output and R29/passive-Talk paths. Confirm
  the K1 outputs open despite a held-high drive and require no interval in which R28 and R29 conduct
  in parallel. Measure both assertion and release timing; the schematic steady-state check and the
  switch's per-pole non-shorting rating do not establish cross-pole timing. Repeat through the real
  housing actuator, not only by pressing the bare switch.
- **2g audio (partial):** RX — inject P2↔P1 and confirm the codec ADC sees it through the −18 dB divider,
  that a gong-level drive stays inside the codec rail [0, AVDD] (abs-max), and the signal lands on MICP
  with MICN held at VMID; TX — assert talk, drive a DAC tone, scope it on P3 through the TX resistor,
  confirm the populated reference and net from the schematic rather than assuming a revision-specific
  designator, and confirm high-Z
  when talk is off.

**Stage 3 — connector polarity, before energising (SAFE-2):** use continuity mode to verify J2 follows
the documented P1–P5 wire order and confirm C19 pin 1 (+) faces P4 through K3. Do not deliberately
mis-order the bus: the protected taps are bidirectional, but the field-proven WF26 crossover is polarized.

Do not proceed until these checks prove power, default-safe states, sense and polarity, latch
seal-in/drop mechanics, door break-before-make timing, watchdog operation and chime suppression.
The responses that depend on a TV20/S (TX-out reach, opener firing, real gong/levels/hum, timeout
sink and shared-bus interactions) carry over to §6.
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

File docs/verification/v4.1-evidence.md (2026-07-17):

# V4.1 verification evidence

This is a historical evidence record for the assembled V4.1 PCB. It is not a reusable verification
procedure and must not be treated as proof for a mechanically or electrically changed revision.
The reusable pre-fab procedure is `VERIFICATION.md`.

## Bench and field results

- The JLCPCB-assembled board seats in the original WF26 enclosure: the bosses, populated height,
  transducer and wire entry align and the lid closes. The door housing control works. The Talk
  actuator does **not** fully engage SW4 because it hits the fitted USB-C connector; this installed
  mechanical limitation was found after the earlier general fit statement.
- Local power measured 4.8 V after D4 and 3.3 V at TP2. The board booted and joined Wi-Fi. All four
  SSRs switched with their expected NO/NC idle states; direct bench operation of SW3 and SW4 switched
  both required poles, but does not override the installed SW4 actuator obstruction above.
- Codec bias measured TP4=3.3 V and TP8/VMID=1.65 V. A test tone produced a clean DAC output.
- The passive latch pulled in and sealed on the emulated bus. It released from the board door drive
  and from a falling P2 supply. Both optocoupler ring channels detected with the assembled polarity.
- Automated pull-in attempts, classified from OC1/P4 after the external ring source opened but before
  P2 was interrupted, gave 0/5 at 8.5 V and 5/5 at 9.0 V at room temperature. This bounds the
  observed V4.1 threshold between those values; it does not replace the relay's 9.6 V guaranteed
  must-operate limit or qualify another board revision/load.
- Door-open break-before-make measured approximately 33–34 ms from P4 falling (K5 released) to P3
  rising to P2 (K2 made), with no premature P3 pulse. Scope:
  [`../scope/door-break-before-make.png`](../scope/door-break-before-make.png) (CH1=P4, CH2=P3,
  both relative to P1, 10×, 5 V/div, 10 ms/div, CH1 6 V falling trigger).
- With the door command held continuously, the hardware watchdog released the door bridge after
  approximately 6–7 seconds, safely after the normal 1.75-second firmware pulse. After 250 ms with
  DOOR_DRV low, reassertion reproduced the normal 33–34 ms P4-fall→P3-rise delay, proving that the K2
  delay path functionally re-armed; P3 then remained at approximately 12 V for 5.7–5.8 s before the
  watchdog released it. Scope:
  [`../scope/door-watchdog-rearm-250ms.png`](../scope/door-watchdog-rearm-250ms.png) (CH1=P4,
  CH2=P3, both relative to P1, 10×, 5 V/div, 1 s/div, CH2 6 V rising trigger). A 500 ms repeat
  produced the same approximately 5.8 s timeout, closing the external functional re-arm check.
- Chime suppression passed electrically and acoustically on the tone rig while both ring sensors
  remained clean.
- K3 trapped-charge reclose passed ten commanded cycles with waits from 0–5 s and zero K5
  re-latches. A separate fail-safe test cut only the board's USB power while the 12 V emulated bus
  remained live: K3's hardware-default reclose produced a brief P4 pulse peaking around 5–6 V,
  falling immediately to roughly 2 V and decaying within about 300 ms, with no 12 V seal-in. Scope:
  [`../scope/k3-usb-power-loss.png`](../scope/k3-usb-power-loss.png) (CH1=P4 relative to P1, 10×,
  5 V/div, 100 ms/div, 2 V rising trigger).
- TX produced approximately 0.55 Vrms at 1 kHz on floating P3 with PTT on. RX delivered 240 mVpp at
  MIC1P from approximately 1.5 Vpp on P2 and measured −25.7 dBFS against a −79 dBFS analog floor.
- The installed board reliably rings, seals in, opens the door and operates in normal service on
  the real TV20/S system.

## Ordered-part checks closed after the original review

- D14 BAT54SW, LCSC C22466373: SOT-323 pin 1=A/GND, pin 2=K/+3V3,
  pin 3=COM/MIC1P.
- Q3/Q4 AO3400A, LCSC C20917: SOT-23 pin 1=G, pin 2=S, pin 3=D. The manufacturer sheet specifies
  Vgs(th)=0.65–1.45 V and Igss=±100 nA.

## Prefab-review warning disposition

- IC-pin clamp edges: accepted only with codec-before-PTT sequencing; optional clamp-rail hardening
  remains available.
- D1 held-floor-call stress: open measurement because available P4 captures disagree.
- K5 pull-in: V4.1 room-temperature boundary measured between 8.5 and 9.0 V. The real ring bus is
  approximately 12 V versus the relay's 9.6 V guaranteed must-operate limit; V4.2 adds only the
  negligible 100 kΩ R36 load. Treat latch/seal-in as routine first-board bring-up, not a low-voltage
  fabrication gate.
- Door retrigger: 250 ms off restores the external break-before-make assertion sequence and a
  5.7–5.8 s watchdog interval; 500 ms produces the same result. The retained 0.5 s firmware minimum
  is externally validated.
- Watchdog: V4.1 bench pass at approximately 6–7 s; contamination/humidity and other revisions
  require their own measurement.
- LDO capacitance, LP5907 PSRR headroom, U2 thermal behavior and codec rail decay: retain as bench
  gates for subsequent boards.
- SSR LED drive: direct ESP32-S3 drive is field-proven for every actuator, including the dual-LED
  PTT and door outputs, with V4.1's 300 Ω series resistors. V4.2 uses 220 Ω for additional
  operate-current margin; no buffer stage or separate fabrication gate is required.
- D10/J3: accepted with keyed-harness polarity control; a current-limited reversed source may not
  clear the fuse.
- Codec/PTT click: codec output must settle before K1 closes and K1 must open before codec shutdown.
- D6 orientation: visually verify CPL/first-article orientation because datasheet terminal numbering
  differs from the footprint's pad-1 convention.

## Documentation corrections made after the review

Current-design descriptions use R26 for the codec TX resistor; historical V4.1 measurements that
name R28 remain historical facts. Simulator comments were updated to the later 10 MΩ watchdog
value, and the floor-call notes now correctly describe direct per-channel optocoupler emitter
returns rather than a shared emitter resistor.

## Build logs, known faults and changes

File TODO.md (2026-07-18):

# TODO

Open work before ordering and commissioning V4.2. Canonical handset numbering is Pₙ = line n;
see `DESIGN.md` and `wf26/wf26-schematic.md` for the circuit model. The current KiCad sources are a
candidate, not a finalized or fabricated V4.2 board.

Priority rates how important it is to get the item right for V4.2: **10/10** is essential to safety,
core function or long-term reliability; **1/10** is optional polish. It does not replace dependency
order—for example, some firmware work must wait for fabricated hardware regardless of its score.

## Pre-order gates

- [ ] **8/10 — Repeat the current V4.2 enclosure fit with the actual J1 plug and cable.**
      Export and print `fab/doorbell.step` from the final source, fit the board with real SW3/SW4
      and the fully seated SM04B-SRSS mating plug/cable, then close the lid. Verify H1/H2 seating,
      connector and cable clearance/bend/strain, both front-panel actuators' full travel, and J2 wire
      access. Record the export revision and result before approving the order. V4.1 seats in the
      enclosure, but its fitted USB-C connector prevents SW4 from fully engaging; the current V4.2
      candidate removes that connector, yet neither that change nor the earlier printed fit qualifies
      the current HEAD.
      - **Worst case:** the assembled V4.2 board or service cable obstructs the Talk/door actuator or prevents the enclosure from closing, forcing a respin.

## Firmware (`firmware/doorbell.yaml`)

The deterministic host adapter implements the expected versions of the V4.2 policies below so they
can be exercised against the live HEAD circuit. These tasks remain open for production/bench enablement
because the installed target is V4.1 and the changed GPIO4/GPIO5/GPIO47/GPIO48 hardware is not
fabricated or qualified. Gating host scenarios cover those candidate policies; the open checkboxes
keep the separate fabricated-board and production-enablement boundary visible.

- [ ] **4/10 — Enable the post-fuse supply diagnostic after V4.2 power bring-up.**
      The installed V4.1 board has no R40/R41/C25 divider, so production must leave GPIO5 unused and
      must not expose a meaningless `Post-Fuse 5 V Supply` entity. Keep the ADC sensor in the V4.2
      bench firmware for bring-up. After confirming `VBUS_F_ADC` against a DMM and validating its
      divider, filter and GPIO5 mapping on fabricated hardware, add the diagnostic to production.
      It can report supply sag but cannot report complete power loss because that also stops the ESP.
      - **Worst case:** enabling it before the divider exists publishes floating, misleading supply telemetry.

- [ ] **9/10 — Implement K5-confirmed P4 isolation only after a fabricated V4.2 board passes passive bring-up.**
      Keep the deployed V4.1 safeguards meanwhile: OC1 remains its session/ring input, the 1.45 s
      ring-to-audio `welcome_not_before_ms` guard remains enabled, and ring-to-open remains at least
      1.75 s. After confirming unpowered P4↔
      `K5_LATCH` continuity, K5 seal-in and JP2-open operation on V4.2, add GPIO4 `K5_SENSE_N`
      (active low through R44) and GPIO48 `P4_ISO` (active high, forced low at boot). Configure GPIO4
      strictly as an input with both internal pulls disabled; its released-state bias comes through
      R44 from R35 on `K6_RET`, not from a GPIO-side pull-up. Debounce `K5_SENSE_N` for 5–10 ms,
      request isolation, wait K6's maximum opening time, reconfirm K5, then allow K1/playback. Loss of
      K5 must stop playback, release K1 and clear `P4_ISO`; keep raw OC1 for ring diagnostics. K6
      removes only this endpoint's raw-P4 contribution: do not treat K5 sense or isolation as a
      neighbour-busy detector, and do not claim that it suppresses audio already on shared P2. Only
      after installed-board validation may the own-P4 portion of the ring-to-audio guard be retired;
      retaining a conservative guard is acceptable for V4.2. Keep the 1.75 s minimum ring-to-open
      deadline regardless of greeting selection.
      - **Worst case:** incorrect isolation sequencing drops the session or leaves welcome TX contaminated by local P4 gong energy; shared-P2 neighbour audio remains an accepted bus limitation.

- [ ] **8/10 — Add and qualify GPIO47 physical-PTT sensing after the V4.2 hardware check below passes.**
      The candidate now implements active-low `PTT_SENSE_N` with R42/R43 and SW4 pins 1/2/3; it is
      independent of P4/K5 and mechanically opens K1's LED return while pressed. After validating
      the fabricated circuit, add the input to production and bench firmware using the fitted
      external pull-up (leave the MCU's internal pulls disabled), explicit active-low polarity and
      measured assertion/release debounce. Expose a bench diagnostic, command K1 off whenever
      physical Talk is asserted even though the hardware already inhibits it, stop the media player,
      clear `P4_ISO`, release K3 so the passive crossover is restored, and wait the measured K6/K3
      release interval before declaring manual Talk ready. Hold K1 off and keep the passive path
      restored through the entire press and a stable release debounce before allowing smart PTT or
      chime suppression again. Do not treat this switch state as proof of a session or as a
      neighbour-gong detector. Hardware does not force K3/K6 passive during a powered MCU stall; that
      rare loss of manual audio is accepted, while SW4 still excludes smart K1 and power loss restores
      normal passive operation.
      - **Worst case:** wrong polarity/debounce defeats manual-conversation policy, chatters K3/K1, or re-enables smart Talk during the physical switch transition.

- [ ] **9/10 — Serialize every production door command through one firmware coordinator.**
      Replace direct production access to `front_door_buzzer_bin` with a single script used by the HA
      button, auto-open, greeting/open actions and API actions. Before DOOR_DRV rises, stop/cancel
      playback, command K1 off and wait its release margin; clear `P4_ISO` and wait K6's maximum close
      time so breaking K5 cannot make a still-high raw P4 alternately repull K5 and reopen K6. Keep
      isolation clear until DOOR_DRV is low and K5 is inactive. Enforce at least 500 ms continuously
      low between door pulses so C18/Q3 fully re-arms the K4-before-K2 delay; coalesce or reject repeat
      requests during the active pulse and re-arm interval. Keep the bench's deliberate raw hold
      control diagnostic-only. Add simulator regressions for isolation + early door, K1 + door, and a
      rapid repeated command with a newly latched session.
      - **Worst case:** overlapping TX/door corrupts the shared speech pair, early door release makes K5/K6 chatter while raw P4 is high, or a rapid repeat bypasses break-before-make and the watchdog's intended re-arm.

- [ ] **8/10 — Replace the interim full-session K3 mute after a PTT-capable V4.2 board is fabricated and validated.**
      Production and bench firmware currently keep K3 open whenever chime suppression is effectively
      requested. This prevents a later neighbour gong on shared P2 from reaching LS1 through our
      sealed K5, but deliberately disables passive LS1 listen and the physical SW4 microphone in
      suppression mode. Keep smart TX independent of K3. Once the resulting board passes K5/K6 and
      SW4-sense/interlock bring-up and the GPIO47 input above is qualified, define and validate a
      manual-conversation state: decide when passive listening is intentionally restored, whether it
      persists for a bounded window after Talk is released, and how K1/K3/K6 transition without
      forwarding a gong. The PTT task above defines the minimum press/release hand-off; this task owns
      the longer-lived listening policy. Keep K1 commanded off across the entire physical-Talk window
      and release debounce even though SW4 also inhibits it in hardware.
      The desktop-only HEAD adapter uses a testable candidate rule meanwhile: restore K3 immediately
      for physical Talk, retain passive listening for at most 30 s after stable release while K5 remains
      confirmed, and end that ownership sooner on K5 loss, smart TX or a door request. This is not a
      production decision until the fabricated-board checks qualify the transition and gong exposure.
      - **Worst case:** restoring passive audio recreates the neighbour-gong leak or a transition presents an unqualified ~1.1 kΩ P2↔P3 bridge.

## First-board commissioning (not fabrication gates)

- [ ] **6/10 — Close the deliberately unsupported TV20/S simulator states only from new captures.**
      The documented stock 2.2 kΩ Talk handshake is already a supported simulator state. Capture P2
      and P3 with a known injected audio level to calibrate the TV20/S transfer gain, and sweep
      intermediate P2–P3 impedance far enough to locate the no-opener/opener boundary without risking
      the installation. The simulator composes the already-calibrated own-ring and direct-door
      terminal equivalents for local auto-open; separately capture a neighbour/foreign door action
      during its gong, simultaneous floor/front calls and more than one concurrent stock session. Add
      each behavior to `sim/src/tv20s/capture-evidence.json` and its calibration only after channel
      identity and topology are recorded; until then the simulator must continue to reject it rather
      than extrapolate.
      - **Worst case:** guessed central-unit behavior makes a firmware scenario look safe or functional when the installed TV20/S responds differently.

- [ ] **8/10 — Validate SW4 physical-PTT sense and the K1 hardware interlock on fabricated V4.2 hardware.**
      Confirm the fitted switch orientation and actual housing actuator first. With logic power off,
      verify the passive pins 5↔4 Talk contact and R29 path still work. With local power on, measure
      `PTT_SENSE_N` high when released and about 0.30 V when pressed. Hold `PTT_DRV` asserted and
      prove that pressing SW4 opens both K1 output contacts even if the GPIO remains high. Finally,
      with K5 sealed, scope repeated press/release transitions at the K1 and R29 paths: the switch is
      non-shorting within each pole, but its datasheet does not guarantee relative pole timing, so
      require no interval in which the smart R28 and passive R29 handshakes conduct in parallel.
      Record voltages, debounce times and the worst transition before enabling the firmware policy.
      - **Worst case:** a wrong switch orientation or cross-pole overlap defeats sensing/interlock, loses passive Talk, or briefly presents ~1.1 kΩ instead of the intended 2.2 kΩ handshake.

- [ ] **5/10 — Calibrate the V4.2 audio path on the installed board.** Confirm RX headroom and choose the final
      mic PGA; set TX to a natural handset level; and listen for hum or an objectionable first-welcome
      onset transient. The retained I²S path and DAC soft-ramp have removed the codec-start transient
      on the V4.1 bench board; on V4.2, verify that factory-bridged JP3 plus R38+R39 also remove the
      remaining K1/C14 bias step on the real bus. Cut and re-bridge JP3 only if an A/B diagnosis is
      needed. The divider and output protection are already bounded by simulation and bench
      measurements, so the remaining checks tune firmware and validate the changed V4.2 analog path.
      `docs/scope/welcome-chime-p3.png` records the earlier V4.1 observation.
      - **Worst case:** installed speech or welcome audio is too quiet, clipped, noisy or unpleasant to use.

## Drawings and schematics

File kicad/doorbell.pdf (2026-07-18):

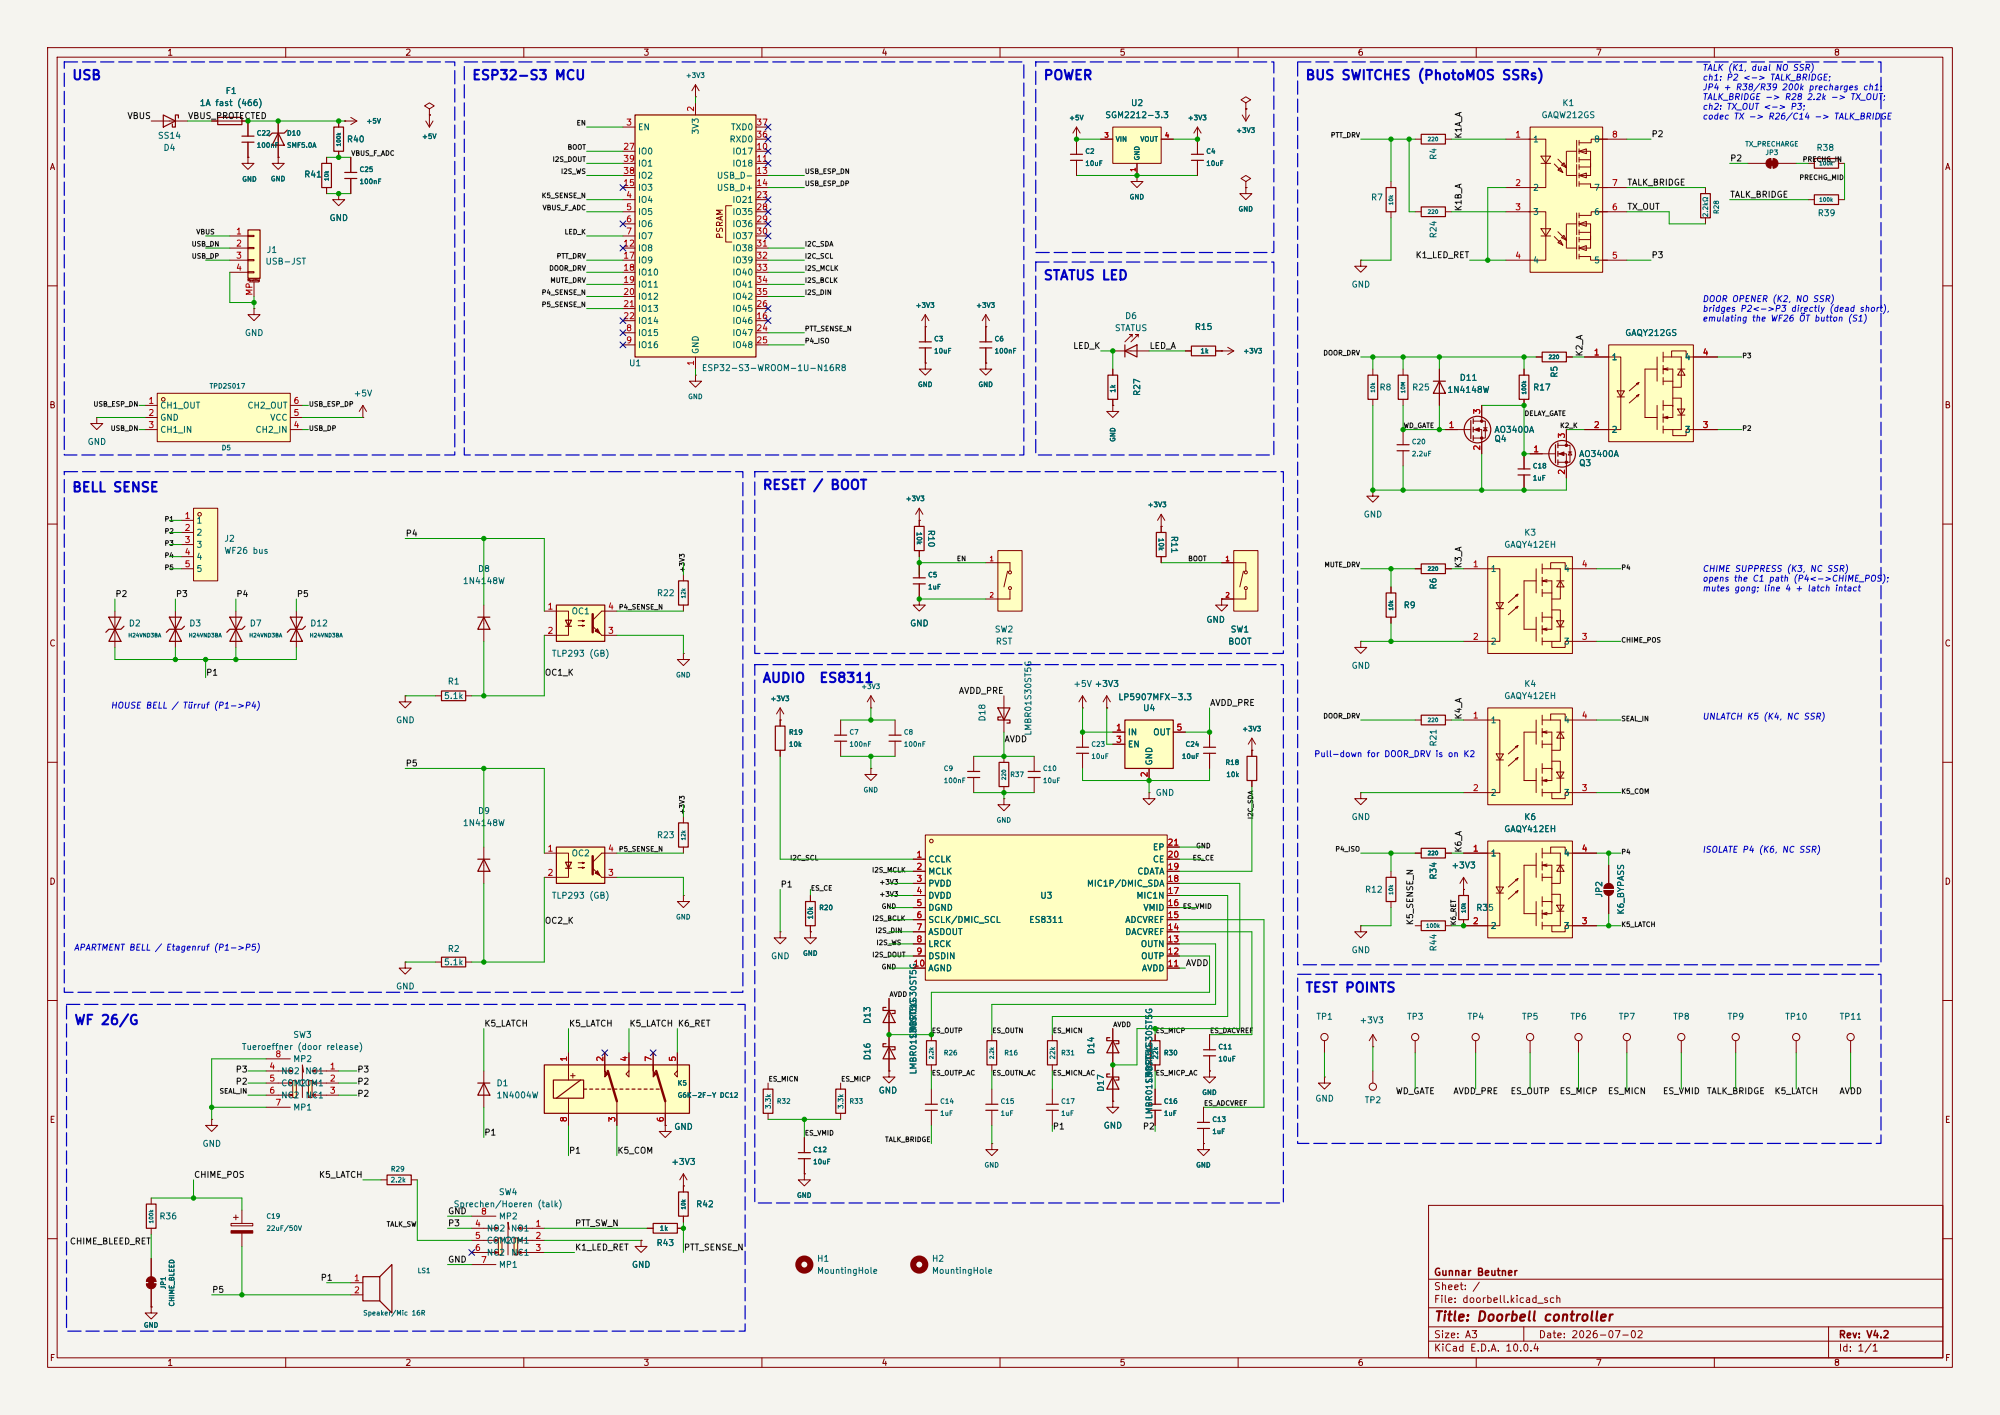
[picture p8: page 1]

BUS SWITCHES (PhotoMOS SSRs)

TALK (K1, dual NO SSR) ch1: P2 <-> TALK_BRIDGE; JP4 + R38/R39 200k precharges ch1; TALK_BRIDGE -> R28 2.2k -> TX_OUT; ch2: TX_OUT <-> P3; codec TX -> R26/C14 -> TALK_BRIDGE D11

DOOR OPENER (K2, NO SSR)
bridges P2<->P3 directly (dead short),
emulating the WF26 ÖT button (S1)

CHIME SUPPRESS (K3, NC SSR) opens the C1 path (P4<->CHIME_POS); mutes gong; line 4 + latch intact AUDIO ES8311

ISOLATE P4 (K6, NC SSR) HOUSE BELL / Türruf (P1->P4)

Size: A3 | Rev: V4.2
KiCad E.D.A. 10.0.4 | Id: 1/1 | F Date: 2026-07-02

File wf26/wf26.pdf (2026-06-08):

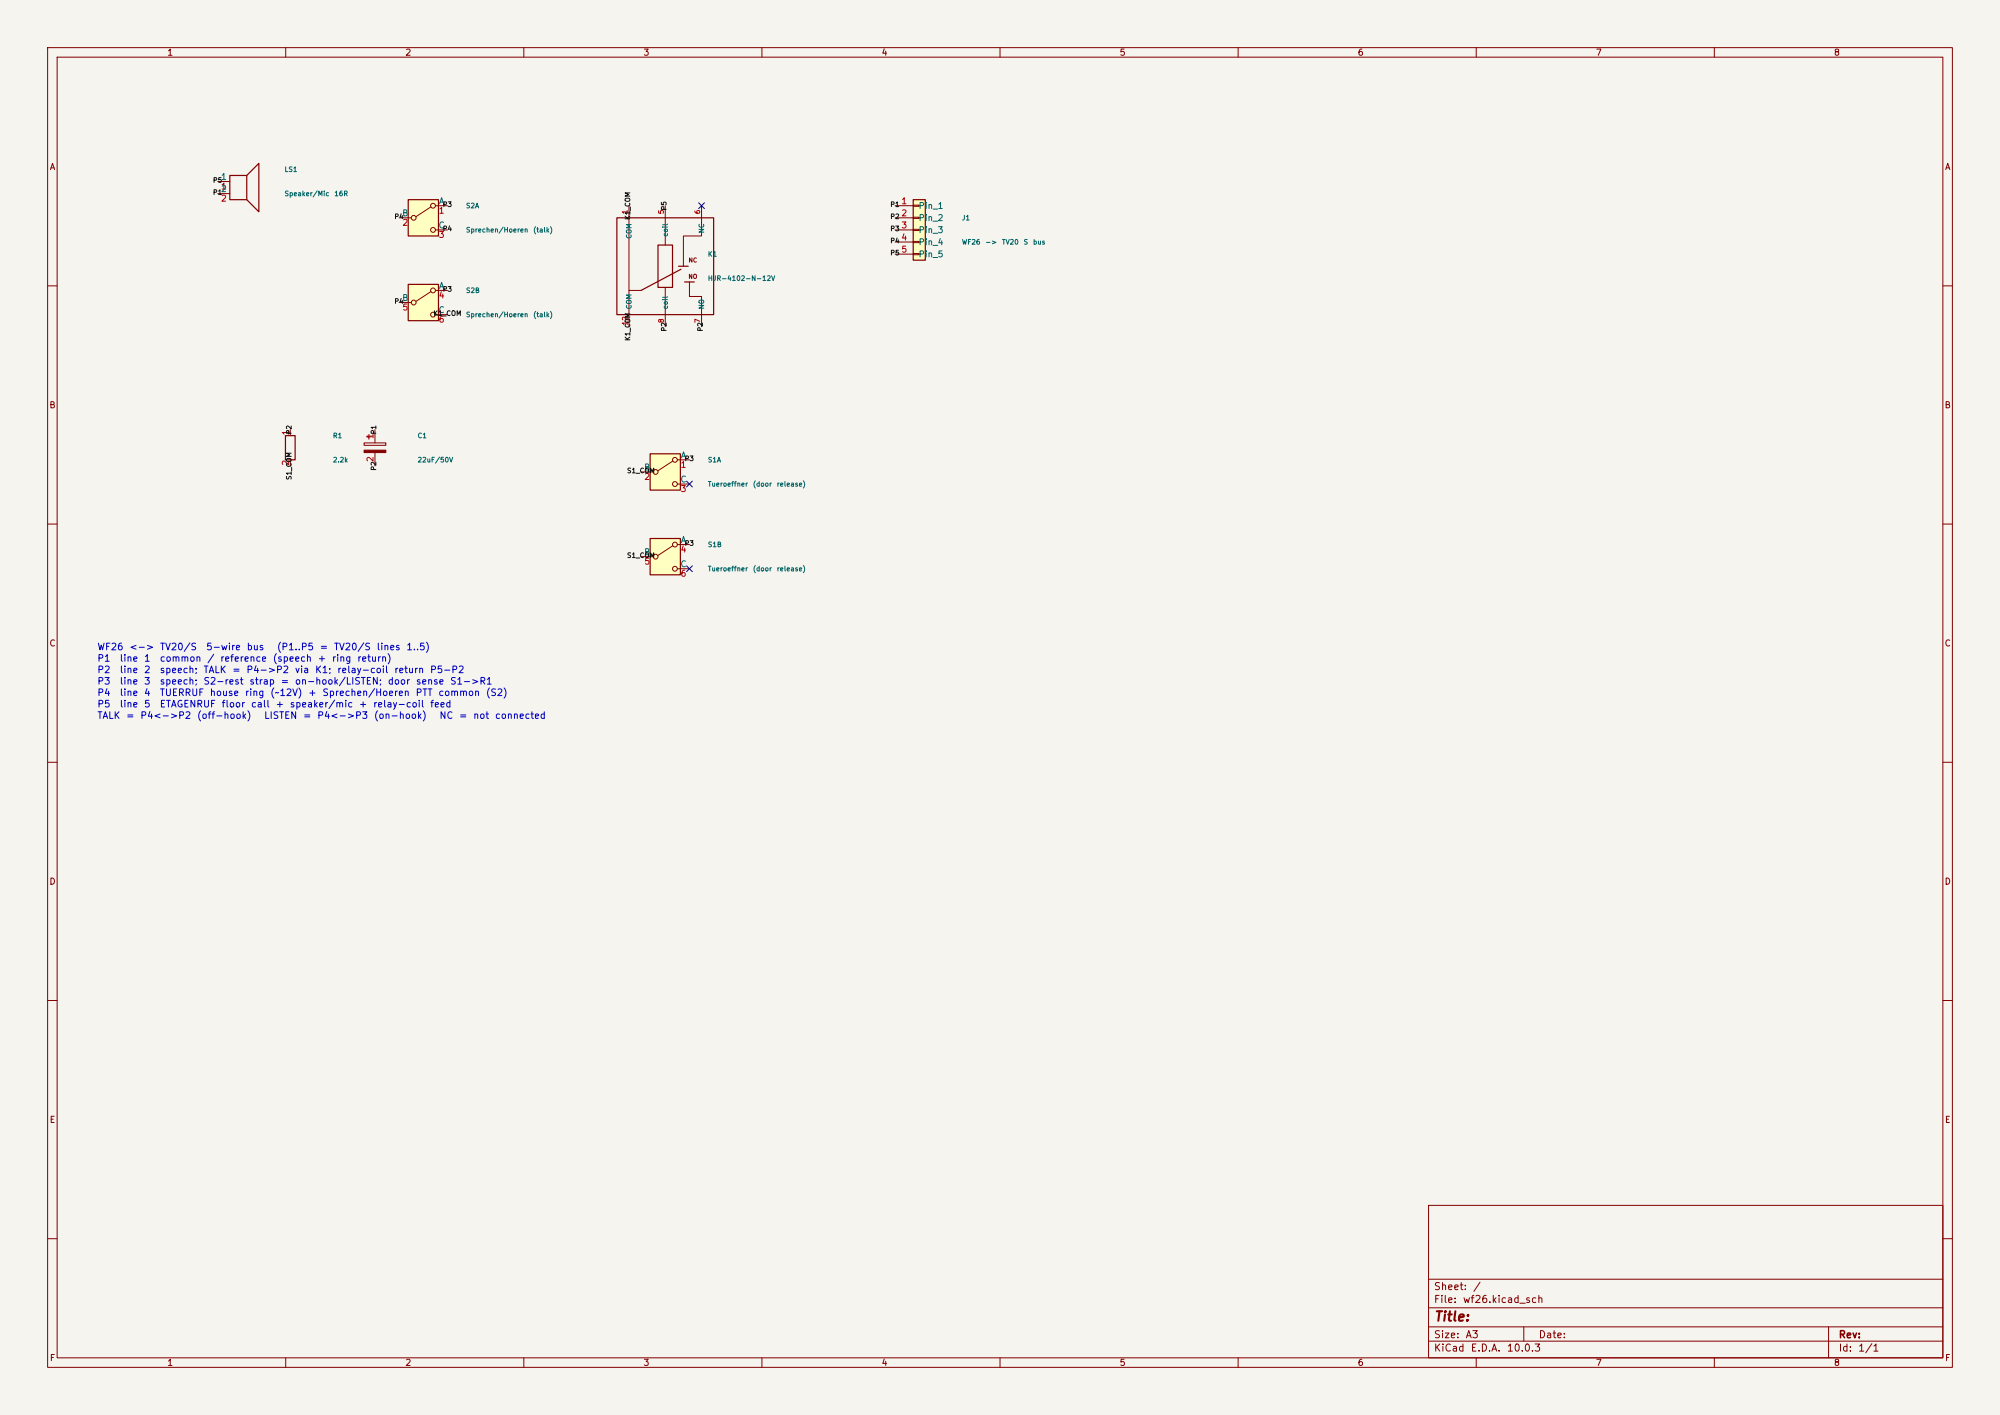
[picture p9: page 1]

TALK = P4<->P2 (off-hook) LISTEN = P4<->P3 (on-hook) NC = not connected P5 line 5 ETAGENRUF floor call + speaker/mic + relay-coil feed P4 line 4 TUERRUF house ring (~12V) + Sprechen/Hoeren PTT common (S2) P3 line 3 speech; S2-rest strap = on-hook/LISTEN; door sense S1->R1

Size: A3 | Rev:
KiCad E.D.A. 10.0.3 | Id: 1/1 | F Date:

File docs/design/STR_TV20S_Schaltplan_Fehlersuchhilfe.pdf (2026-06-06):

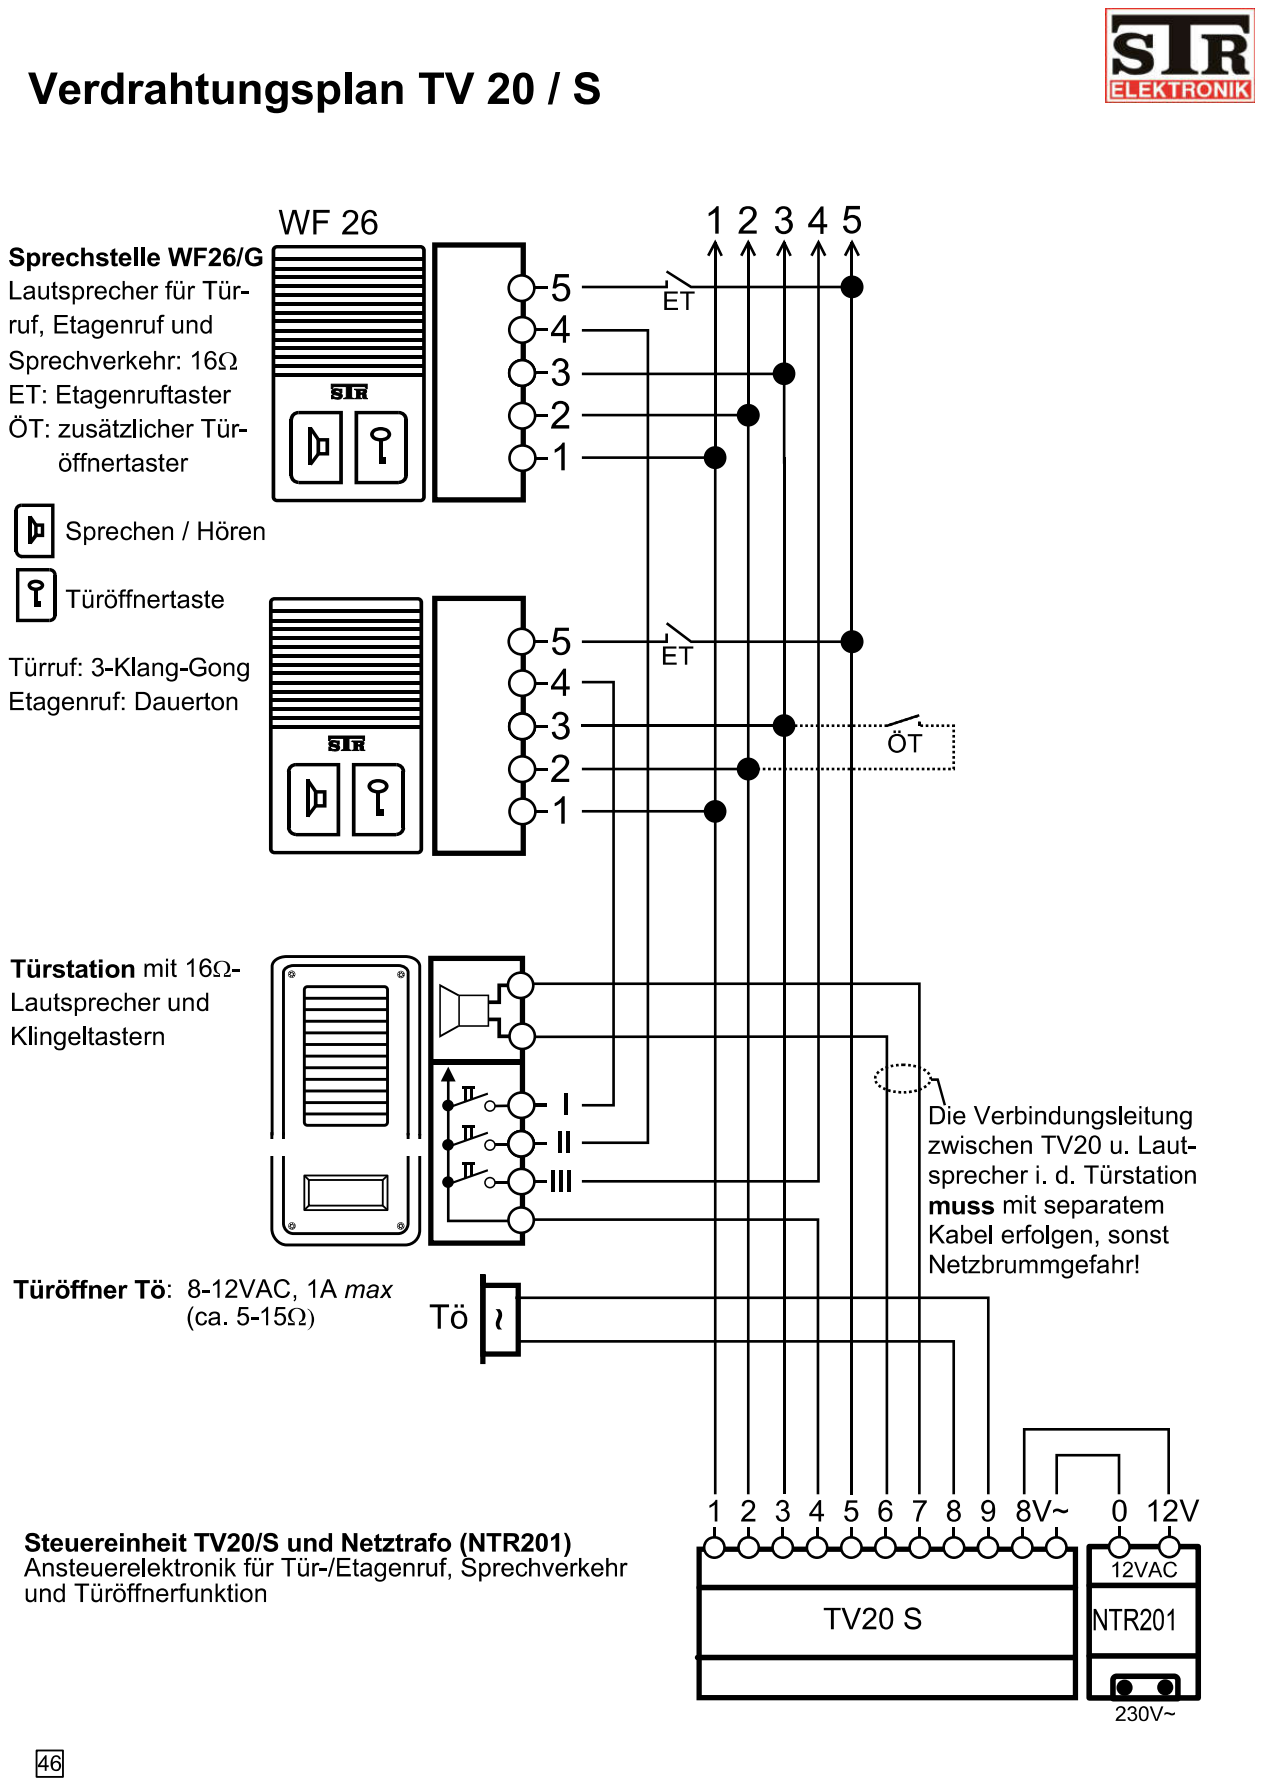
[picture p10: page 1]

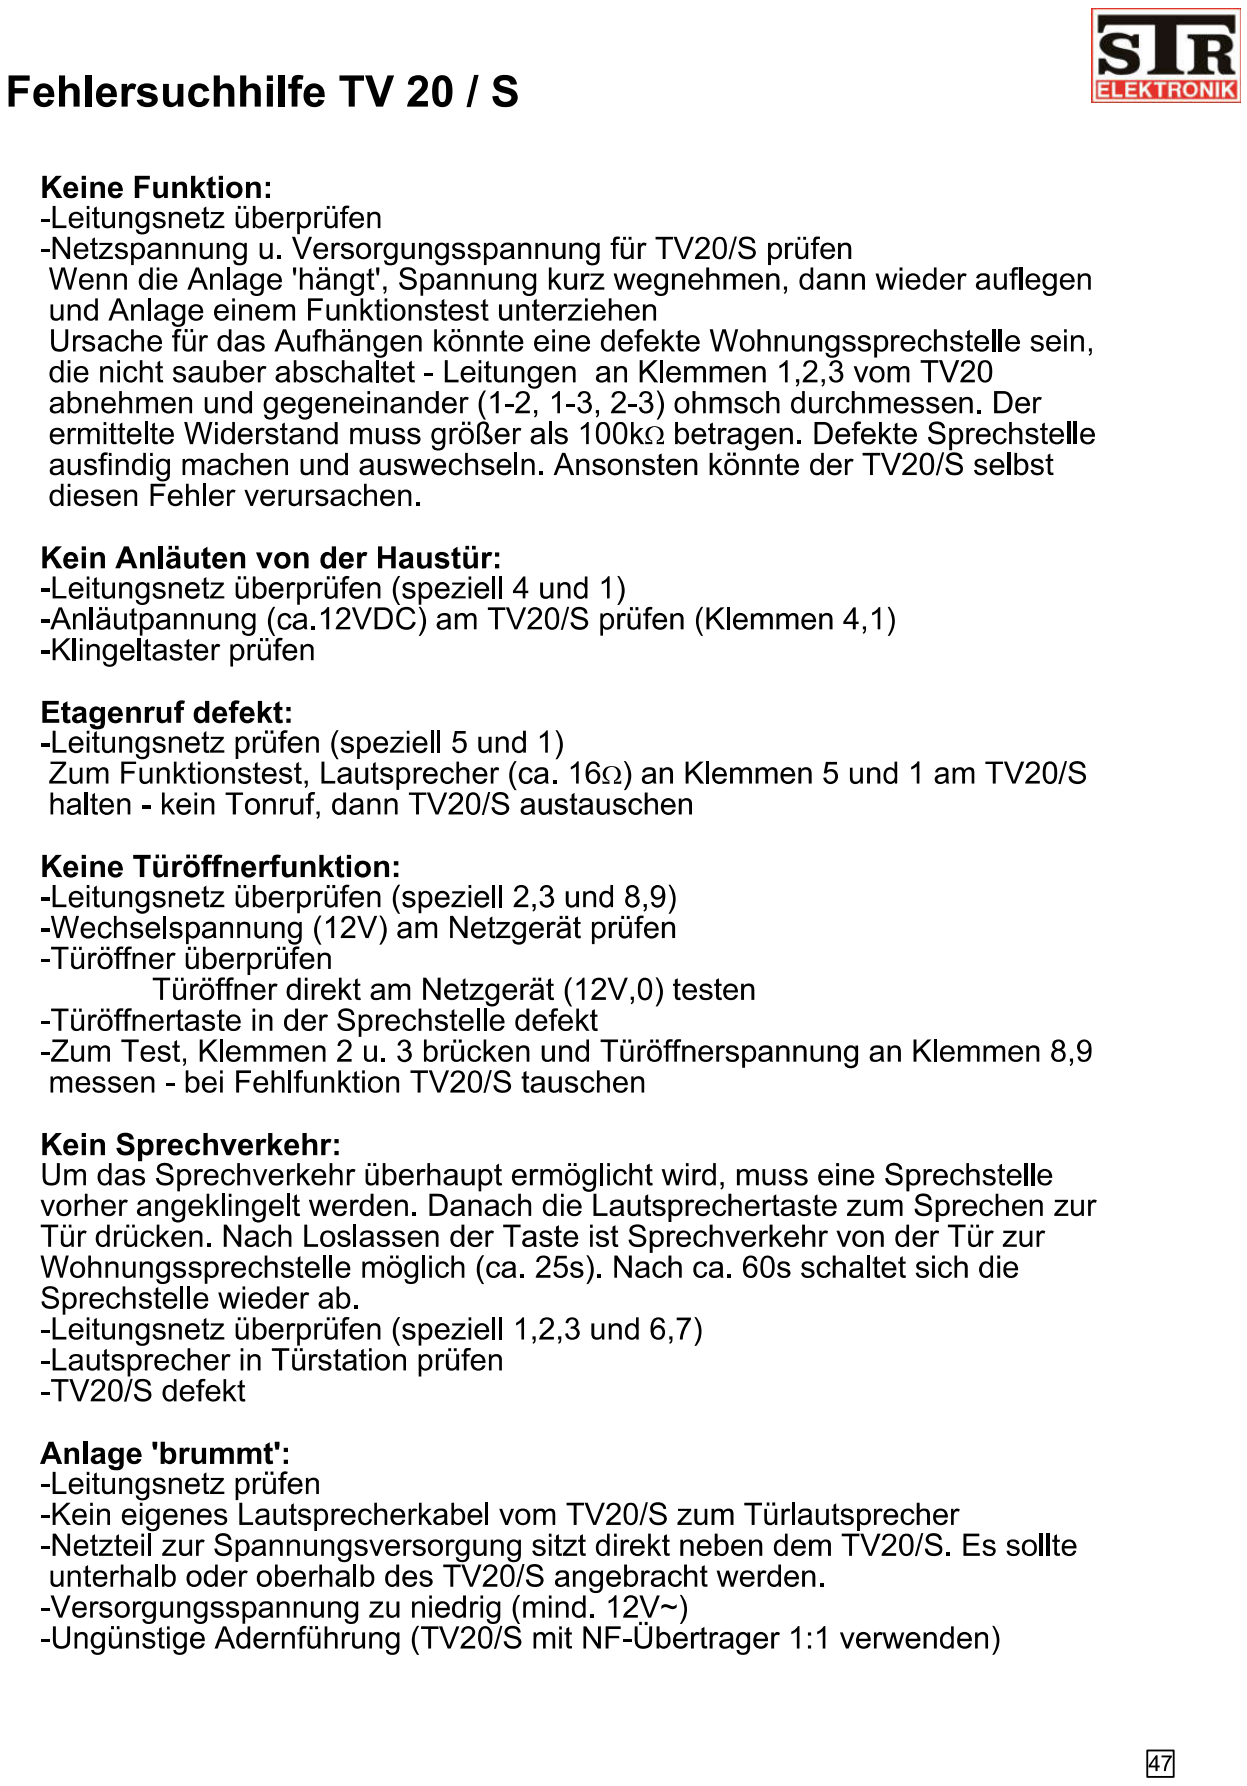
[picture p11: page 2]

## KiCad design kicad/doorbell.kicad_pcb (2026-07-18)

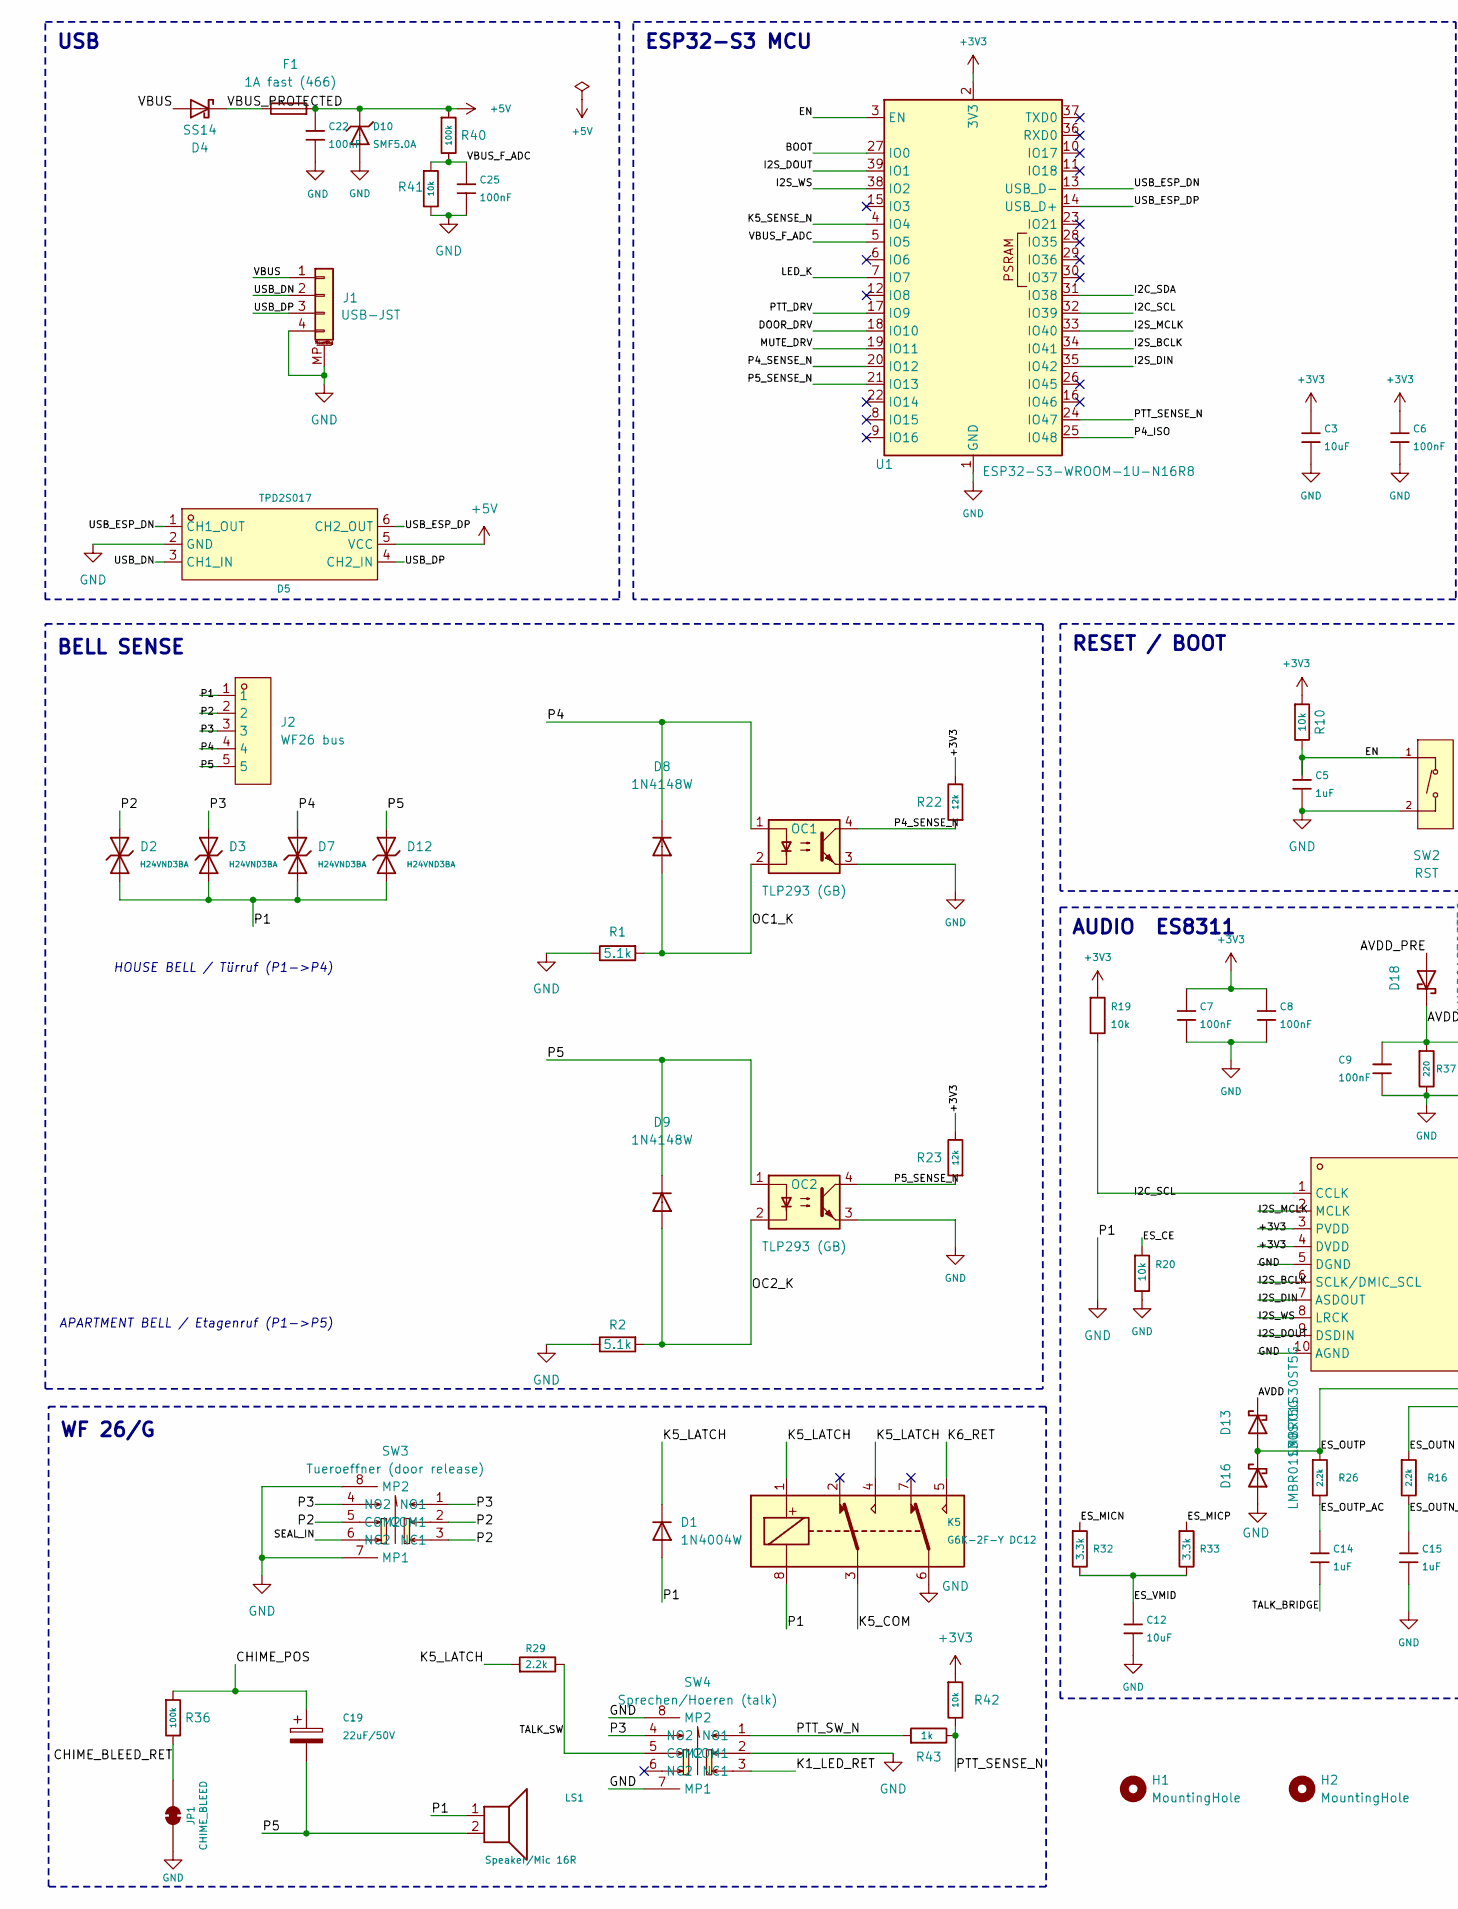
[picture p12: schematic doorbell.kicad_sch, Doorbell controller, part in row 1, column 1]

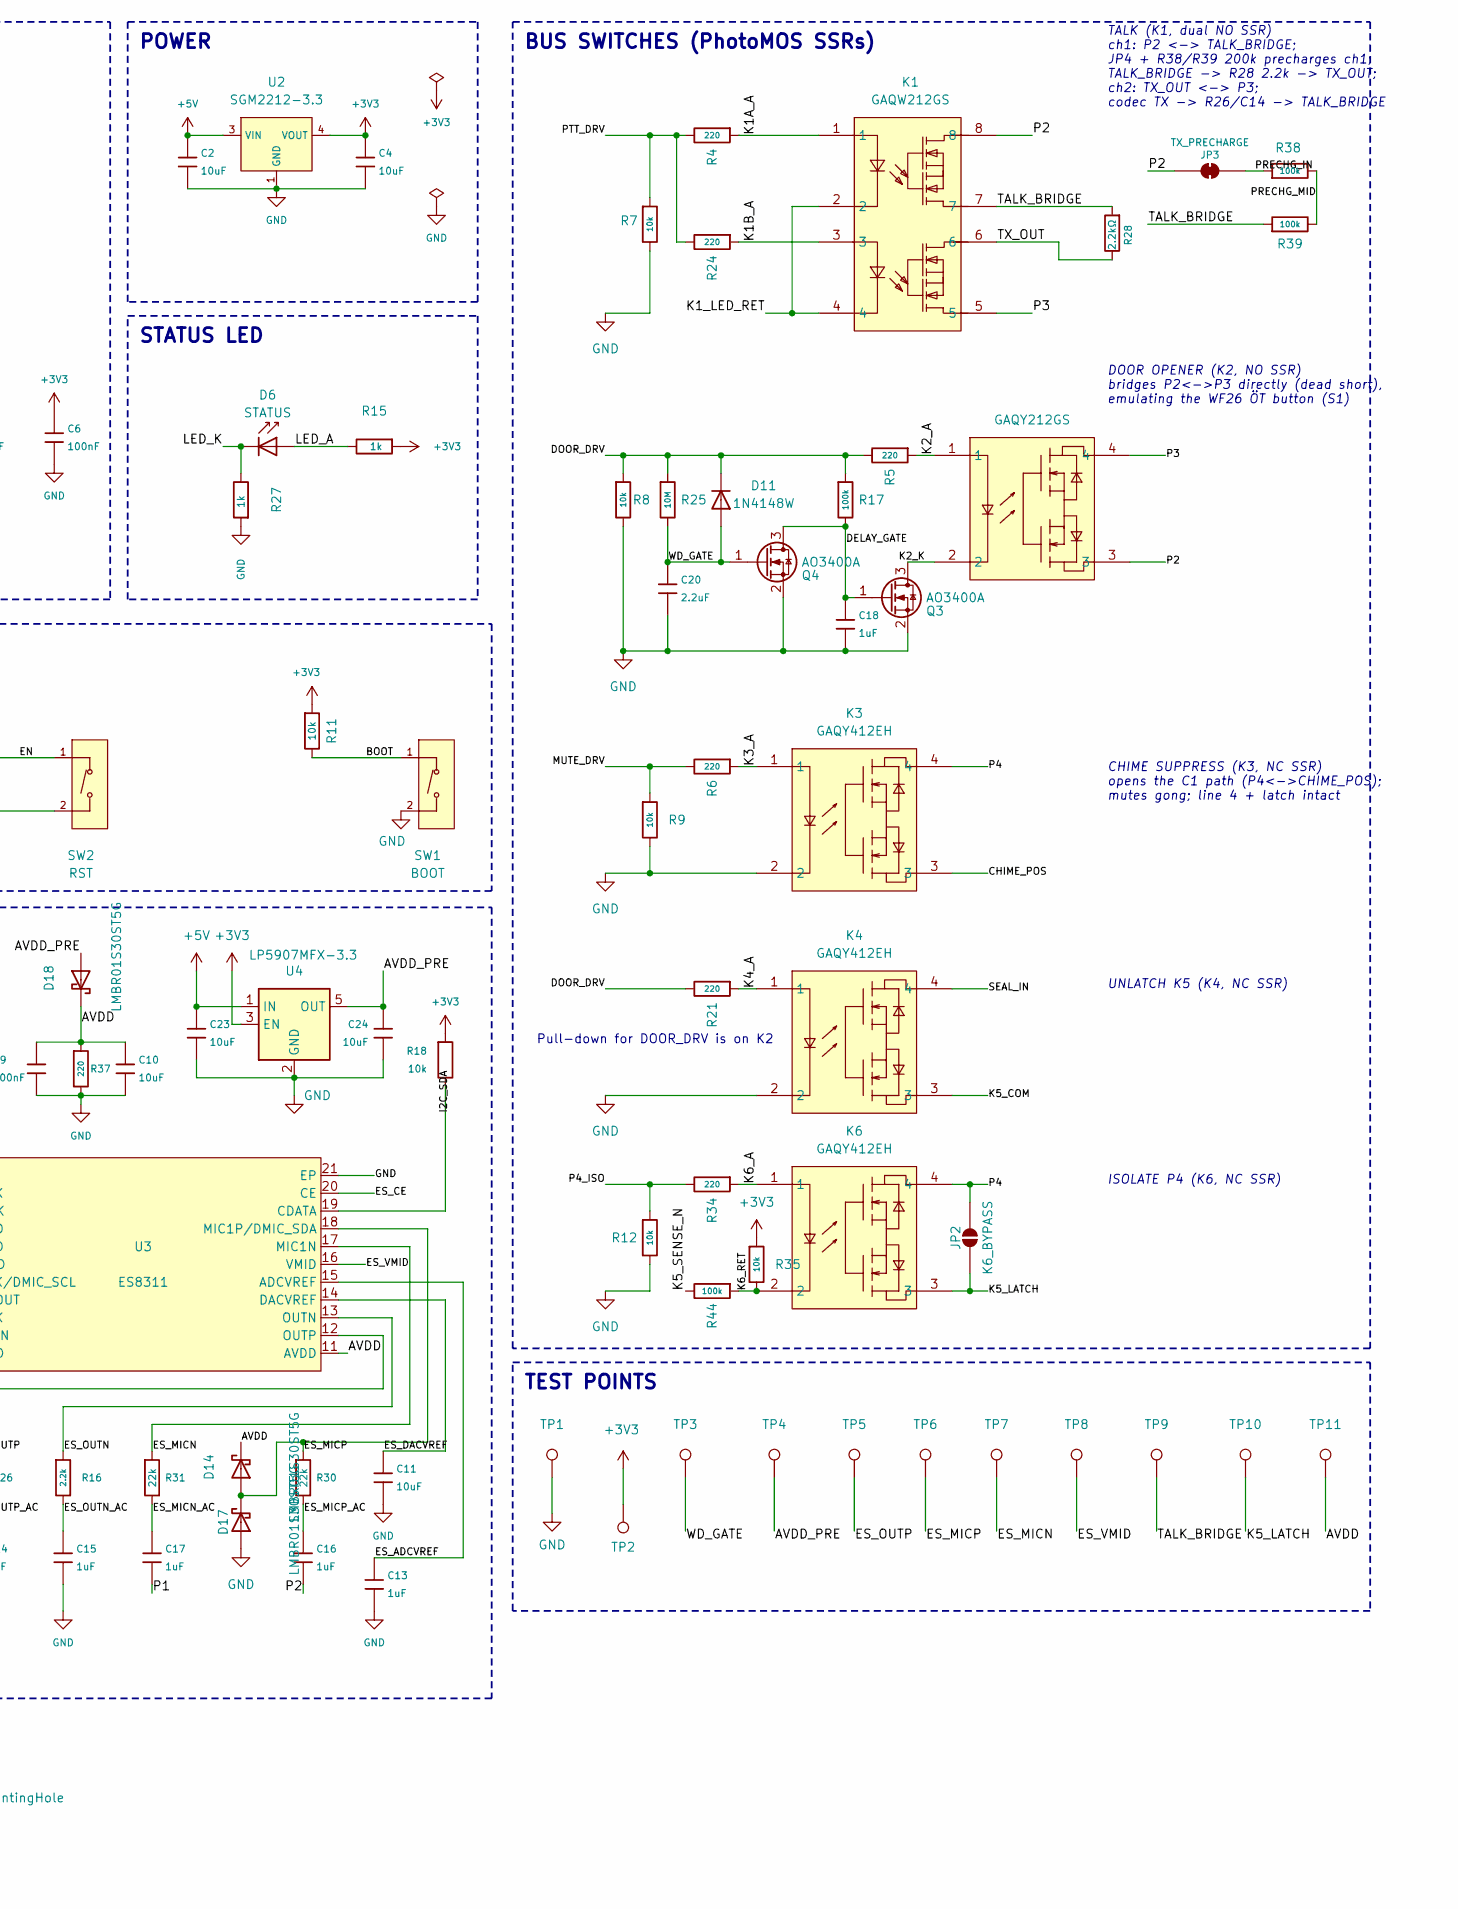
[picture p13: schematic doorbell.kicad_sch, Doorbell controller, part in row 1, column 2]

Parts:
C2, C3, C4, C10, C11, C12, C23, C24: 10uF; C_0603; MPN CL10A106KP8NNNC; LCSC C19702
C5, C13, C14, C15, C16, C17, C18: 1uF; C_0603; MPN CL10A105KB8NNNC; LCSC C15849
C6, C7, C8, C9, C22, C25: 100nF; C_0603; MPN CC0603KRX7R9BB104; LCSC C14663
C19: 22uF/50V; CAP-SMD_BD6.3-L6.6-W6.6-FD; MPN EEEFK1H220P; LCSC C128458
C20: 2.2uF; C_0603; MPN CL10A225KO8NNNC; LCSC C23630
D1: 1N4004W; SOD-123FL_L2.7-W1.8-LS3.8-RD; MPN 1N4004W; LCSC C18199087
D2, D3, D7, D12: H24VND3BA; D_SOD-323; Part H24VND3BA; LCSC C20615815
D4: SS14; D_SMA; MPN SS14; LCSC C2480
D5: TPD2S017; SOT-23-6_L2.9-W1.6-P0.95-LS2.8-BL; MPN TPD2S017DBVR; LCSC C880115
D6: STATUS; D_0603; MPN KT-0603R; LCSC C2286
D8, D9, D11: 1N4148W; D_SOD-123; MPN 1N4148W; LCSC C81598
D10: SMF5.0A; D_SOD-123FL; MPN SMF5.0A; LCSC C19077497
D13, D14, D16, D17, D18: LMBR01S30ST5G; X3-DFN0603-2_L0.6-W0.3-RD; MPN LMBR01S30ST5G; LCSC C383224
F1: 1A fast (466); Fuse_1206_3216Metric; LCSC C151135
H1, H2: MountingHole; MountingHole_3.2mm_M3
J1: USB-JST; JST_SH_SM04B-SRSS-TB_1x04-1MP_P1.00mm_Horizontal; MPN SM04B-SRSS-TB(LF)(SN); LCSC C160404
J2: WF26 bus; CONN-TH_5P-P3.50_DORABO_DB125-3.5-5P-GN-S; MPN DB125-3.5-5P-GN-S; LCSC C3646874
JP1: CHIME_BLEED; SolderJumper-2_P1.3mm_Bridged_RoundedPad1.0x1.5mm
JP2: K6_BYPASS; SolderJumper-2_P1.3mm_Open_RoundedPad1.0x1.5mm
JP3: TX_PRECHARGE; SolderJumper-2_P1.3mm_Bridged_RoundedPad1.0x1.5mm
K1: GAQW212GS; SOP-8_L9.8-W4.4-P2.54-LS6.8-BL; MPN GAQW212GS; LCSC C7435123
K2: GAQY212GS; SOP-4_L4.3-W4.4-P2.54-LS6.8-TR; MPN GAQY212GS; LCSC C7435107
K3, K4, K6: GAQY412EH; SMD-4_L4.8-W6.4-P2.54-LS9.6-BL; MPN GAQY412EH; LCSC C7435135
K5: G6K-2F-Y DC12; Relay_DPDT_Omron_G6K-2F-Y; MPN G6K-2F-Y DC12; LCSC C397194
LS1: Speaker/Mic 16R; SolderWire-0.5sqmm_1x02_P4.6mm_D0.9mm_OD2.1mm
OC1, OC2: TLP293 (GB); SOP-4_L4.4-W2.8-P1.27-LS7.0-BR; MPN TLP293(GB-TPL,E; LCSC C77656
Q3, Q4: AO3400A; SOT-23; MPN AO3400A; LCSC C20917
R1, R2: 5.1k; R_0603; MPN 0603WAF5101T5E; LCSC C23186
R4, R5, R6, R21, R24, R34: 220; R_0603; LCSC C22962
R7, R8, R9: 10k; R_0402; Overload Voltage (Max) 75V; Tolerance ±1%; Part 0603WAF1002T5E; LCSC C25744
R10, R11, R18, R19, R20: 10k; R_0402; MPN 0603WAF1002T5E; LCSC C25744
R12, R35, R41, R42: 10k; R_0402; Overload Voltage (Max) 50V; Tolerance ±1%; Part 0402WGF1002TCE; LCSC C25744
R15, R27, R43: 1k; R_0603; MPN 0603WAF1001T5E; LCSC C21190
R16, R26: 2.2k; R_0603; Overload Voltage (Max) 75V; Tolerance ±1%; Part 0603WAF2201T5E; LCSC C4190
R17, R36, R38, R39, R40, R44: 100k; R_0603; LCSC C25803
R22, R23: 12k; R_0402; MPN 0402WGF1202TCE; LCSC C25752
R25: 10M; R_0603; LCSC C7250
R28: 2.2kΩ; R_0603; MPN 0603WAF2201T5E; LCSC C4190
R29: 2.2k; R_0603; MPN 0603WAF2201T5E; LCSC C4190
R30, R31: 22k; R_0603; MPN 0603WAF2202T5E; LCSC C31850
R32, R33: 3.3k; R_0603; MPN 0603WAF3301T5E; LCSC C22978
R37: 220; R_0603_1608Metric; MPN 0603WAF2200T5E; LCSC C22962
SW1: BOOT; SW_TS-1088-AR02016; MPN TS-1088-AR02016; LCSC C720477
SW2: RST; SW_TS-1088-AR02016; MPN TS-1088-AR02016; LCSC C720477
SW3: Tueroeffner (door release); SW-TH_SPPJ322300; MPN SPPJ322300; LCSC C398940
SW4: Sprechen/Hoeren (talk); SW-TH_SPPJ322300; MPN SPPJ322300; LCSC C398940
TP1: GND; TestPoint_Pad_D1.5mm
TP2: +3V3; TestPoint_Pad_D1.5mm
TP3: WD_GATE; TestPoint_Pad_D1.5mm
TP4: AVDD_PRE; TestPoint_Pad_D1.5mm
TP5: ES_OUTP; TestPoint_Pad_D1.5mm
TP6: ES_MICP; TestPoint_Pad_D1.5mm
TP7: ES_MICN; TestPoint_Pad_D1.5mm
TP8: ES_VMID; TestPoint_Pad_D1.5mm
TP9: TALK_BRIDGE; TestPoint_Pad_D1.5mm
TP10: K5_LATCH; TestPoint_Pad_D1.5mm
TP11: AVDD; TestPoint_Pad_D1.5mm
U1: ESP32-S3-WROOM-1U-N16R8; ESP32-S3-WROOM-1U; MPN ESP32-S3-WROOM-1U-N16R8; LCSC C3013946
U2: SGM2212-3.3; SOT-223-3_L6.5-W3.4-P2.30-LS7.0-BR; LCSC C3294699
U3: ES8311; WQFN-20_L3.0-W3.0-P0.40-BL-EP1.7; MPN ES8311; LCSC C962342
U4: LP5907MFX-3.3; SOT-23-5; MPN LP5907MFX-3.3/NOPB; LCSC C80670

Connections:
+3V3: C3.1, C4.1, C6.1, C7.1, C8.1, R10.1, R11.1, R15.1, R18.1, R19.1, R22.2, R23.2, R35.1, R42.1, TP2.1 (1_1), U1.2 (3V3), U2.2 (VOUT), U2.4 (VOUT), U3.3 (PVDD), U3.4 (DVDD), U4.3 (EN)
+5V: C2.1, C22.1, C23.1, D5.5 (VCC), D10.1, F1.2, R40.1, U2.3 (VIN), U4.1 (IN)
/AVDD: C9.1, C10.1, D13.1, D14.1, D18.1, R37.1, TP11.1 (1_1), U3.11 (AVDD)
/AVDD_PRE: C24.1, D18.2, TP4.1 (1_1), U4.5 (OUT)
/BOOT: R11.2, SW1.1 (A), U1.27 (IO0)
/CHIME_BLEED_RET: JP1.2 (B), R36.2
/CHIME_POS: C19.1, K3.3, R36.1
/DELAY_GATE: C18.1, Q3.1 (G), Q4.3 (D), R17.2
/DOOR_DRV: D11.1, R5.2, R8.1, R17.1, R21.2, R25.1, U1.18 (IO10)
/EN: C5.1, R10.2, SW2.1 (A), U1.3 (EN)
/ES_ADCVREF: C13.1, U3.15 (ADCVREF)
/ES_CE: R20.1, U3.20 (CE)
/ES_DACVREF: C11.1, U3.14 (DACVREF)
/ES_MICN: R31.1, R32.1, TP7.1 (1_1), U3.17 (MIC1N)
/ES_MICN_AC: C17.1, R31.2
/ES_MICP: D14.2, D17.1, R30.1, R33.1, TP6.1 (1_1), U3.18 (MIC1P/DMIC_SDA)
/ES_MICP_AC: C16.1, R30.2
/ES_OUTN: R16.1, U3.13 (OUTN)
/ES_OUTN_AC: C15.1, R16.2
/ES_OUTP: D13.2, D16.1, R26.1, TP5.1 (1_1), U3.12 (OUTP)
/ES_OUTP_AC: C14.1, R26.2
/ES_VMID: C12.1, R32.2, R33.2, TP8.1 (1_1), U3.16 (VMID)
/I2C_SCL: R19.2, U1.32 (IO39), U3.1 (CCLK)
/I2C_SDA: R18.2, U1.31 (IO38), U3.19 (CDATA)
/I2S_BCLK: U1.34 (IO41), U3.6 (SCLK/DMIC_SCL)
/I2S_DIN: U1.35 (IO42), U3.7 (ASDOUT)
/I2S_DOUT: U1.39 (IO1), U3.9 (DSDIN)
/I2S_MCLK: U1.33 (IO40), U3.2 (MCLK)
/I2S_WS: U1.38 (IO2), U3.8 (LRCK)
/K1A_A: K1.1, R4.1
/K1B_A: K1.3, R24.1
/K1_LED_RET: K1.2, K1.4, SW4.3 (NC1)
/K2_A: K2.1, R5.1
/K2_K: K2.2, Q3.3 (D)
/K3_A: K3.1, R6.1
/K4_A: K4.1, R21.1
/K5_COM: K4.3, K5.3
/K5_LATCH: D1.1 (K), JP2.1 (A), K5.1, K5.4, K6.3, R29.1, TP10.1 (1_1)
/K5_SENSE_N: R44.2, U1.4 (IO4)
/K6_A: K6.1, R34.1
/K6_RET: K5.5, K6.2, R35.2, R44.1
/LED_A: D6.2, R15.2
/LED_K: D6.1, R27.2, U1.7 (IO7)
/MUTE_DRV: R6.2, R9.1, U1.19 (IO11)
/OC1_K: D8.2, OC1.2, R1.1
/OC2_K: D9.2, OC2.2, R2.1
/P2: C16.2, D2.2, J2.2, JP3.1 (A), K1.8, K2.3, SW3.2 (COM1), SW3.3 (NC1), SW3.5 (COM2)
/P3: D3.2, J2.3, K1.5, K2.4, SW3.1 (NO1), SW3.4 (NO2), SW4.4 (NO2)
/P4: D7.2, D8.1, J2.4, JP2.2 (B), K3.4, K6.4, OC1.1
/P4_ISO: R12.1, R34.2, U1.25 (IO48)
/P4_SENSE_N: OC1.4, R22.1, U1.20 (IO12)
/P5: C19.2, D9.1, D12.2, J2.5, LS1.2, OC2.1
/P5_SENSE_N: OC2.4, R23.1, U1.21 (IO13)
/PRECHG_IN: JP3.2 (B), R38.1
/PRECHG_MID: R38.2, R39.2
/PTT_DRV: R4.2, R7.1, R24.2, U1.17 (IO9)
/PTT_SENSE_N: R42.2, R43.2, U1.24 (IO47)
/PTT_SW_N: R43.1, SW4.1 (NO1)
/SEAL_IN: K4.4, SW3.6 (NC2)
/TALK_BRIDGE: C14.2, K1.7, R28.2, R39.1, TP9.1 (1_1)
/TALK_SW: R29.2, SW4.5 (COM2)
/TX_OUT: K1.6, R28.1
/USB_DN: D5.3 (CH1_IN), J1.2
/USB_DP: D5.4 (CH2_IN), J1.3
/USB_ESP_DN: D5.1 (CH1_OUT), U1.13 (USB_D-)
/USB_ESP_DP: D5.6 (CH2_OUT), U1.14 (USB_D+)
/VBUS: D4.2, J1.1
/VBUS_F_ADC: C25.1, R40.2, R41.1, U1.5 (IO5)
/VBUS_PROTECTED: D4.1, F1.1
/WD_GATE: C20.1, D11.2, Q4.1 (G), R25.2, TP3.1 (1_1)
GND: C2.2, C3.2, C4.2, C5.2, C6.2, C7.2, C8.2, C9.2, C10.2, C11.2, C12.2, C13.2, C15.2, C17.2, C18.2, C20.2, C22.2, C23.2, C24.2, C25.2, D1.2 (A), D2.1, D3.1, D5.2 (GND), D7.1, D10.2, D12.1, D16.2, D17.2, J1.4, J1.MP (MountPin), J2.1, JP1.1 (A), K3.2, K4.2, K5.6, K5.8, LS1.1, OC1.3, OC2.3, Q3.2 (S), Q4.2 (S), R1.2, R2.2, R7.2, R8.2, R9.2, R12.2, R20.2, R27.1, R37.2, R41.2, SW1.2 (B), SW2.2 (B), SW3.7 (MP1), SW3.8 (MP2), SW4.2 (COM1), SW4.7 (MP1), SW4.8 (MP2), TP1.1 (1_1), U1.1 (GND), U1.40 (GND), U1.41 (GND), U2.1 (GND), U3.5 (DGND), U3.10 (AGND), U3.21 (EP), U4.2 (GND)

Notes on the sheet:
AUDIO ES8311
STATUS LED
Pull-down for DOOR_DRV is on K2
ISOLATE P4 (K6, NC SSR)
USB
UNLATCH K5 (K4, NC SSR)
RESET / BOOT
BUS SWITCHES (PhotoMOS SSRs)
BELL SENSE
WF 26/G
TALK (K1, dual NO SSR) ch1: P2 <-> TALK_BRIDGE; JP4 + R38/R39 200k precharges ch1; TALK_BRIDGE -> R28 2.2k -> TX_OUT; ch2: TX_OUT <-> P3; codec TX -> R26/C14 -> TALK_BRIDGE
CHIME SUPPRESS (K3, NC SSR) opens the C1 path (P4<->CHIME_POS); mutes gong; line 4 + latch intact
TEST POINTS
HOUSE BELL / Türruf (P1->P4)
DOOR OPENER (K2, NO SSR) bridges P2<->P3 directly (dead short), emulating the WF26 ÖT button (S1)
APARTMENT BELL / Etagenruf (P1->P5)
POWER
ESP32-S3 MCU

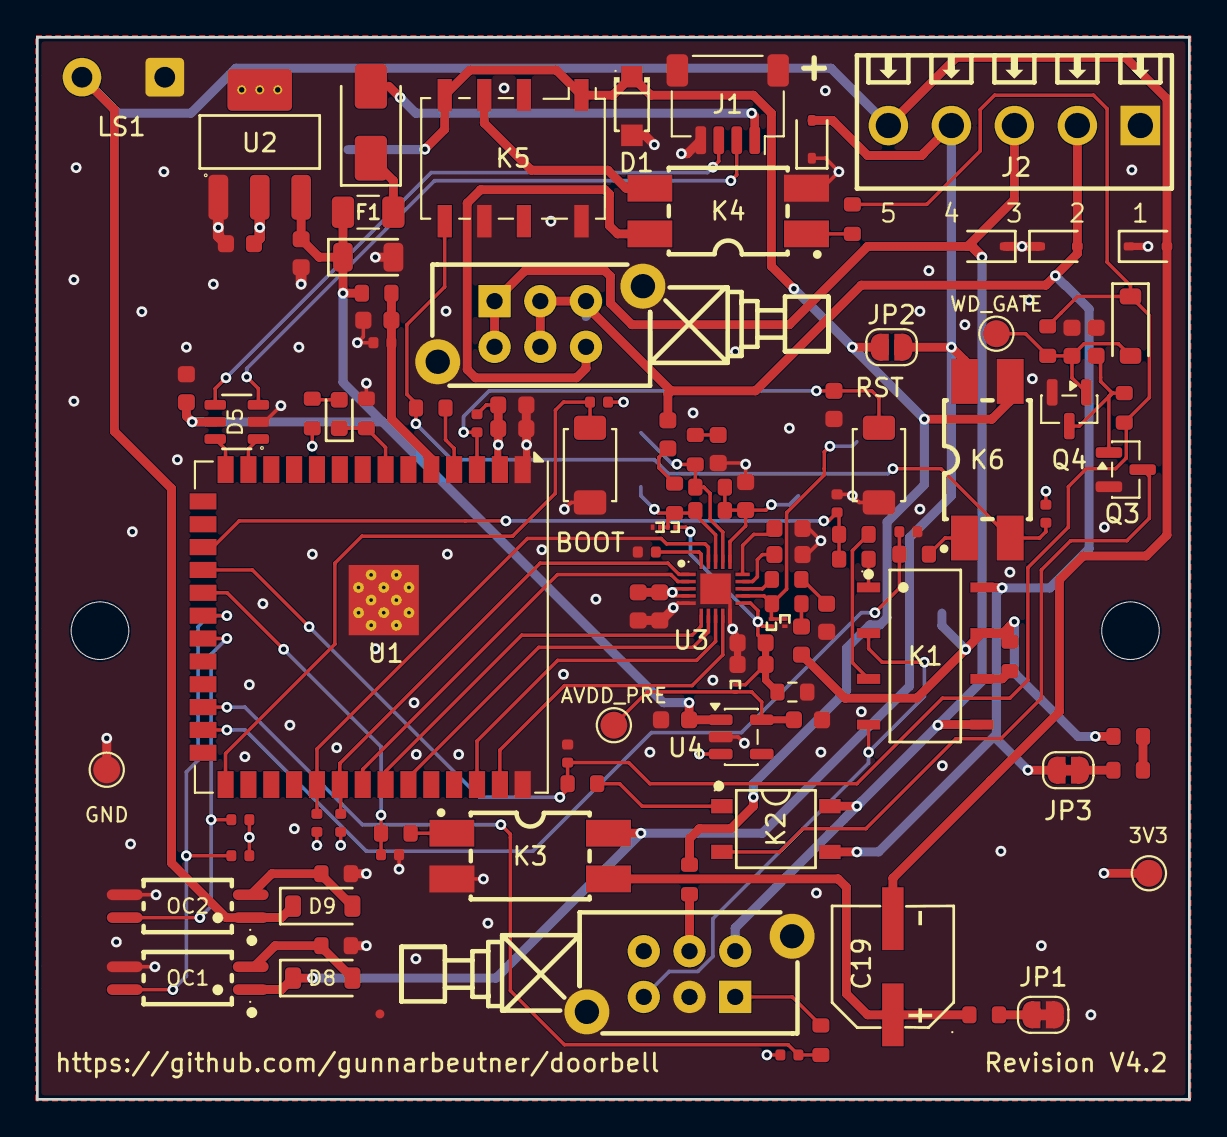
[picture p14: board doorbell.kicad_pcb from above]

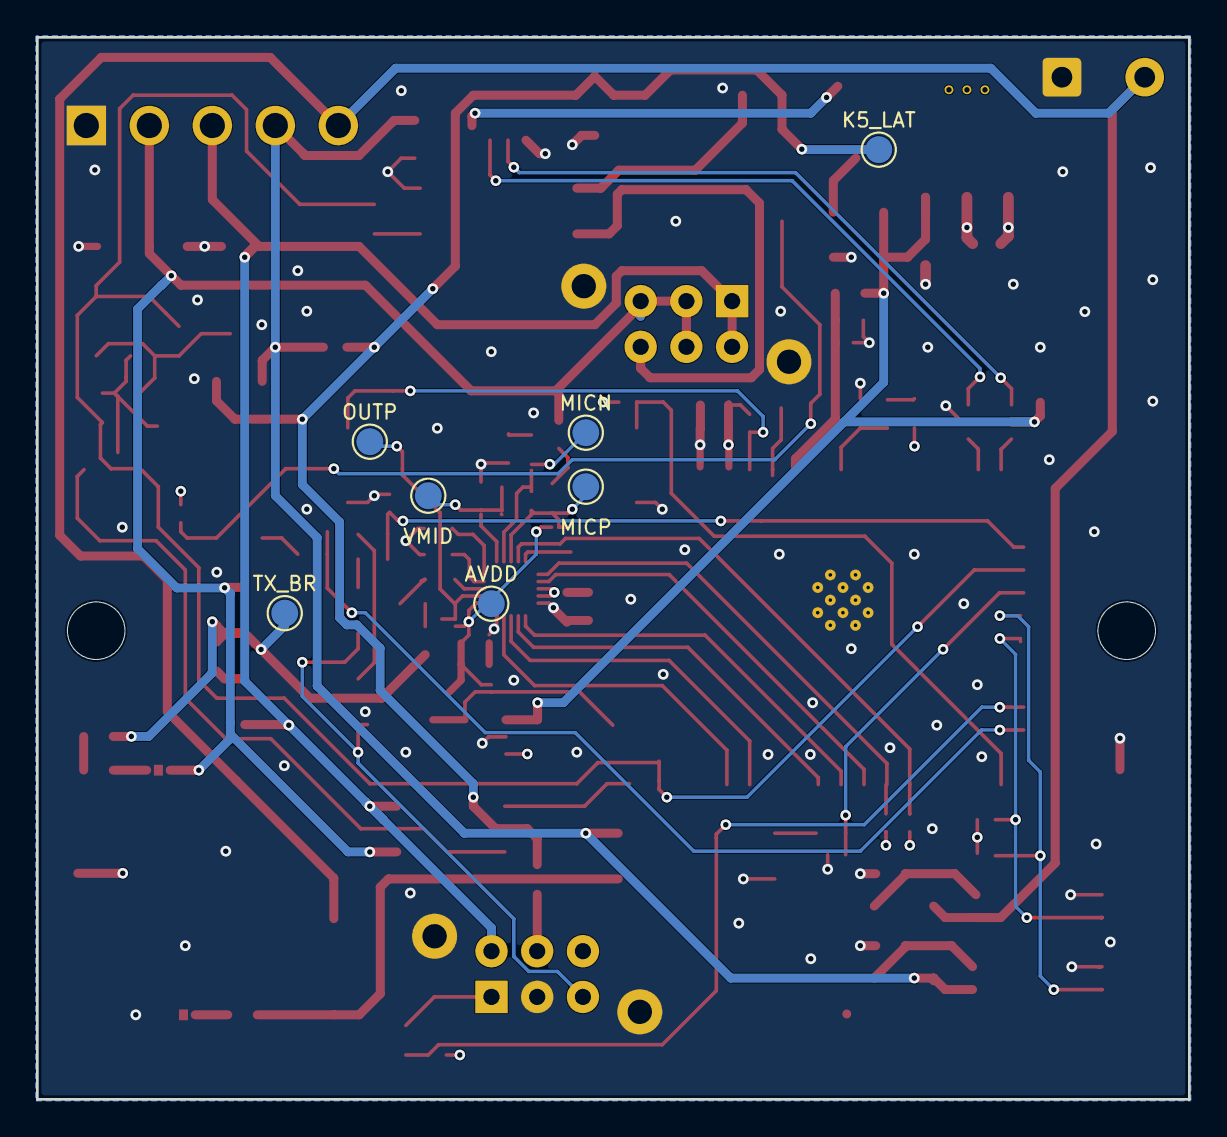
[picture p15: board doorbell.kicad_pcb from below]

Board: 4 copper layers, 64.0 x 59.0 mm, 119 parts (7 on the bottom side), 71 nets.

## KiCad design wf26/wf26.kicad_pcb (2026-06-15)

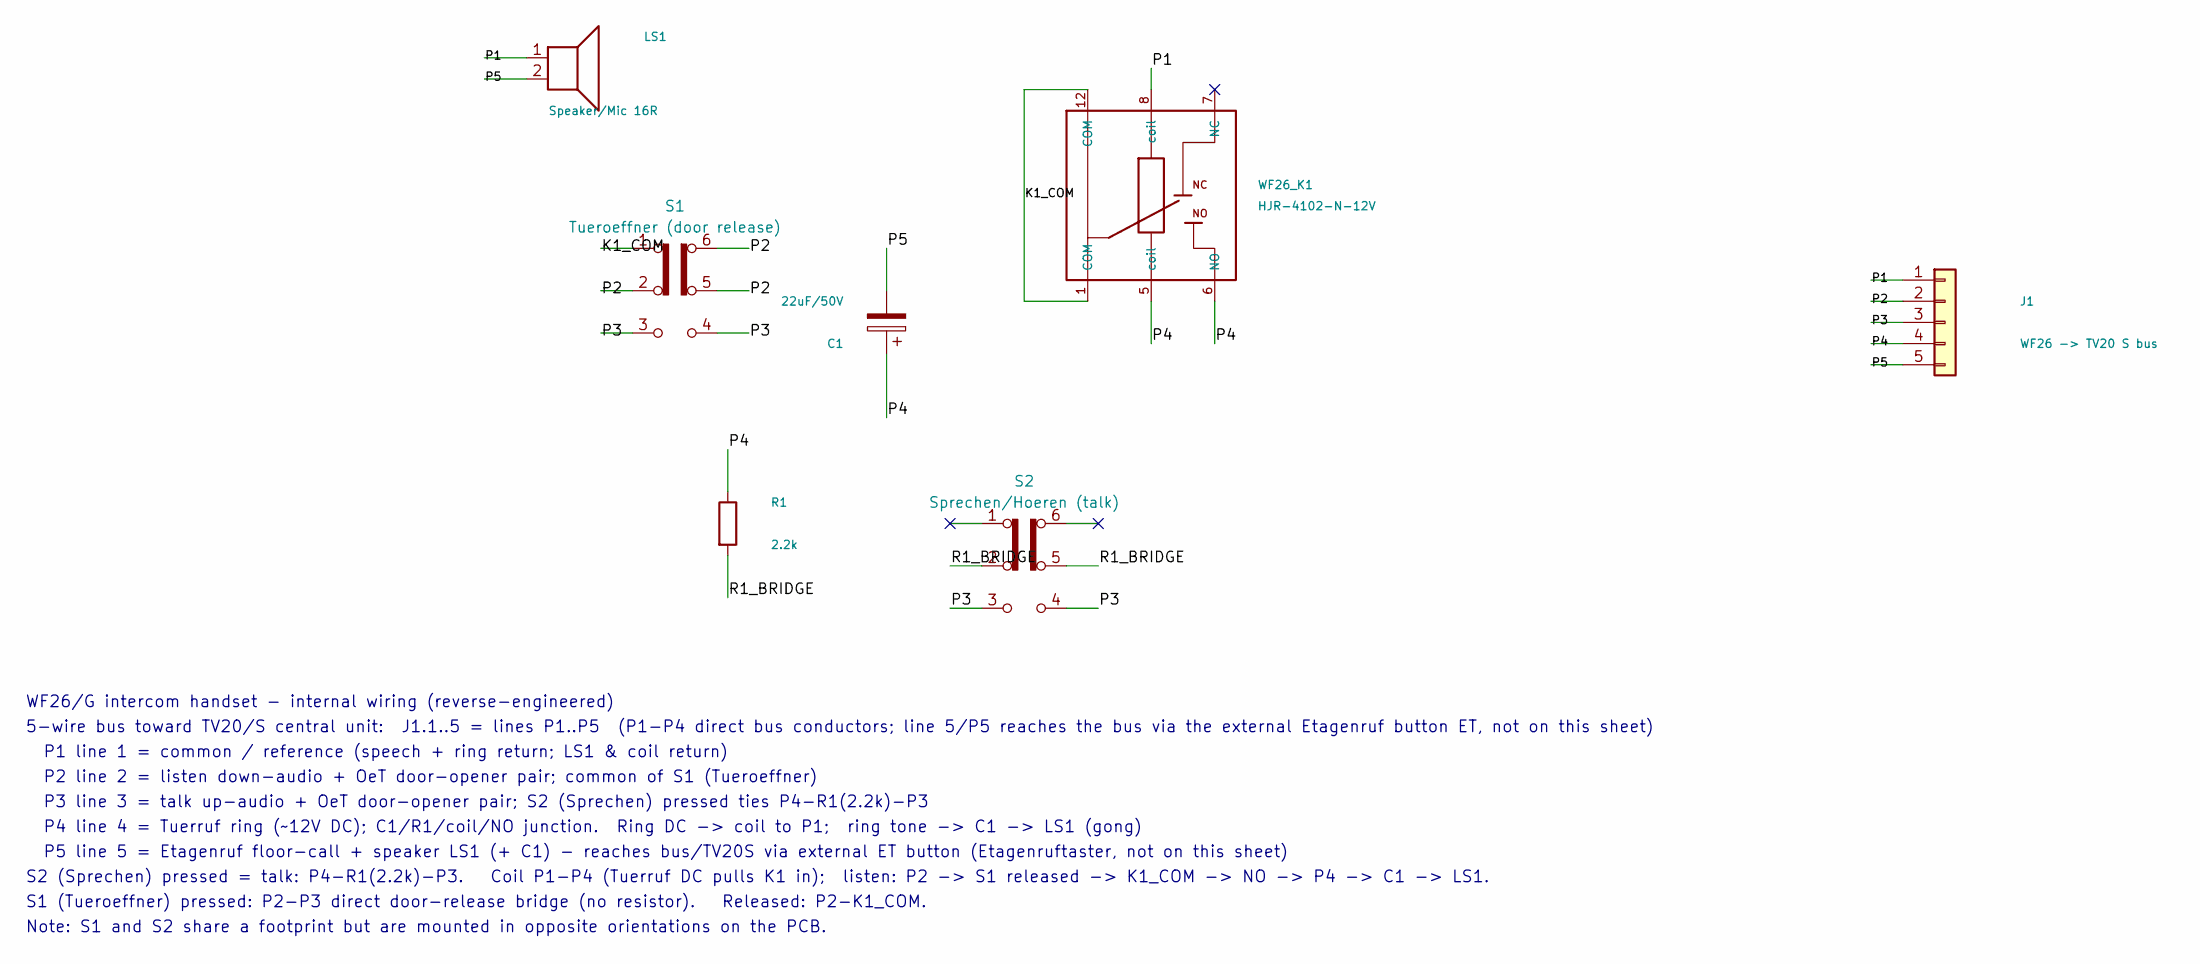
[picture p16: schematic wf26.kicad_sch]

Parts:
C1: 22uF/50V; CP_Radial_D5.0mm_P2.00mm
J1: WF26 -> TV20 S bus; TerminalBlock_Phoenix_PT-1,5-5-3.5-H_1x05_P3.50mm_Horizontal
LS1: Speaker/Mic 16R; PinHeader_1x02_P2.54mm_Vertical
R1: 2.2k; R_Axial_DIN0207_L6.3mm_D2.5mm_P7.62mm_Horizontal
S1: Tueroeffner (door release); SW_CK_JS202011CQN_DPDT_Straight
S2: Sprechen/Hoeren (talk); SW_CK_JS202011CQN_DPDT_Straight
WF26_K1: HJR-4102-N-12V; Relay_SPDT_HJR-4102

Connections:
/K1_COM: S1.1 (A), WF26_K1.1 (COM), WF26_K1.12 (COM)
/P1: J1.1, LS1.1, WF26_K1.8 (coil)
/P2: J1.2, S1.2 (B), S1.5 (B), S1.6 (C)
/P3: J1.3, S1.3 (C), S1.4 (A), S2.3 (C), S2.4 (A)
/P4: C1.1, J1.4, R1.1, WF26_K1.5 (coil), WF26_K1.6 (NO)
/P5: C1.2, J1.5, LS1.2
/R1_BRIDGE: R1.2, S2.2 (B), S2.5 (B)

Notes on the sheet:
S2 (Sprechen) pressed = talk: P4-R1(2.2k)-P3. Coil P1-P4 (Tuerruf DC pulls K1 in); listen: P2 -> S1 released -> K1_COM -> NO -> P4 -> C1 -> LS1.
P4 line 4 = Tuerruf ring (~12V DC); C1/R1/coil/NO junction. Ring DC -> coil to P1; ring tone -> C1 -> LS1 (gong)
5-wire bus toward TV20/S central unit: J1.1..5 = lines P1..P5 (P1-P4 direct bus conductors; line 5/P5 reaches the bus via the external Etagenruf button ET, not on this sheet)
P1 line 1 = common / reference (speech + ring return; LS1 & coil return)
P5 line 5 = Etagenruf floor-call + speaker LS1 (+ C1) - reaches bus/TV20S via external ET button (Etagenruftaster, not on this sheet)
Note: S1 and S2 share a footprint but are mounted in opposite orientations on the PCB.
S1 (Tueroeffner) pressed: P2-P3 direct door-release bridge (no resistor). Released: P2-K1_COM.
P2 line 2 = listen down-audio + OeT door-opener pair; common of S1 (Tueroeffner)
P3 line 3 = talk up-audio + OeT door-opener pair; S2 (Sprechen) pressed ties P4-R1(2.2k)-P3
WF26/G intercom handset - internal wiring (reverse-engineered)

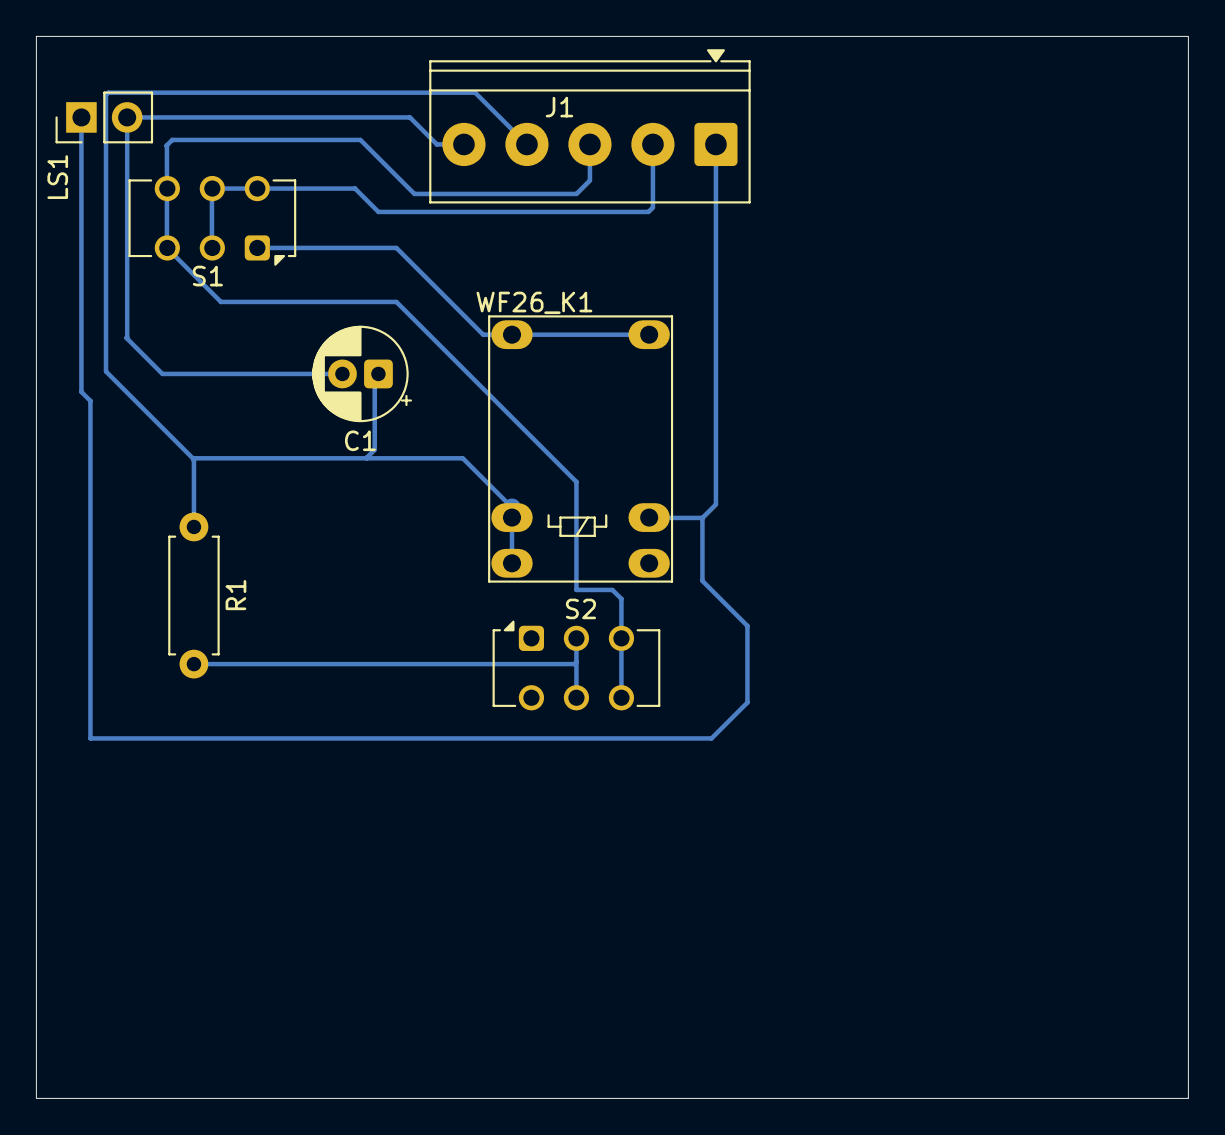
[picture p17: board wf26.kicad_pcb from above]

Board: 2 copper layers, 64.0 x 59.0 mm, 7 parts (0 on the bottom side), 7 nets.

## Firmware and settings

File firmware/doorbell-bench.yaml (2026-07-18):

# BENCH BRING-UP twin of doorbell.yaml (U1 = ESP32-S3-WROOM-1U-N16R8, U3 = ES8311).
# Tracks the production config's behaviour (welcome audio, greeting registry, name-based greet API,
# chime policy) but with bench deltas, all in service of VERIFICATION.md §5.5 (emulated-bus stages):
#   - Identity doorbell2 @ 192.168.3.78 (shares the api key + OTA password); production is doorbell @ .18.
#   - ALL homeassistant.event calls are stripped (a bench ring must not fire the real HA automations),
#     and with them the ring-triggered auto-open reflex — house/apartment sense is detection-only here.
#   - The API client reboot watchdog is disabled so unattended/paused bench runs do not reboot merely
#     because Home Assistant or a test client remains disconnected; Wi-Fi loss still retains its guard.
#   - Three debug switches drive otherwise-hidden hardware: "Debug Chime Suppress" (K3),
#     "Debug Door Drive Hold" (unpulsed K2+K4 — the Q4 watchdog releases K2 after ~8.4 s nominal),
#     and "Debug P4 Isolation" (K6 request). "Debug K5 Sense" reports K5's auxiliary contact.
#   - "Debug Test Tone": a continuous ~1 kHz sine on the DAC/TX path (scope it on P3 with PTT on).
#     "Debug DAC Warmup" feeds digital zeros into the same speaker without asserting K1. At boot it
#     primes the local `i2s_audio` keep-alive channel once, after which welcome playback reuses
#     the configured channel; warmup and the test tone are exclusive.
#     NO microphone here: the mic (I2S RX) and speaker (I2S TX) share one half-duplex I2S bus, and a
#     declared mic holds the bus so the speaker can't start ("Parent bus is busy") — which breaks
#     welcome-audio playback. RX / the mic-loopback meter is dropped; verify audio with the scope.
#     The welcome-audio media_player, warmup and tone share one speaker — use one at a time.
#
# GPIO map (S3-WROOM-1U; USB on the north edge, the ES8311 I2C/I2S bus ascending down the codec edge):
#   House Doorbell     (OC1 / Türruf sense)        : GPIO12
#   Apartment Doorbell (OC2 / Etagenruf sense)     : GPIO13
#   front_door_buzzer  (DOOR_DRV → K2+K4 door pair) : GPIO10
#   suppress_chime_bin (K3 / chime suppress)       : GPIO11
#   K1                 (PTT SSR, talk=energised)   : GPIO9
#   K5_SENSE_N        (K5 aux NO via R44, active-low) : GPIO4
#   P4_ISO            (K6 request, active-high)   : GPIO48
#   post-fuse +5 V monitor (VBUS_F_ADC / ADC1_CH4) : GPIO5
#   status LED          (active-low D6)             : GPIO7
#   I2C_SDA  (ES8311 control)                      : GPIO38
#   I2C_SCL  (ES8311 control)                      : GPIO39
#   I2S_MCLK (master clock)                        : GPIO40
#   I2S_BCLK (bit clock, SCLK)                     : GPIO41
#   I2S_DIN  (capture, ASDOUT)                     : GPIO42
#   I2S_WS   (LRCK)                                : GPIO2
#   I2S_DOUT (DAC / playback, DSDIN)               : GPIO1
#   logger                                         : native USB-Serial-JTAG (GPIO19/GPIO20 = USB D-/D+)
# The ES8311 bus is ordered ascending by module pad — SDA,SCL,MCLK,BCLK,DIN on GPIO38-42, then WS,DOUT
# on GPIO2/GPIO1 — so it fans out down U1's codec edge with no crossings, matching U3's pin sequence.
# The three SSR gates (GPIO9/10/11) and two sense optos (GPIO12/13) run ascending along the bus-side
# edge. BOOT is GPIO0 (boot strap + SW1); EN is the module's dedicated EN pin (SW2). The S3 is dual-core
# with 16 MB flash + 8 MB PSRAM (audio buffers live in PSRAM). Native USB-Serial-JTAG = flashing + logs.
#
# SSR gate outputs are ACTIVE-HIGH (see the output section): GPIO HIGH -> SSR LED on -> contact made.
#
# Sense disambiguation for the V4 sense points:
#   - OC2 taps the speaker pair (P5↔P1) and pulses at audio rate on ANY loud speaker audio
#     (floor tone, door gong, speech). Its filter chain stretches the half-cycle pulses into a
#     level (delayed_off before delayed_on) and is masked by house_doorbell / PTT — see the sensor.
#   - OC1 (line 4 / Türruf) needs no PTT mask: the board's talk handshake bridges P2↔P3 only
#     (K1: P2↔TALK_BRIDGE + TX_OUT↔P3), so energising K1 never reaches line 4. Debounce only.
#
# The two configs use separate build dirs (different device names), so no `esphome clean` is needed
# between them; flash the production doorbell.yaml before the board goes in the wall. Keep this in
# sync with doorbell.yaml — it is a copy of it plus the bench deltas listed above.

# Local ESPHome 2026.7.0 component copies: `speaker` carries the announcement-pipeline state reset
# described in https://github.com/esphome/esphome/issues/15692; `i2s_audio` carries the keep-alive
# experiment from https://github.com/esphome/esphome/pull/15565. See each component's README.md.
packages:
  policy: !include packages/policy.yaml

external_components:
  - source:
      type: local
      path: components
    components:
      - speaker
      - i2s_audio
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

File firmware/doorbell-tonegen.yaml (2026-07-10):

# TONE GENERATOR + HA MEDIA PLAYER for the second V4.1 board (bench instrument,
# not a doorbell). Bench bring-up uses two boards: board #1 (doorbell2 @ .78,
# doorbell-bench.yaml) is the unit under test; this config turns the spare board into an audio
# source for board #1's RX and chime-mute tests (VERIFICATION.md §5.5 2d/2e): "Tone" + "PTT" put a
# ~1 kHz sine onto P2/P3 through this board's own DAC → R26/C14 → TALK_BRIDGE → R28 → K1 path
# (~0.55 Vrms into high-Z), and the "Tone generator DAC" media_player streams arbitrary HA audio
# (TTS, clips) down the same path — with PTT on it lands on whatever the P2 wire feeds (e.g.
# board #1's chime input). Wire P1↔P1 and source-P2 → target pin. Control via HA (native api),
# the web UI, or REST @ 192.168.3.79. Turn "Tone" off before HA playback — they share the DAC.

esphome:
  name: doorbell3
  friendly_name: Doorbell tone generator

esp32:
  board: esp32-s3-devkitc-1     # generic ESP32-S3 board def; U1 = ESP32-S3-WROOM-1U-N16R8
  variant: esp32s3
  flash_size: 16MB              # N16R8 module = 16 MB flash
  framework:
    type: esp-idf

psram:
  mode: octal
  speed: 80MHz

logger:
  hardware_uart: USB_SERIAL_JTAG

api:
  reboot_timeout: 0s        # bench instrument — keep running with no HA connected
  encryption:
    key: !secret api_encryption_key

web_server:
  port: 80
  ota: false
  local: true

ota:
  platform: esphome
  password: !secret ota_password

network:
  enable_ipv6: true

wifi:
  ssid: !secret wifi_ssid
  password: !secret wifi_password
  fast_connect: true
  power_save_mode: "none"
  reboot_timeout: 0s        # antenna may be absent — never reboot-loop over missing WiFi

  manual_ip:
    static_ip: 192.168.3.79
    gateway: 192.168.3.1
    subnet: 255.255.255.0
    dns1: 192.168.3.53

i2c:
  sda: GPIO38              # I2C_SDA — ES8311 (U3) control bus
  scl: GPIO39              # I2C_SCL — ES8311 (U3) control bus
  scan: false

i2s_audio:
  id: i2s_bus
  i2s_lrclk_pin: GPIO2    # I2S_WS / LRCK
  i2s_bclk_pin: GPIO41    # I2S_BCLK / SCLK
  i2s_mclk_pin: GPIO40    # I2S_MCLK

audio_dac:
  - platform: es8311
    id: es8311_codec
    address: 0x18
    use_microphone: false  # DAC-only — this board is a source, its ADC stays idle

speaker:
  - platform: i2s_audio
    id: intercom_speaker
    i2s_audio_id: i2s_bus
    dac_type: external
    audio_dac: es8311_codec
    i2s_dout_pin: GPIO1    # I2S_DOUT / DSDIN (ESP→codec, playback)

# Same continuous phase-continuous sine generator as the bench config.
interval:
  - interval: 50ms
    then:
      - lambda: |-
          if (!id(tone_switch).state) return;
          // never interleave the sine with active HA media playback — shared DAC
          auto mp_state = id(intercom_media).state;
          if (mp_state == media_player::MEDIA_PLAYER_STATE_PLAYING ||
              mp_state == media_player::MEDIA_PLAYER_STATE_ANNOUNCING) return;
          static double phase = 0.0;
          const double fs = 16000.0;
          const double tone_hz = 1000.0;
          const double amp = 0.5;                       // -6 dBFS
          const double TWO_PI = 6.283185307179586;
          const double dphase = TWO_PI * tone_hz / fs;
          int16_t block[512];
          while (true) {
            double ph = phase;
            for (int i = 0; i < 512; i++) {
              double v = amp * 32767.0 * sin(ph);
              block[i] = (int16_t) (v >= 0.0 ? v + 0.5 : v - 0.5);
              ph += dphase;
            }
            size_t wrote = id(intercom_speaker).play((const uint8_t *) block, sizeof(block));
            size_t accepted = wrote / 2;
            phase += dphase * (double) accepted;
            while (phase >= TWO_PI) phase -= TWO_PI;
            if (accepted < 512) break;
          }

# HA-facing media player wrapping the same DAC/speaker (pattern proven on the V4.0 bench board):
# WAV pipeline so HA transcodes and the device never decodes; 16 kHz mono matches the codec's
# confirmed I2S rate. Engage "PTT" to route the audio onto the bus wire.
media_player:
  - platform: speaker
    id: intercom_media
    name: "Tone generator DAC"
    announcement_pipeline:
      speaker: intercom_speaker
      format: WAV
      sample_rate: 16000
      num_channels: 1

switch:
  - platform: template
    name: "Tone"
    icon: mdi:sine-wave
    id: tone_switch
    optimistic: true
    restore_mode: ALWAYS_OFF
    turn_off_action:
      - speaker.stop: intercom_speaker
  - platform: output
    name: "PTT"
    icon: mdi:phone-outgoing
    id: ptt_switch
    output: ptt_relay_bin
    restore_mode: ALWAYS_OFF   # K1 open at boot — tone stays off the bus until commanded

# The SSR gates are ACTIVE-HIGH (220 Ω series R + 10 k pull-down): GPIO HIGH -> contact made.
# Only K1 (PTT) is driven on this board; the door/chime outputs are deliberately not configured.
output:
  - platform: gpio
    pin: GPIO9               # K1 — PTT SSR (energised = tone onto P2/TALK_BRIDGE + TX_OUT/P3)
    id: ptt_relay_bin

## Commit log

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2026-06-06 Add V4 code-generated KiCad pipeline + finalize design doc
    Script-driven board design (one source of truth: kicad/doorbell_design.py):
    - gen_schematic.py (kiutils): ESPHome doorbell schematic, ERC 0 errors
    - gen_pcb.py (pcbnew): placed + netted board, antenna keep-out, flush-edge
    constraints (USB-C/WAGO/antenna), declared via EDGE_FLUSH
    - check_pcb.py: verifiable placement-constraint checklist (PASS/FAIL)
    - route.py: Freerouting autoroute (DSN export -> headless -> SES import)
    - build.sh: sch | pcb | check | route | fab | all-route
    DESIGN.md: completed V4 section (driver/power subcircuits, BOM, isolation,
    audio deferred) and corrected the V3 relay (P2->COM/MAIN1) and bell-sense
    (R1 emitte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
    [doorbell.kicad_pcb, doorbell.kicad_sch]
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2026-06-06 PCB: ground pour + stitching vias, JLCPCB fab zip, opto reposition
    - GND copper pour on both layers (route.py), antenna kept clear via keep-out
    - 66 GND stitching vias tying the two pours together (skips pads/traces/keep-out)
    - build.sh fab now bundles standard gerbers+drill into doorbell-jlcpcb.zip
    - optos moved right of U2 with clearance; U2 rotated 180; LED to top-left; C6 to U1 left
    Built via build.sh all-route (0 overlaps, constraints pass, routed).
    [doorbell.kicad_pcb, doorbell.kicad_sch]
2026-06-06 PCB: regroup analog/power passives, VBUS island, sparser stitching, GND_FILL toggle
    - CC resistors (R9/R10) rotated right of J1; R10 CC2 pad aligned to J1 CC2 (Y=31.25)
    - R1/R2 grouped with optos+relay; optos rotated 180 between U1 and K2 (swapped)
    - EN RC (R7/C5) left of reset button; LDO caps C1/C2/C4 grouped around U2
    - R8 left of boot button
    - +5V VBUS island (gen_pcb, B.Cu) currently commented out; route handles its absence
    - stitching vias: sparser (8mm pitch), skip footprints, 0.6mm clearance
    - route.py GND_FILL flag (currently False) to toggle the GND pour + stitching
    [doorbell.kicad_pcb, doorbell.kicad_sch]
2026-06-06 PCB: deterministic +5V VBUS bridge for J1 USB-C (autoroute couldn't join it)
    J1's single-row Type-C splits VBUS onto two pad-stacks (A4/B9, A9/B4) with no
    thru-hole to join them, so Freerouting stranded one (J1.B4). Pre-place a fixed
    bridge in gen_pcb.py: one off-pad via east of each NPTH peg, VBUS pad -> via on
    F.Cu, the two vias joined on B.Cu (layer 2), 0.2mm. The lower via is tucked by
    the peg so its escape threads the peg/CC2 pinch without blocking CC2 (J1.B5->R10).
    Move J1's silk reference to the connector bottom (rotated CW) to clear the flush
    left edge. Result: route -> 0 unconnected pads, 0 DRC violations. Documented in
    DESIGN.md. (Also sweeps in the regenerated board/schematic/proj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
    [doorbell.kicad_pcb, doorbell.kicad_sch]
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2026-06-06 WF26 interface: 6-way screw terminal + restore line-4 series break
    J2: Conn_01x05 Wago push-in -> Conn_01x06 4Ucon 3.5mm screw terminal.
    The WF26 bus wire is ~26-28 AWG, below Wago push-in/lever min (0.2 mm2);
    screw terminals clamp fine stranded reliably and match the WF26's own.
    Restore chime suppression: IN_P4 now reaches J2 pad 6, so line 4 is
    broken into the board (P4 = bus/TV20S side -> K2 COM; IN_P4 = WF26 side
    -> K2 NC, OC1 sense, jumper back to WF26 terminal 4). V4 had collapsed
    IN_P4 to an internal-only node, silently disabling K2's chime suppress.
    J2 shifted right (x=53) so the wider 6-pos body clears OC1/R_em.
    Layout nudges: spread R9 down / R10 up to open a corridor for the USB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
    [doorbell.kicad_pcb, doorbell.kicad_sch]
2026-06-07 4-layer redesign: USB4085 connector, GND/+3V3 planes, lower-left logic floorplan
    Connector: J1 -> GCT USB4085 (2-row THT, LCSC C7095263). The single-row HRO
    Type-C's interleaved/duplicated D+/D-/CC/VBUS pads couldn't be routed cleanly;
    the USB4085's two TH rows escape easily. Old HRO VBUS bridge removed.
    Stackup: 4 layers (F.Cu / In1=GND / In2=+3V3 / B.Cu), solid planes.
    - In1/In2 marked LT_POWER so the autorouter keeps signals on F.Cu/B.Cu.
    - gen_pcb.py pre-stitches every surface GND/+3V3 pad to its plane (offset via
    + F.Cu stub, ~27 vias, no via-in-pad); THT power pads pass through.
    - route.py fills the planes before the DSN export (filling in gen_pcb segfaults
    pcbnew) so the stitch v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
    [doorbell.kicad_pcb, doorbell.kicad_sch]
2026-06-07 Floorplan: bus interface above U1 (optos left, relays right), J2 centered on top
    - Optos + bell-sense R on the left, relays + drivers right beside them, above U1.
    - WF26 screw terminal (J2) centered on the top edge; J1 (USB-C) no longer
    auto-centers -- it collided with the LDO once the board shrank, so only J2
    centers now and J1 is placed explicitly.
    - Boot/reset buttons rotated CCW with their pull-ups/cap moved underneath.
    - Power LED + R moved right of C3 (row south of U1).
    - Fab: include the inner copper layers (In1/In2) in the JLCPCB zip (was 2-layer
    only -- a fab from the old zip would have come out wrong).
    - Plane-stitch clearance now uses each pad's bounding-circle radius (fixes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
    [doorbell.kicad_pcb, doorbell.kicad_sch]
2026-06-07 Layout refinements, JLCPCB BOM/CPL generation, and review datasheets
    Layout (gen_pcb.py): tightened the bus-interface cluster (optos + relays beside each
    other, screw terminal right-aligned on top), relays rotated CW, relay drivers reworked
    (Q/R_pd swapped+rotated, R_g flat with the GATE pad fixed, flyback diodes moved north),
    power LED row south of U1 with equal spacing, buttons rotated + support beneath them with
    BOOT/RST silk labels, relay refdes centred on the body, J1/R_cc shifted left, C1 nudged up,
    board trimmed to ~36 mm; product name silk in the freed upper-left corner.
    JLCPCB assembly outputs:
    - kicad/jlcpcb_cpl.py: CPL (pick & place) from the PCB using each part's PAD CENTROID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
    [doorbell.kicad_pcb, doorbell.kicad_sch]
2026-06-07 Fix floating ESP32 grounds, remove the VBUS bulk cap, add GPIO8 pull-up + a pad check
    CRITICAL grounding fix: the ESP32-C3-MINI-1 had ONLY pin 1 tied to GND -- its other 21 GND
    pins (2, 11, 14, 36-48, the EPAD/pad 49, 50-53) were floating with no net. DRC never flagged
    it because a net-less pad generates no ratsnest. All 22 module GND pins now tie to GND.
    - Remove C1: a 100 uF bulk on VBUS violates USB 2.0 inrush (<=10 uF) and nothing prescribes
    it (AMS1117 needs only its 22 uF output cap; the ESP32-C3-DevKitM-1 uses ~10 uF on 5 V). C2
    (10 uF) remains as the LDO input / VBUS decoupling.
    - Add R12 (10 k) pull-up on GPIO8: a strapping pin with no internal pull, needed for reliable
    downl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
    [doorbell.kicad_pcb, doorbell.kicad_sch]
2026-06-07 Switch to low-dropout LDO, add VBUS + USB protection diodes, refine bottom layout
    Power:
    - LDO AMS1117-3.3 -> SGM2212-3.3 (low-dropout ~250mV, 800mA; LCSC C3294699). Same SOT-223-3
    footprint + pinout (GND/VOUT/VIN), so a drop-in -- and it removes the headroom concern from
    the new series Schottky. C4 22uF -> 10uF (SGM2212 wants COUT 1-10uF; matches the DevKitM-1).
    Protection diodes (per DevKitM-1 reference):
    - D4 SS14 (SMA, C2480): reverse-protection Schottky in series VBUS -> +5V. The +5V net is split
    into VBUS (raw USB, pre-Schottky: J1 power pins + D4 anode + ESD clamp rail) and +5V (post-D4).
    - D5 SRV05-4 (SOT-23-6, C7420376): USB ESD array tapping D+/D- (pins 1/3), clamp to VBUS (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
    [doorbell.kicad_pcb, doorbell.kicad_sch]
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2026-06-07 Switch K1/K2 to G6K-2F-Y-TR DC4.5 coil (LCSC C397193); reroute board
    The 5V coil's must-operate (80% = 4.0V) sat only ~0.3V under the post-Schottky
    ~4.5V +5V rail, going negative under VBUS sag. The DC4.5 coil drops must-operate
    to 3.6V, clearing pickup by ~0.7-0.9V with ~1.9V headroom below its 6.75V max coil
    voltage. Same footprint/pinout -- purely a coil/part-number change. (Review finding 2.)
    - doorbell_design.py: K1/K2 value -> G6K-2F-Y 4.5V
    - jlcpcb_files.py: K1/K2 LCSC -> C397193 (DC4.5 tape-and-reel)
    - DESIGN.md / docs/README.md / kicad/README.md: relay refs -> DC4.5 / C397193
    - regenerated schematic + re-routed board: ERC 0 err, DRC 0/0, check_pcb PASS
    [doorbell.kicad_pcb, doorbell.kicad_sch]
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2026-06-07 Unshare opto LED limiter: per-opto R_lim1/R_lim2 (fixes idle-opto reverse bias)
    The single shared 5.1k cathode->P1 limiter let a ringing channel lift the common
    cathode node ~10.8 V and reverse-bias the idle opto's LED past its 6 V VR. Split it
    into one resistor per opto so each idle cathode stays near P1. (Review finding 5.)
    - doorbell_design.py: rename R_lim -> R_lim1 (R1, OC1); add R_lim2 (R13, OC2); split
    the shared OC_CATH net into OC1_CATH / OC2_CATH; both limiters return to P1.
    - gen_pcb.py: place R_lim1 above OC1, R_lim2 above OC2.
    - Regenerated + re-routed: ERC 0 err, DRC 0/0, check_pcb PASS; BOM 35 parts
    (5.1k group now R1,R9,R10,R13).
    - DESIGN.md / kicad/README.md: document t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
    [doorbell.kicad_pcb, doorbell.kicad_sch]
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2026-06-07 Swap inner planes to In1=+3V3 / In2=GND so B.Cu references GND
    Puts the GND plane adjacent to B.Cu, where the USB D+/D- pair predominantly
    routes (~85% B.Cu). Before, B.Cu sat over the +3V3 plane, so the pair was mostly
    +3V3-referenced; now it's GND-referenced. The other signals are slow/DC and don't
    care, and +3V3 distribution is unchanged (both planes still solid). Review finding 3.
    - gen_pcb.py: add_plane()/PLANE_OF swapped; stitch vias retarget by net (through-vias,
    no geometry change). ERC 0 err, DRC 0/0, check_pcb PASS.
    - DESIGN.md / kicad/README.md: stackup now F.Cu / +3V3 / GND / B.Cu; finding 3 mitigated.
    Note: for a guaranteed clean, coupled pair, hand-route + lock D+/D- on B.C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
    [doorbell.kicad_pcb]
2026-06-07 EN reset cap 100nF -> 1µF; add ESP32 PCB best-practices review
    - C_en bumped to 1µF, Espressif's EN-RC spec value (was 100nF). Regenerated
    schematic/PCB/fab: ERC 0, DRC 0/0, 0 unconnected, check_pcb PASS.
    - Add docs/ESP32_PCB_BEST_PRACTICES.md: sourced ESP32-C3 (module) PCB
    best-practices checklist + line-by-line comparison against V4.
    - Sync DESIGN.md BOM: U2 is the SGM2212-3.3 LDO (was a stale AMS1117-3.3
    line) — matches the decisions/power-tree/review sections.
    [doorbell.kicad_pcb, doorbell.kicad_sch]
2026-06-07 Add 3 PCBA fiducials (body-aware placement, BOM/CPL-excluded)
    Three global optical reference marks (Fiducial_1mm_Mask2mm) added in
    gen_pcb.py after plane-stitching, forming an asymmetric triangle so the
    pick-and-place camera can resolve board orientation.
    Placement is body-aware: the search clears every component COURTYARD by
    >=1.4mm (not just pads), so a mark never lands under a part. An earlier
    pad-only check tucked a fiducial into the gap between J1's USB-C pad rows
    (under the connector shell); the courtyard check fixes that and the
    fiducial courtyard is kept so DRC courtyard-overlap guards regressions.
    Other gotchas handled to keep DRC 0/0:
    - FP_EXCLUDE_FROM_POS_FILES + FP_EXCLUDE_FROM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
    [doorbell.kicad_pcb, doorbell.kicad_sch]
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2026-06-07 Swap U1 to ESP32-C3-WROOM-02-N4 (Economic PCBA) + re-floorplan upper-left
    The ESP32-C3-MINI-1 is Standard-PCBA-only at JLCPCB, forcing the $25/side
    setup. The ESP32-C3-WROOM-02-N4 (LCSC C2934560) is Economic-eligible and
    the same C3 SoC, so the ESPHome config is unchanged.
    Not a drop-in: WROOM-02 is larger (18x20 vs 13.2x16.6) with a different
    pad map, so every U1 net was remapped (3V3 3->1, EN 8->2, IO4 18->3,
    IO5 19->4, IO6 20->5, IO7 21->6, IO8 22->7, IO9 23->8, USB D-/D+ 26/27->
    13/14, GND -> pins 9 + EPAD 19) and NOCONN updated to the unused WROOM-02
    GPIOs. EDGE_OVERHANG retuned to 5.9mm: antenna still overhangs the left
    edge, pins 1/18 now sit ~1.5mm inside instead of 0.5mm.
    Re-floor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
    [doorbell.kicad_pcb, doorbell.kicad_sch]
2026-06-07 Move bell sense to IO10/IO3 (opto-facing); doc + BOM update for WROOM-02
    Reassign OC1_OUT/OC2_OUT from IO6/IO7 to IO10/IO3 so they land on U1's
    north castellated row facing the optos: OC1/OC2 now route ~7mm straight
    instead of ~25mm around the module. Non-strapping pins; IO6/IO7 freed to
    No-Connect. ESPHome updated (House GPIO6->GPIO10, Apartment GPIO7->GPIO3).
    Routes 0 unrouted, DRC 0/0, check_pcb PASS.
    BOM: U1 LCSC C2838502 (MINI-1) -> C2934560 (WROOM-02-N4).
    Docs brought in line with the WROOM-02 swap:
    - DESIGN.md: GPIO map, decisions/BOM tables, floorplan, antenna overhang
    (5.9mm), and a 2026-06-08 "changes since review" addendum.
    - ORDERING.md: switched the order story to Economic P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
    [doorbell.kicad_pcb, doorbell.kicad_sch]
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2026-06-08 Add R14 (2.2k) in series with K1 door-opener bridge (WF26-faithful)
    The genuine WF26 OeT button bridges bus lines 2<->3 through R1 = 2.2 kOhm
    (confirmed by colour bands red-red-red-gold), not a dead short -- so it
    triggers the TV20/S door opener while only loading the speech pair, not
    fully shorting it. Our K1 was dead-shorting 2<->3.
    - doorbell_design.py: new R14 (R_ot, 0603 2.2k, LCSC C4190). Door-opener
    bridge re-routed K1.COM=P2, K1.NO -> R14 -> P3 (net OT_BRIDGE).
    - gen_schematic.py / gen_pcb.py: R14 placement (right of K1, below J2.P1).
    - Regenerated sch (0 ERC errors) + PCB (placed, routed, 0 DRC / 0 unconnected)
    + fab. DESIGN.md updated (pin table, K1 desc, invariant, audio note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
    [doorbell.kicad_pcb, doorbell.kicad_sch]
2026-06-08 Move all active GPIOs to U1 north row; remap relay drivers to IO20/IO10
    Bell-sense: IO10/IO3 → IO3/IO1 (pads 15/17, still north row facing optos).
    Relay drivers: IO4/IO5 (south row) → IO20/IO10 (pads 11/10, north row),
    saving ~25 mm of gate trace. IO20/U0RXD is safe as a gate driver — high-Z
    input at reset, 10 kΩ pull-down holds K1 off during boot. IO21/U0TXD stays
    N/C (ROM drives HIGH at boot). IO4/IO5/IO6/IO7 freed → No-Connect.
    doorbell-v4.yaml updated (K1→GPIO20, K2→GPIO10, OC1→GPIO3, OC2→GPIO1).
    [doorbell.kicad_pcb, doorbell.kicad_sch]
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2026-06-08 Add two-way audio path: PTT relay, session-sense, ES8388 + SM-LP-5001
    Builds clean: ERC 0 err, DRC 0/0, routes 0-unrouted, check_pcb PASS.
    - K3 wired as virtual PTT (emulates WF26 S2). Pole A: COM=P4, NC->P3
    (listen/idle, default), NO->P2 (talk). Pole B switches the codec analog
    between LIN1 (listen) and LOUT1 (talk), tracking pole A with no extra GPIO.
    Firmware must energise K2 before K3-talk (else handset S2 shorts P2<->P3).
    - OC3 session-sense opto across P2<->P5 (WF26 internal-relay coil energise) ->
    GPIO2: "can we send audio" = OC3 active AND K3 in talk.
    - ES8388 stereo codec (U3, LCSC C365736) + support net; I2S (MCLK/BCLK/WS/
    DSDIN/ASDOUT) + I2C to the C6. Isolation via Bou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
    [doorbell.kicad_pcb, doorbell.kicad_sch]
2026-06-08 Add JLCPCB CPL rotation fixes for U3/K3/Q3/OK3
    CPL-only offsets (board layout unchanged) so pick-and-place orients the
    audio-subsystem parts to match JLCPCB's library:
    - U3 (ES8388 QFN-28): -90 (clockwise)
    - K3 (G6K relay): -90, matching K1/K2
    - Q3 (2N7002 SOT-23): 180, matching Q1/Q2
    - OK3 (LTV-217 SOP-4): 180, matching OK1/OK2
    Q3/OK3 are the same footprints as already-confirmed parts; ROT_FIX is added
    to footprint orientation, so identical parts need identical offsets. Confirm
    U3 against JLCPCB's Confirm-Parts-Placement preview (only genuinely new value).
    [doorbell.kicad_pcb, doorbell.kicad_sch]
2026-06-08 Swap codec ES8388 -> ES8311 (mono); fine-pitch clearance; antenna keepout
    - Codec ES8388 -> ES8311 (mono, WQFN-20 0.4mm, LCSC C962342). Mono fits the
    half-duplex path (only one channel was ever used). Symbol+footprint+3D
    imported via easyeda2kicad into kicad/lib_audio/, registered in the project
    sym/fp-lib-tables. All 20 pins + EP used.
    - Analog: ES8311 differential OUT/MIC AC-coupled to T1 winding B; out+mic share
    the secondary, firmware mutes the idle direction. K3 pole-B audio switch
    dropped -> K3 is PTT-only (pole A), pole B spare.
    - EP grounding: deliberate no-via-in-pad exception -- a 2x2 GND via array insi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
    [doorbell.kicad_pcb, doorbell.kicad_sch]
2026-06-08 Audio/codec floorplan rework + subassembly groups (WIP: 2 unrouted)
    Layout iteration on the codec block and grouping. NOTE: the board is currently
    2 unconnected -- the flipped audio block faces I2S away from U1 and the
    autorouter won't fully close it; not fab-ready, needs follow-up.
    - Subassembly PCB_GROUPs (KiCad): MCU+boot, Power (USB-C+LDO), Power LED (own
    group), Bell sense, K1/K2/K3 relays, Audio codec. GROUPS defined in
    doorbell_design.py; created in route.py AFTER the SES import (groups on the
    board corrupt the Specctra DSN export and break the autoroute).
    - Codec cluster packed tight against U3 with each passive oriented so its
    U3-connected pad faces inward (rot convention 0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
    [doorbell.kicad_pcb, doorbell.kicad_sch]
2026-06-08 Floorplan rework: MCU/audio/power left-shift, button groups above U1, OK1↔OK3↔OK2 rename, consecutive opto/relay pins
    - Move MCU group (U1→X=12, R12, C6, C3) 6 mm left; audio group tracks via R12 anchor
    - Move power (LDO) and USB-C groups 6 mm left to match
    - Rotate BOOT/RST button groups CW, place above U1; RST silk label on right side
    - Split antenna keepout: use F.SilkS body extents for accurate 15 mm lateral clearance
    - Disable fiducials
    - Rename optos: cyclic OK1↔OK3↔OK2 / OC1↔OC3↔OC2 across design, firmware, DESIGN.md
    - Reassign U1 pads for consecutive relay drivers (18,19,20=GPIO20/21/22) and optos (21,26,27)
    - Place T1 silkscreen label centred on footprint
    - Minor compo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
    [doorbell.kicad_pcb, doorbell.kicad_sch]
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2026-06-09 K1 gate interlock via K3 pole-B; fix P4/IN_P4 net membership and docs
    - Hardware interlock: K3 spare pole-B contacts (pins 6/7) placed in series
    with Q1 gate drive (GATE1_PRE: R_g1 → K3 pin 7; GATE1: K3 pin 6 → Q1 gate).
    K1 physically cannot fire unless K3 is already energised, preventing the
    P2↔P3 short hazard via WF26 S2 strap. R_g1 moved to (13.5, 34, 90°).
    - P4/IN_P4 fix: IN_P4 = TV20/S-incoming side (J2.6 → K3 NC; OC2 and K1 COM
    sit here). P4 = WF26-handset side (J2.4 → K3 COM). J2 pinout unchanged.
    OC2 was already correct; K1 COM moved from P4 to IN_P4 so PTT remains
    functional when K3 is energised (K3 NC retains the TV20/S signal).
    [doorbell.kicad_pcb, doorbell.kicad_sch]
2026-06-09 Fix OC1 session-sense polarity: anode P5, cathode return P2
    The WF26 K1 relay coil runs P5 (feed/high) to P2 (return/low), so
    session-active is DC with P5 > P2. OC1 had anode on P2 and cathode
    returning to P5, reverse-biasing it when the session was active.
    Fix: OC1 anode = P5, cathode -> R_lim3 -> P2. Conducts when K1_WF26
    energises. R_lim3 value TBD pending bench measurement of P5-P2 voltage.
    [doorbell.kicad_pcb, doorbell.kicad_sch]
2026-06-09 Add copper thieving (solid fill) + per-layer density report to route.py
    Solid no-net zones on F.Cu and B.Cu with 0.5 mm clearance added post-SES
    so Freerouting is unaffected; ZONE_FILLER floods remaining space. Density
    report prints filled area and % of board area for all four copper layers
    after the final fill.
    [doorbell.kicad_pcb, doorbell.kicad_sch]
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2026-06-09 Fix DRC: update .dru rules, move LED1/R_led right, GND+float thieving zones
    - doorbell.kicad_dru: correct JLCPCB capability comment (0.127mm→0.10mm),
    add PTH-specific hole_clearance 0.28mm rule (vs 0.20mm for via/NPTH),
    fix DRU expression property (Attribute→Pad_Type)
    - gen_pcb.py: shift LED1 and R_led (D6/R15) right by 1.5mm to clear J2
    - route.py: replace single no-net thieving zone with two overlapping zones
    per outer layer — priority-1 GND zone fills open areas, priority-0 no-net
    zone fills remaining gaps (under ICs) with ISLAND_REMOVAL_MODE_NEVER to
    suppress isolated_copper DRC warnings
    [doorbell.kicad_pcb, doorbell.kicad_sch]
2026-06-09 Fix K1 NC open, K3 interlock pin, schematic gate wiring
    Three correctness fixes discovered through relay pinout analysis
    (G6K-2F-Y pole A: COM=3, NC=2, NO=4; pole B: COM=6, NC=7, NO=5):
    - K1 NC (pin 2) disconnected from P3: K1 de-energised was permanently
    strapping IN_P4↔P3 via its NC contact, preventing WF26 S2 from
    switching to talk when K3 was off. K1 is now a pure TX relay —
    NC open, NO=4 (P2) only connects when K1 fires (PTT).
    - K3 interlock GATE1_PRE moved from pin 7 (NC) to pin 5 (NO): the
    interlock path was inverted — K1 could always fire and was blocked
    only when K3 was on. Now open at rest, closes when K3 energises.
    - gen_schematic.py: wire_relay_driver no longer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
    [doorbell.kicad_pcb, doorbell.kicad_sch]
2026-06-09 Add DPDT polarity switches (CAS-220TB1) + opto LED reverse-clamp diodes
    Replace the six 3-pin jumper headers (JP_OC*_A/B) with three NIDEC
    CAS-220TB1 DPDT SMD slide switches (SW3/SW4/SW5, LCSC C2921541).
    A DPDT switch mechanically couples both poles, making invalid
    configurations (one pole normal, one reversed) impossible.
    Add three 1N4148W protection diodes (D7/D8/D9) anti-parallel across
    each opto LED to clamp reverse voltage to ~0.7 V; the LTV-217 LED VR
    is only 6 V and the bus can exceed that if a switch is mis-set.
    Silk: POLARITY group label, default-position tick marks (left = normal,
    matching the original direct-wired polarity for a standard TV20/S bus),
    and product name/revision me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
    [doorbell.kicad_pcb, doorbell.kicad_sch]
2026-06-09 WF26 review: fix opto clamp diode polarity, K1/K3 release guard
    - D_oc1/2/3 (1N4148W) were wired PARALLEL to the opto LEDs instead of
    anti-parallel (1N4148W pin 1 = cathode, not anode): the clamp stole the
    forward LED current, killing all three sense channels, and provided no
    reverse protection. Swapped the pins in NETS and rotated the three
    footprints 270->90 deg so the pads keep their XY positions.
    - doorbell-v4.yaml: release-order guard in doorbell_sound_state.on_press
    (the only path that de-energises K3): K1 off -> 10ms -> K3 off, so the
    K1/K3 release race (momentary P2<->P3 dead short) cannot occur; also
    keeps the HA-visible PTT switch state in sync.
    - CAS-220TB1 confirmed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
    [doorbell.kicad_pcb, doorbell.kicad_sch]
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2026-06-10 Add ngspice sims for opto sense chain; document polarity/CTR findings
    SPICE decks (kicad/sim/) verify the bell-sense margin: collector ~0.14 V
    across CTR 0.5-2.6, wrong switch position is a silent false-negative
    (clamp diverts the limiter current, LED held at ~0.7 V reverse), plus
    min/max line voltage and overvoltage cases. DESIGN.md documents the
    findings and the bring-up check. Board files from the last build run.
    [doorbell.kicad_pcb, doorbell.kicad_sch]
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2026-06-10 Embed part numbers + purposes in schematic; regroup decoupling caps
    - doorbell_design.py: new LCSC dict (single source for BOM overrides,
    was jlcpcb_files.EXTRA_LCSC) and PURPOSE dict (one-line role per part)
    - gen_schematic.py embeds hidden LCSC/Description/MPN/Datasheet fields
    on every symbol; SYMBOL_STANDIN suppresses the AMS1117 stand-in
    identity fields on U2 (its LCSC is now correctly C3294699)
    - jlcpcb_files.py derives EXTRA_LCSC from the design module
    - Schematic: C3/C6 (ESP32 decoupling) moved into the MCU group,
    C7-C10 (ES8311 supplies) into the AUDIO group, matching PCB GROUPS;
    POWER box shrunk to the LDO + its in/out caps
    - FP_OVERRIDE: add K1 (relay BOM row was missing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
    [doorbell.kicad_sch]
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2026-06-10 PCB tweaks: VBUS_F star on F1, T1 pin swaps for routing, tighter antenna keepout
    [doorbell.kicad_pcb, doorbell.kicad_sch]
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
